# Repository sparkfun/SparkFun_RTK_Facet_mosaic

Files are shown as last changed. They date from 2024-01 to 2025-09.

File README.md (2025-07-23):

SparkPNT RTK Facet mosaic
========================================

SparkPNT RTK Facet mosaic (https://www.sparkfun.com/sparkpnt-rtk-facet-mosaic.html)

[*SparkPNT RTK Facet mosaic (GPS-29688)*](https://www.sparkfun.com/sparkpnt-rtk-facet-mosaic.html)

Designed and manufactured in Boulder, Colorado, USA, and utilizing the multi-band mosaic-X5 from Septentrio, the [SparkPNT RTK Facet mosaic](https://www.sparkfun.com/sparkpnt-rtk-facet-mosaic.html) is *the* top of the line receiver for high precision geolocation and surveying needs. For basic users, it's incredibly easy to get up and running; for advanced users, the RTK Facet mosaic is a flexible and powerful tool. With just the press of a button, the RTK Facet mosaic is the fastest way to take centimeter-grade measurements. With a [subscription to the PointPerfect Flex NTRIP/RTCM service](https://www.sparkfun.com/rtk_facet_mosaic_registration) or any other corrections service, 10mm Real Time Kinematic fixes are less than a minute away. By connecting your phone to the RTK Facet mosaic over Bluetooth®, your phone or tablet can receive the NMEA output and work with most GIS software programs. This is exactly how $10,000 surveying devices have been operating for the past decade - we just made it faster, more precise, and a lot more economical.

The RTK Facet mosaic works with common GIS software for Android and iOS including SW Maps [Android](https://sparkfun.github.io/SparkFun_RTK_Firmware/gis_software/#sw-maps) / [iOS](https://apps.apple.com/us/app/sw-maps/id6444248083), [Field Genius](https://www.microsurvey.com/products/fieldgenius-for-android/), [SurvPC](https://www.carlsonsw.com/product/carlson-survce), [Survey Master](https://docs.sparkfun.com/SparkFun_RTK_Firmware/gis_software/#survey-master), [Vespucci](https://play.google.com/store/apps/details?id=de.blau.android&hl=en_US&gl=US), [QGIS](https://qgis.org/), [QField](https://docs.qfield.org/get-started/), and any GIS software that supports NMEA over Bluetooth.

Under the hood of the SparkPNT RTK Facet mosaic is an ESP32-WROVER-E connected to a mosaic-X5 GNSS multi-band receiver, and a variety of peripheral hardware (LiPo fuel gauge, microSD, etc). Additionally, housed under the dome of the RTK Facet mosaic is a surveyor grade L1/L2/L5 antenna. This antenna is a unique combination of elements designed to receive the GNSS signals (L1/L2/L5). The RTK Facet mosaic is programmed in Arduino and can be tailored by you to fit whatever your needs may be.

This device can be used in five modes:

- GNSS Positioning (~30cm accuracy) - also known as **Rover**
- GNSS Positioning with RTK (1.4cm accuracy) - also known as **Rover with RTK Fix**
- GNSS **Base Station**
- GNSS **Base Station NTRIP Server**

At *Power On* the device will enter **Rover** or **Base** mode; whichever state the device was in at the last power down. When the POWER/SETUP button is pressed momentarily, a menu is presented to change the RTK Facet mosaic from *Rover to Base mode* or vice-versa. The display will indicate the change with a small car *(Rover)* or flag *(Base)* icon.

In **Rover mode** the RTK Facet mosaic will receive `L1`, `L2`, and `L5` GNSS signals from the four constellations (GPS, GLONASS, Galileo, and BeiDou) and calculate the position based on these signals. Similar to a standard grade GPS receiver, the RTK Facet mosaic will output industry standard NMEA sentences at 4Hz and broadcast them over any paired Bluetooth® device. The end user will need to parse the NMEA sentences using commonly available mobile apps, GIS products, or embedded devices (there are many open source libraries). Unlike standard grade GPS receivers that have **2500mm** accuracy, the accuracy in this mode is approximately **300mm** horizontal positional accuracy. When RTCM correction data is sent over Bluetooth® or into the radio port, the device will automatically enter Positioning with RTK mode. In this mode RTK Facet mosaic will receive `L1`/`L2`/`L5` signals from the antenna and correction data from a base station. The receiver will quickly (within a second) obtain an RTK float, then fix. The NMEA sentences will have increased accuracy of 10mm horizontal and 10mm vertical accuracy. The RTCM correction data is most easily obtained over the Internet using a free app on your phone (see our SW Maps *([Android](http://docs.sparkfun.com/SparkFun_RTK_Everywhere_Firmware/gis_software_android/#sw-maps)/[iOS](http://docs.sparkfun.com/SparkFun_RTK_Everywhere_Firmware/gis_software_ios/#sw-maps))* or [Lefebure NTRIP](http://docs.sparkfun.com/SparkFun_RTK_Everywhere_Firmware/gis_software_android/#lefebure) instructions) and sent over Bluetooth® to the RTK Facet mosaic. However, RTCM correction data can also be received over an external cellular or radio link from a 2nd RTK Torch, Postcard, Facet mosaic, Surveyor, Express, etc. that is setup as a base station.

In **Base mode** the device will enter Base Station mode. This is used when the device is mounted to a fixed position (like a tripod or roof). The RTK Facet mosaic will initiate a survey. After 60 to 120 seconds the survey will complete and the RTK Facet mosaic will begin transmitting RTCM correction data out the radio port. A base is often used in conjunction with a second RTK Facet mosaic (or RTK Surveyor, Express, Express Plus, etc) unit set to *Rover* to obtain the 10mm accuracy. Said differently, the Base sits still and sends correction data to the Rover, so that the Rover can output really accurate position data for its location.

In addition to supplying position data, the RTK Facet mosaic is capable of logging NMEA, RAWX, and SFRBX for post processing making it ideal for research and advanced positioning applications.

The RTK Facet mosaic is an open source hardware product meaning you can fully obtain, see, and even modify the electrical and mechanical design files. This allows for easier maintenance and repair over time.

The SparkPNT RTK Facet mosaic kit includes everything you need: the enclosed device, thread adapter, charger, data cables, and carrying case. It does **NOT** include a [surveying pole](https://www.sparkfun.com/telescopic-surveying-pole.html) *(any additional items will need to be purchased separately)*.

> [!IMPORTANT]
> The SparkPNT RTK Facet mosaic is not designed for permanent outdoor mounting. Please use the [RTK mosaic-X5](https://www.sparkfun.com/sparkfun-rtk-mosaic-x5.html) or the [RTK Reference Station](https://www.sparkfun.com/products/22429) that is located inside or protected from the elements. Or, for a DIY solution, the [ESP32](https://www.sparkfun.com/sparkfun-thing-plus-esp32-wroom-micro-b.html) attached to our [ZED-F9P breakout](https://www.sparkfun.com/sparkfun-gps-rtk-sma-breakout-zed-f9p-qwiic.html) is a great way to go. See our [How to Build a DIY GNSS Reference Station](https://learn.sparkfun.com/tutorials/how-to-build-a-diy-gnss-reference-station) tutorial for more information.

> [!NOTE]
> The [RTK Everywhere firmware](https://github.com/sparkfun/SparkFun_RTK_Everywhere_Firmware) is open-source, so users can obtain, check, and even modify the device's functionality. This allows for easier feature expansion, bug maintenance, and longer device longevity.

Documentation
--------------

- **[Hookup Guide (mkdocs)](http://docs.sparkfun.com/SparkFun_RTK_Facet_mosaic/)** - The hookup guide for the SparkPNT RTK Facet mosaic hosted by GitHub pages.<br>
   
- [User Manual - RTK Everywhere Firmware](https://docs.sparkfun.com/SparkFun_RTK_Everywhere_Firmware/) - Documentation for the [RTK Everywhere firmware](https://github.com/sparkfun/SparkFun_RTK_Everywhere_Firmware)

*Need to download or print our hookup guide?*

- [Print *(Print to PDF)* from Single-Page View](http://docs.sparkfun.com/SparkFun_RTK_Facet_mosaic/print_view)

Repository Contents
-------------------

- **[/docs](/docs/)** - Online documentation files
	- [assets](/docs/assets/) - Assets files
		- [3d_model](/docs/assets/3d_model/) - Files for the 3D models
			- [3D CAD Models](/docs/assets/3d_model/step_files.zip) (.step)
		- [board_files](/docs/assets/board_files/) - Files for the product design
			- [KiCad Design Files](/docs/assets/board_files/kicad_files.zip) (.zip)
			- [Schematics](/docs/assets/board_files/schematics.zip) (.pdf)
			<!-- - [Dimensions](/docs/assets/board_files/dimensions.pdf) (.pdf) -->
		- [component_documentation](/docs/assets/component_documentation/) - Datasheets for hardware components
		- [img/hookup_guide/](/docs/assets/img/hookup_guide/) - Images for hookup guide documentation
- **[/Enclosure](/Enclosure/)** - CAD model for an enclosure
- **[/Hardware](/Hardware/)** - Hardware design files (.brd, .sch)
	- **[/Production](/Production/)** - Production files

Product Variants
----------------

- [GPS-24903](https://www.sparkfun.com/sparkpnt-rtk-facet-mosaic-l-band.html) - v1.0, Initial Release
- [GPS-29688](https://www.sparkfun.com/sparkpnt-rtk-facet-mosaic.html) - Rename the product to remove "L-Band" from the name. This is due to u-blox's choice to discontinue the L-Band service to North America starting on December 31st, 2025.

- Facet Product Line
	- [GPS-20000](https://www.sparkfun.com/sparkfun-rtk-facet-l-band.html) - SparkFun RTK Facet L-Band
	- [GPS-19984](https://www.sparkfun.com/sparkfun-rtk-facet.html) - SparkFun RTK Facet
	- [GPS-19029](https://www.sparkfun.com/products/19029) - SparkFun RTK Facet *(Initial Release)*
- mosaic-`XX` GNSS Module
	- [GPS-26289](https://www.sparkfun.com/products/26289) - SparkPNT GNSS Disciplined Oscillator
	- [GPS-23748](https://www.sparkfun.com/sparkfun-rtk-mosaic-x5.html) - SparkFun RTK mosaic-X5
	- [GPS-23088](https://www.sparkfun.com/sparkfun-triband-gnss-rtk-breakout-mosaic-x5.html) - SparkFun Triband GNSS RTK Breakout - mosaic-X5

License Information
-------------------

This product is ***open source***!

Please review the [`LICENSE.md`](./LICENSE.md) file for license information.

If you have any questions or concerns about licensing, please contact technical support on our [SparkFun forums](https://forum.sparkfun.com/viewforum.php?f=152).

Distributed as-is; no warranty is given.

- Your friends at SparkPNT.

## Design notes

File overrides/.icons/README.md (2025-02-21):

.icons directory
====================
This folder should contain branding logos for the product documentation

## General Images
- `sfe.svg` - SparkFun flame logo
- `kicad-primary.svg` - Full KiCad logo

## Directory
- `logo` - Other available logos

## SVG Optimizer
- [Remove meta data from svg](https://jakearchibald.github.io/svgomg/)

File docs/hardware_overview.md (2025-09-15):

---
icon: material/cog
---

The RTK Facet mosaic is a fully enclosed and pre-programmed device. There are very few things to worry about or configure, but we will cover the basics here.

## :material-folder-cog: Design Files
The design of the SparkPNT RTK Facet mosaic is similar to previous generations in our line Facet line of products. However, we have made some modifications to the design to enhance the durability of this product. The PCB design features three separate board components:

- A central board that hosts primary components of the RTK Facet mosaic, such as the ESP32-WROVER-E, mosaic-X5, etc.
- A peripheral board that provides connections to the RTK Facet mosaic
- A display board that is the primary interface for the RTK Facet mosaic

<!-- Import the component -->
<script type="module" src="https://ajax.googleapis.com/ajax/libs/model-viewer/3.5.0/model-viewer.min.js"></script>

<div class="grid cards desc" markdown>

-   Design Files

	---

	- :kicad-primary:{ .enlarge-logo }
		- :material-folder-zip: [Schematics](./assets/board_files/schematics.zip)
			- :fontawesome-solid-file-pdf: [Connector Board](./assets/board_files/schematic-connector_board.pdf)
			- :fontawesome-solid-file-pdf: [Display Board](./assets/board_files/schematic-display_board.pdf)
			- :fontawesome-solid-file-pdf: [Main Board](./assets/board_files/schematic-main_board.pdf)
		- :material-folder-zip: [KiCad Files](./assets/board_files/kicad_files.zip)
			- :material-folder-zip: [Connector Board](./assets/board_files/kicad_files-connector_board.zip)
			- :material-folder-zip: [Display Board](./assets/board_files/kicad_files-display_board.zip)
			- :material-folder-zip: [Main Board](./assets/board_files/kicad_files-main_board.zip)
	- :material-folder-zip: [STEP Files](./assets/3d_model/step_files.zip)
		- :material-cube-outline: [Connector Board](./assets/3d_model/connector_board.step)
		- :material-cube-outline: [Display Board](./assets/3d_model/display_board.step)
		- :material-cube-outline: [Main Board](./assets/3d_model/main_board.step)
	<!-- - :material-rotate-3d: [STEP File](./assets/3d_model/cad_model.zip) -->
	<!-- - :fontawesome-solid-file-pdf: [Board Dimensions](./assets/board_files/dimensions.pdf) -->

-   <!-- Boxes in tabs -->

	=== "Connector Board"
		<article style="margin: auto;" markdown>
		<model-viewer src="../assets/3d_model/connector_board.glb" poster="../assets/3d_model/poster-connector_board.jpeg" camera-controls tone-mapping="neutral" poster="poster.jpeg" shadow-intensity="1.35" exposure="0.6" shadow-softness="0.8" environment-image="legacy" camera-orbit="0.0004711deg 90.01deg 108.5m" field-of-view="25.11deg" style="width: 100%; height: 450px;">
		</model-viewer>
		</article>

	=== "Display Board"
		<article style="margin: auto;" markdown>
		<model-viewer src="../assets/3d_model/display_board.glb" poster="../assets/3d_model/poster-display_board.jpeg" camera-controls tone-mapping="neutral" poster="poster.jpeg" shadow-intensity="1.35" environment-image="legacy" exposure="0.6" shadow-softness="0.8" camera-orbit="-0.0002197deg 89.6deg 101.9m" field-of-view="25.11deg" style="width: 100%; height: 450px;">
		</model-viewer>
		</article>

	=== "Main Board"
		<article style="margin: auto;" markdown>
		<model-viewer src="../assets/3d_model/main_board.glb" poster="../assets/3d_model/poster-main_board.jpeg" camera-controls tone-mapping="neutral" poster="poster.jpeg" camera-controls tone-mapping="neutral" poster="poster.jpeg" shadow-intensity="1.35" camera-orbit="0deg 90deg 110m" field-of-view="25.11deg" environment-image="legacy" exposure="0.6" shadow-softness="0.8" style="width: 100%; height: 450px;">
		</model-viewer>
		</article>

	??? tip "Need Dimensions?"
		For the board dimensions, users can download the [KiCad files](./assets/board_files/kicad_files.zip) for these board. These files can be opened in KiCad and measurements can be made with the measuring tool.

		!!! info ":octicons-download-16:{ .heart } KiCad - Free Download!"
			KiCad is free, open-source [CAD]("computer-aided design") program for electronics. Click on the button below to download their software. *(\*Users can find out more information about KiCad from their [website](https://www.kicad.org/).)*

			<article style="text-align: center;" markdown>
			[Download :kicad-primary:{ .enlarge-logo }](https://www.kicad.org/download/ "Go to downloads page"){ .md-button .md-button--primary width="250px" }
			</article>

		??? info ":straight_ruler: Measuring Tool"
			This video demonstrates how to utilize the dimensions tool in KiCad, to include additional measurements:

			<article class="video-500px" style="text-align: center; margin: auto;" markdown>
			<iframe src="https://www.youtube.com/embed/-eXuD8pkCYw" title="KiCad Dimension Tool" frameborder="0" allow="accelerometer; autoplay; clipboard-write; encrypted-media; gyroscope; picture-in-picture" allowfullscreen></iframe>

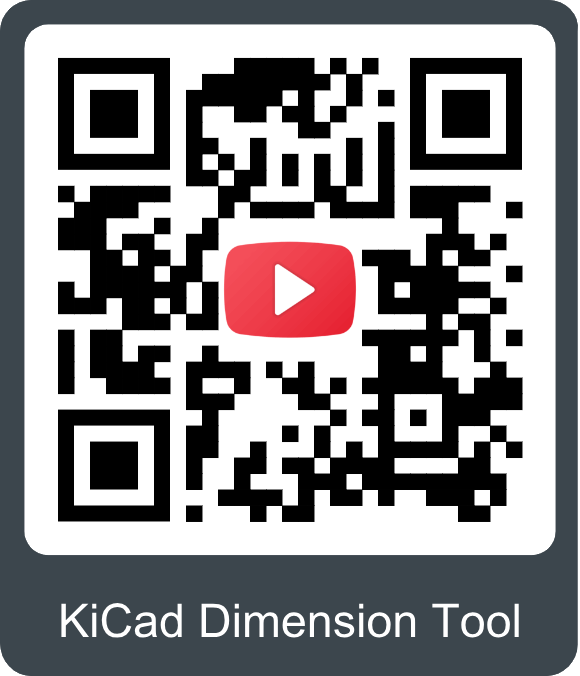
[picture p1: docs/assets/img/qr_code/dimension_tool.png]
QR code to play video
			
			</article>

</div>

## Replacement Parts

??? abstract "Kit Parts"
	<div class="grid cards" markdown>

	-   <a href="https://www.sparkfun.com/sparkpnt-rtk-facet-ruggedized-hardcase.html">
		<figure markdown>
		Product Thumbnail
		</figure>

		---

		**SparkPNT RTK Facet Ruggedized Hardcase**<br>
		PRT-27115</a>

	-   <a href="https://www.sparkfun.com/antenna-thread-adapter-1-4in-to-5-8in.html">
		<figure markdown>
		Product Thumbnail
		</figure>

		---

		**Antenna Thread Adapter - 1/4in. to 5/8in.**<br>
		PRT-17546</a>

	-   <a href="https://www.sparkfun.com/jst-ghr-04v-to-jst-ghr-06v-cable-1-25mm-pitch.html">
		<figure markdown>
		Product Thumbnail
		</figure>

		---

		**JST-GHR-04V to JST-GHR-06V Cable - 1.25mm pitch**<br>
		CAB-17239</a>

	-   <a href="https://www.sparkfun.com/breadboard-to-jst-ghr-04v-cable-4-pin-x-1-25mm-pitch.html">
		<figure markdown>
		Product Thumbnail
		</figure>

		---

		**Breadboard to JST-GHR-04V Cable - 4-Pin x 1.25mm Pitch**<br>
		CAB-17240</a>

	-   <a href="https://www.sparkfun.com/usb-c-to-usb-c-silicone-power-charging-cable-3m.html">
		<figure markdown>
		Product Thumbnail
		</figure>

		---

		**USB-A to USB-C Cable - 3m (Flexible Silicone)**<br>
		CAB-24060</a>

	-   <a href="https://www.sparkfun.com/usb-a-and-c-power-delivery-pd-wall-adapter-65w.html">
		<figure markdown>
		Product Thumbnail
		</figure>

		---

		**USB A and C Power Delivery (PD) Wall Adapter - 65W**<br>
		TOL-24059</a>

	</div>

??? abstract "Internal Components"
	- M2.2-0.98 x 10mm Thread Forming Screws - Phillips Head
	- M3-1.34 x 10mm Thread Forming Screws - Phillips Head

## Power/Setup Button

<figure markdown>
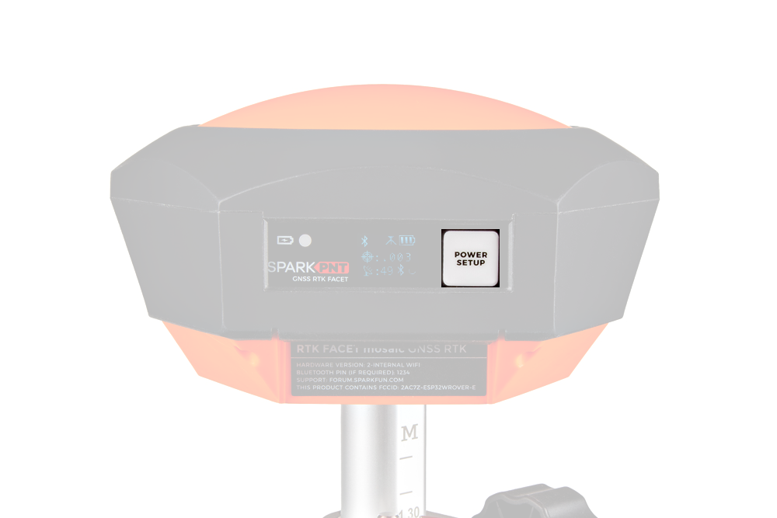
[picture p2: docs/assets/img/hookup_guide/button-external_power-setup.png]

<figcaption markdown>
</figcaption>
The ++"POWER/SETUP"++ button on the front of the RTK Facet mosaic.
</figure>

The RTK Facet mosaic has a ++"POWER/SETUP"++ button to turn the device on/off or for in-field configuration changes.

- Press and hold the button down, to power the RTK Facet mosaic `ON` or `OFF`.
- Short presses of the button will cause the RTK Facet mosaic to change modes. This device can be used in five modes:
	- **Rover**
		- GNSS Positioning (~30cm accuracy) - also known as **Rover**
		- GNSS Positioning with RTK (1.4cm accuracy) - also known as **Rover** *with RTK Fix*
	- **Base**
		- GNSS **Base** Station
		- GNSS **Base** Station *as NTRIP Server*

### Power Switch

<figure markdown>
RTK Facet mosaic startup display with firmware version number (https://cdn.sparkfun.com/assets/learn_tutorials/2/5/8/3/SparkFun_RTK_Facet_L-Band_Boot.jpg)
<figcaption markdown>
The splash screen of RTK Facet mosaic display showing the firmware version number and the device powering off.
</figcaption>
</figure>

The Power button turns the unit on or off:

- Press and hold the power button until the display illuminates.
- Press and hold the power button at any time to turn the unit off.

#### Battery Power

<figure markdown>
RTK Facet mosaic showing the battery level (https://cdn.sparkfun.com/assets/learn_tutorials/1/8/5/7/SparkFun_RTK_Express_-_Display_-_Rover_Fixed.jpg)
<figcaption markdown>
RTK Facet mosaic display, showing the battery level.
</figcaption>
</figure>

The RTK Facet mosaic has a large, built-in 6000mAh lithium polymer battery that will enable over **25 hours** of field use between charging. If more time is needed a common USB power bank can be attached boosting the field time to any amount needed.

!!! info
	For more information, please refer to the [**Internal Batter** section](./hardware_overview.md/#internal-battery)

#### Charge LED

<figure markdown>
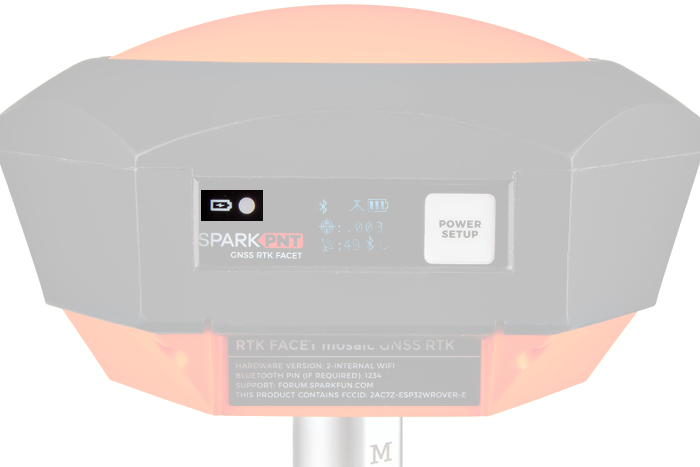
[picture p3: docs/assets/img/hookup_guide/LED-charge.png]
RTK Facet mosaic Charge LED

<figcaption markdown>
Charge LED indicator on the RTK Facet mosaic.
</figcaption>
</figure>

The Charge LED is located on the front face. It will illuminate any time there is an external power source and will turn off when the internal battery is charged. With the unit fully powered down, charging takes approximately **6 hours** from a 1A wall supply or **12 hours** from a standard USB port. The RTK Facet mosaic can run while being charged but it increases the charge time. Using an external USB battery bank to run the device for extended periods or running the device on a permanent wall power source is supported.

### Operation Modes

At *Power On* the device will enter **Rover** or **Base** mode; whichever state the device was in at the last power down. When the ++"POWER/SETUP"++ button is pressed momentarily, a menu is presented to change the RTK Facet mosaic from **Rover** to **Base** mode or vice-versa. The display will indicate the change with a small car :material-van-utility: *(Rover)* or flag :material-flag-checkered: *(Base)* icon.

!!! info "**Rover** Mode"
	In **Rover** mode the RTK Facet mosaic will receive `L1`, `L2`, and `L5` GNSS signals from the four constellations (GPS, GLONASS, Galileo, and BeiDou) and calculate the position based on these signals. Similar to a standard grade GPS receiver, the RTK Facet mosaic will output industry standard NMEA sentences at 4Hz and broadcast them over any paired Bluetooth® device. The end user will need to parse the NMEA sentences using commonly available mobile apps, GIS products, or embedded devices (there are many open source libraries). Unlike standard grade GPS receivers that have **2500mm** accuracy, the accuracy in this mode is approximately **300mm** horizontal positional accuracy.

	- *w/ RTK Fix*

		:	If the device is in **Rover** mode and RTCM correction data is sent over Bluetooth® or into the radio port, the device will automatically enter Positioning with RTK mode. In this mode RTK Facet mosaic will receive `L1`/`L2`/`L5` signals from the antenna; and correction data from a base station. The receiver will quickly (within a second) obtain an RTK float, then fix. The NMEA sentences will have increased accuracy of **10mm** horizontal and **10mm** vertical accuracy.

			1. The RTCM correction data is most easily obtained over the Internet using a free app on your phone (see our SW Maps *([Android](http://docs.sparkfun.com/SparkFun_RTK_Everywhere_Firmware/gis_software_android/#sw-maps)/[iOS](http://docs.sparkfun.com/SparkFun_RTK_Everywhere_Firmware/gis_software_ios/#sw-maps))* or [Lefebure NTRIP](http://docs.sparkfun.com/SparkFun_RTK_Everywhere_Firmware/gis_software_android/#lefebure) instructions) and sent over Bluetooth® to the RTK Facet mosaic.
			2. The RTCM correction data can also be received over an external cellular or radio link from a 2nd RTK Facet, Surveyor, Express, etc. that is setup as a base station.

!!! info "**Base** Mode"
	In **Base** mode the device will enter Base Station mode. This is used when the device is mounted to a fixed position (like a tripod or roof). The RTK Facet mosaic will initiate a survey. After 60 to 120 seconds the survey will complete and the RTK Facet mosaic will begin transmitting RTCM correction data out the radio port. A base is often used in conjunction with a second RTK Facet mosaic (or RTK Surveyor, Express, Express Plus, etc) unit set to *Rover* to obtain the **10mm** accuracy. Said differently, the Base sits still and sends correction data to the Rover; so that the Rover can calculate a really accurate position.

## Connectors

<figure markdown>
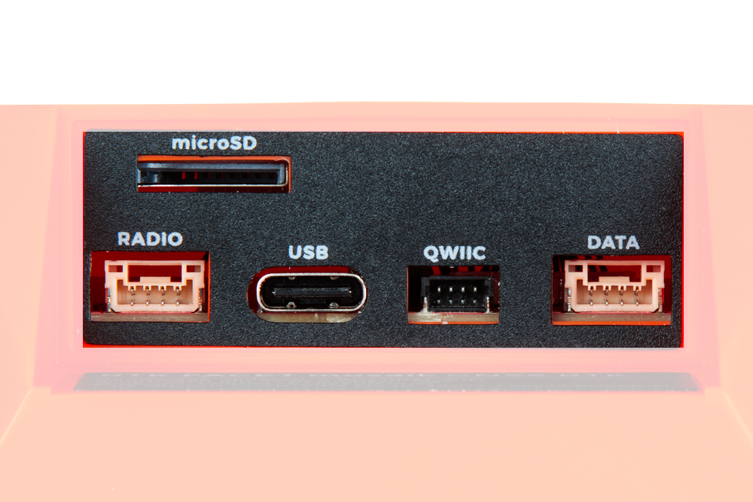
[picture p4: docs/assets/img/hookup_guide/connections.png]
RTK Facet mosaic Connectors

<figcaption markdown>
The SparkFun RTK Facet mosaic connectors shown with the dust cover removed.
</figcaption>
</figure>

There are a variety of connectors protected under a dust flap.

### USB

<figure markdown>
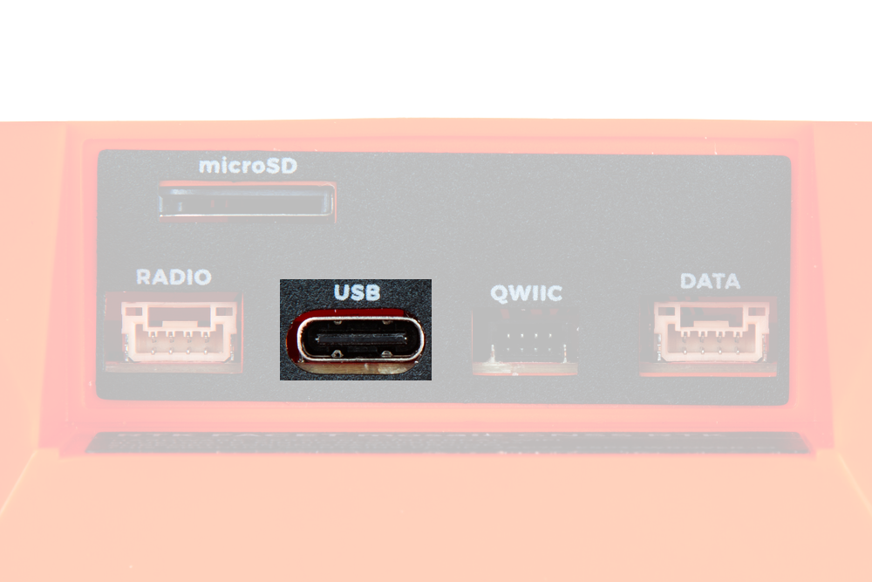
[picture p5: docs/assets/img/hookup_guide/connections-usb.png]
RTK Facet mosaic USB-C Connector

<figcaption markdown>
</figcaption>
</figure>

This USB-C connector is used for four purposes:

* Charging the device
* Configuring the RTK Facet mosaic, and reprogramming the ESP32
* Configuring or updating the firmware of the mosaic-X5 *(as needed)*

There is a USB hub built into the RTK Facet mosaic. When you attach the device to your computer it will enumerate as two COM ports. In the mosaic-X5 firmware, these are named the _USB1_ and _USB2_ COM ports.

<figure markdown>
Two COM ports from one USB device (https://cdn.sparkfun.com/assets/learn_tutorials/2/5/8/3/SparkFun_RTK_Facet_L-Band_Ports.jpg)
<figcaption markdown>
</figcaption>
</figure>

In the image above, the `USB-SERIAL CH340` is the ESP32 and the `USB Serial Device` is the mosaic-X5.

??? tip "Tip - USB Drivers"
	#### CH340 UART Converter
	The CH340 serial-to-USB converter allows users to interface with the ESP32-WROVER-E module through the USB-C connector. To utilize the CH340, users may need to install a USB driver, which can be downloaded from the [manufacturer website](https://www.wch-ic.com/search?q=CH342&t=downloads).

	<div class="grid cards" align="center" markdown>

	-   :material-microsoft-windows: **Windows**

		---

		[:octicons-download-16:{ .heart } Download Page for `CH341SER.EXE`](https://www.wch-ic.com/downloads/CH341SER_EXE.html){ .md-button .md-button--primary target="blank" }

	-   :material-apple: **MacOS**

		---

		[:octicons-download-16:{ .heart } Download Page for `CH34XSER_MAC.ZIP`](https://www.wch-ic.com/downloads/CH34XSER_MAC_ZIP.html){ .md-button .md-button--primary target="blank" }

	</div>

	!!! info ":simple-linux: Linux"
		A USB driver should not be required for most Linux based operating systems; the standard Linux CDC-ACM driver is usually sufficient. However, if necessary, users can try the USB driver below:

		<article style="text-align: center;" markdown>
		[:octicons-download-16:{ .heart } Download Page for `CH341SER_LINUX.ZIP`](https://www.wch-ic.com/downloads/CH341SER_LINUX_ZIP.html){ .md-button .md-button--primary target="blank" }
		</article>

	---

	#### mosaic-X5
	On Windows computers, a USB driver is required to recognize and interact with the mosaic-X5 module through the USB interface.

	<div class="grid cards" markdown>

	-   <article style="text-align: center;" markdown>
		:material-microsoft-windows: **Windows**
		</article>

		---

		The USB driver necessary to recognize and interact with the mosaic-X5 module through the USB interface, can be installed through two methods:

		<article class="annotate" markdown>

		- [RxTools Software Suite](./software_overview.md/#rxtools-software-suite) (1)
		- mosaic-X5 GNSS Receiver Module (2)

		</article>

		1. The driver is installed during the [installation process](./software_overview.md/#rxtools-software-suite).
		2. The installation file for the Windows USB driver will be available from the mass-storage device when the board is initially connected to the computer.

		??? tip "Having Trouble?"
			For users who are having trouble installing the USB driver, we have an archived version *(v3.0.2)* of the installation file. Users can download [**version 3.0.2**](https://docs.sparkfun.com/SparkFun_GNSS_mosaic-X5/assets/component_documentation/driver/USB_driver_3_0_2_Installer.exe) of the driver, by clicking on the button below.

			<article style="text-align: center;" markdown>
			[:octicons-download-16:{ .heart } Download USB Driver *(v3.0.2)*](https://docs.sparkfun.com/SparkFun_GNSS_mosaic-X5/assets/component_documentation/driver/USB_driver_3_0_2_Installer.exe){ .md-button .md-button--primary target="blank" }
			</article>

			!!! note "Latest Driver"
				This driver version was archived at the time that the [mosaic-X5 hookup guide](https://docs.sparkfun.com/SparkFun_GNSS_mosaic-X5/) was written. *Please do not request for the file to be updated.*

				For the latest USB driver from Septentrio, please install their driver through the [RxTools software suite](./software_overview.md/#rxtools-software-suite).

	</div>

	!!! info ":simple-linux: Linux"
		On Linux, the standard Linux CDC-ACM driver is suitable for the mosaic-X5 module.

Configuring the RTK Facet mosaic can be done over the *USB-Serial CH340* COM port via serial text menu. Various debug messages are printed to this port at **115200bps** and a serial menu can be opened to configure advanced settings. The mosaic-X5 can be configured over the *USB Serial Device* port using [web interface](./software_overview.md/#web-interface). It's not necessary in normal operation but is handy for tailoring the receiver to specific applications.

### RADIO

<figure markdown>
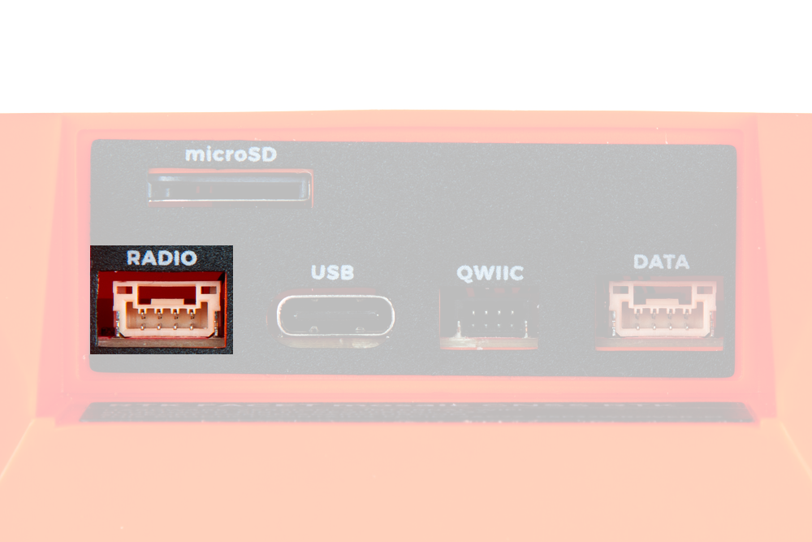
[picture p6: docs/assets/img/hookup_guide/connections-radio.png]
RTK Facet mosaic Radio Connector

<figcaption markdown>
</figcaption>
</figure>

This port is used when an external cellular or radio link is needed. Internally, it is routed to the mosaic-X5 **COM2** UART port. The baud rate is configurable; the default is **57600** baud. This port is *not* used if you transfer RTCM from your phone to the RTK Facet mosaic over Bluetooth.

This 4-pin JST connector can be used to allow RTCM correction data to flow into the device when it is acting as a **Rover** or out of the device when it is acting as a **Base**. The connector is a 4-pin locking 1.25mm JST SMD connector (1). The RTK Facet mosaic comes with a cable to interface to this connector, but [additional cables](https://www.sparkfun.com/products/17239) can be purchased separately.
{ .annotate }

1. 
	- SMD board connector
		- **part#:** SM04B-GHS-TB
	- Mating cable connector
		- **part#:** GHR-04V-S

You will most likely connect one of our [Serial Telemetry Radios](https://www.sparkfun.com/products/19032) to this port, if you don't have access to a correction source on the internet. The pinout is **3.5-5.5V**/`TX`/`RX`/`GND` from left to right as pictured. **3.5V to 5.5V** is provided by this connector to power a radio with a voltage that depends on the power source. If USB is connected to the RTK Facet mosaic then voltage on this port will be **5V** (+/-10%). If running off of the internal battery then voltage on this port will vary with the battery voltage (**3.5V** to **4.2V** depending on the state of charge). This port is capable of sourcing up to **600mA** and is protected by a PTC (resettable fuse). This port should not be connected to a power source.

### DATA

<figure markdown>
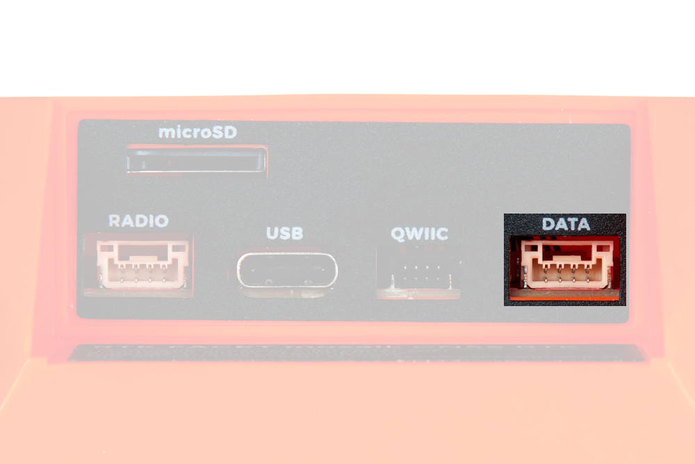
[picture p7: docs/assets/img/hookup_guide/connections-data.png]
RTK Facet mosaic Data Port

<figcaption markdown>
</figcaption>
</figure>

This port is used when an external system is connected such as a rover, car, timing equipment, camera triggers, etc. This port is *not* used if you transfer NMEA positional data to your phone from the RTK Facet mosaic over Bluetooth.

This 4-pin JST connector is used to output and input a variety of data to the RTK Facet mosaic. The connector is a 4-pin locking 1.25mm JST SMD connector (1). The RTK Facet mosaic comes with a cable to interface to this connector, but [additional cables](https://www.sparkfun.com/products/17240) can be purchased separately.
{ .annotate }

1. 
	- SMD board connector
		- **part#:** SM04B-GHS-TB
	- Mating cable connector
		- **part#:** GHR-04V-S

Internally, the Data connector is connected to a digital mux allowing one of four software selectable setups. See the [Ports Menu](https://docs.sparkfun.com/SparkFun_RTK_Firmware/menu_ports/) for a description of each option.:

- **NMEA** - The `TX` pin outputs any enabled messages (NMEA and RTCM) at a default of **230400** baud (configurable 9600 to 921600bps). The `RX` pin can receive RTCM messages for an RTK fix. Internally, `TX` and `RX` are routed to the mosaic-X5 **COM3** UART port.
- **PPS/Trigger** - The `TX` pin outputs the pulse-per-second signal that is accurate to 30ns RMS. The `RX` pin is connected to the `EVENTA` pin on the mosaic-X5, allowing for events to be measured with incredibly accurate nano-second resolution. Useful for things like audio triangulation.
- **I^2^C** - The `TX` pin operates as `SCL`, `RX` pin as `SDA` on the I^2^C bus. This allows additional sensors to be connected to the I2C bus.
- **GPIO** - The `TX` pin operates as a DAC capable `GPIO 21` on the ESP32. The `RX` pin operates as a ADC capable input (`GPIO39`) on the ESP32. This is useful for custom applications.

Most applications do not need to utilize this port and will send the NMEA position data over Bluetooth. This port can be useful for sending position data to an embedded microcontroller or single board computer. The pinout is **3.3V**/`TX`/`RX`/`GND`. **3.3V** from left to right as pictured, which is provided by this connector to power a remote device if needed. While the port is capable of sourcing up to **600mA**, we do not recommend more than **300mA**. This port should not be connected to a power source.

### microSD

<figure markdown>
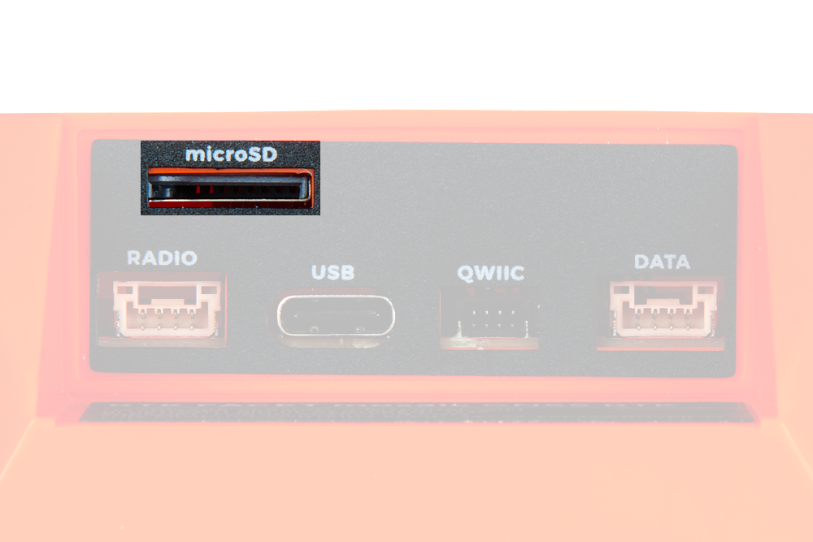
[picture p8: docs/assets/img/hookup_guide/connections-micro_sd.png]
RTK Facet mosaic microSD connector

</figcaption>
</figure>

This slot accepts standard microSD cards up to 32GB formatted for `FAT32`.

The following messages are supported for logging:

<div class="grid" style="grid-template-columns: repeat(auto-fit,minmax(8rem,1fr));" markdown>

<div markdown>
- NMEA-ALM
- NMEA-AVR
- NMEA-DTM
- NMEA-GBS
- NMEA-GFA
- NMEA-GGA
- NMEA-GGK
- NMEA-GGQ
- NMEA-GLL
- NMEA-GMP
- NMEA-GNS
- NMEA-GRS
- NMEA-GSA
- NMEA-GST
- NMEA-GSV
- NMEA-HDT
- NMEA-HRP
- NMEA-LLK
- NMEA-LLQ
- NMEA-RBD
</div>

<div markdown>
- NMEA-RBP
- NMEA-RBV
- NMEA-RMC
- NMEA-ROT
- NMEA-SNC
- NMEA-TFM
- NMEA-THS
- NMEA-TXTbase
- NMEA-VTG
- NMEA-ZDA
- RTCM3-1001
- RTCM3-1002
- RTCM3-1003
- RTCM3-1004
- RTCM3-1005
- RTCM3-1006
- RTCM3-1007
- RTCM3-1108
- RTCM3-1009
- RTCM3-1010
</div>

<div markdown>
- RTCM3-1011
- RTCM3-1012
- RTCM3-1013
- RTCM3-1019
- RTCM3-1020
- RTCM3-1029
- RTCM3-1033
- RTCM3-1042
- RTCM3-1044
- RTCM3-1045
- RTCM3-1046
- MSM1
- MSM2
- MSM3
- MSM4
- MSM5
- MSM6
- MSM7
- RTCM3-1230
</div>

</div>

### Qwiic

<figure markdown>
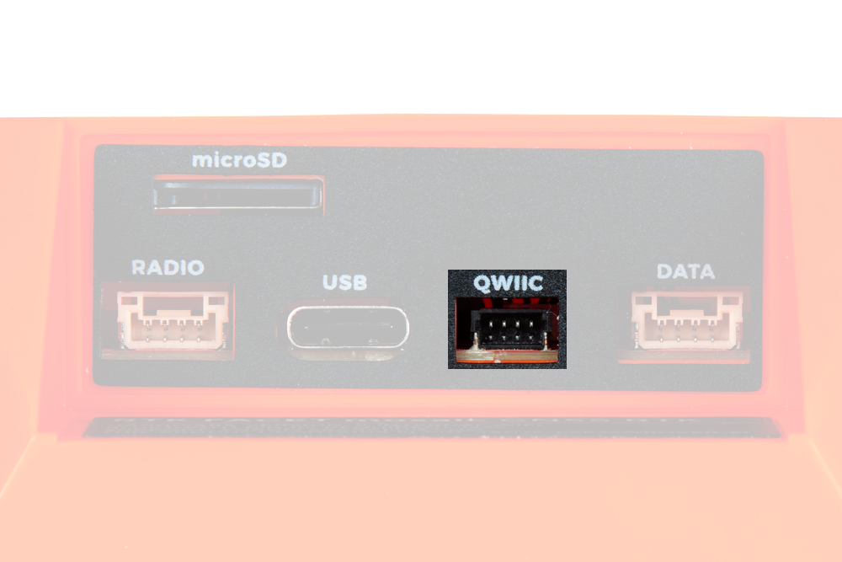
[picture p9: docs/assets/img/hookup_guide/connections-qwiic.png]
RTK Facet mosaic Qwiic connector

<figcaption markdown>
</figcaption>
</figure>

This 4-pin [Qwiic connector](https://www.sparkfun.com/qwiic) exposes the I^2^C bus of the ESP32-WROVER-E module. Currently, there is no firmware support for adding I^2^C devices to the RTK Facet mosaic, but support may be added in the future.

### Antenna

<figure markdown>
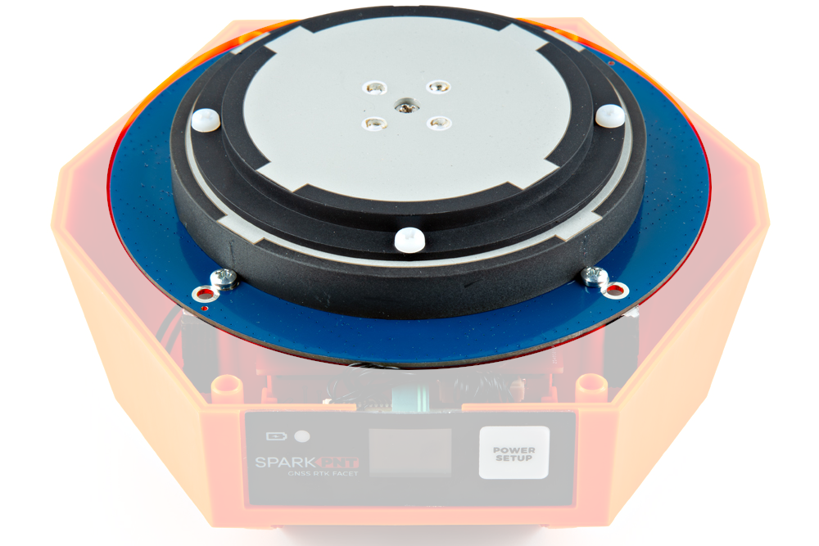
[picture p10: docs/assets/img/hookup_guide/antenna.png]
Internal RTK Facet mosaic Antenna

<figcaption markdown>
</figcaption>
</figure>

It's built in! Housed under the dome of the RTK Facet mosaic is a surveyor grade L1/L2/L5 antenna. This antenna is a unique combination of elements designed to receive the GNSS signals (L1/L2/L5).

<figure markdown>
SparkFun RTK Facet mosaic Antenna Reference Point (https://cdn.sparkfun.com/assets/learn_tutorials/2/5/8/3/SparkFun_RTK_Facet_L-Band_ARP.jpg)
<figcaption markdown>
SparkFun RTK Facet mosaic Antenna Reference Points
</figcaption>
</figure>

The built-in antenna has an antenna phase center (APC) of 69mm from the base of the device to the measuring point of the L1 antenna and an APC of 68mm to the measuring point of the L2 antenna.

## Internal Battery

<figure markdown>
RTK Facet mosaic Display showing three battery bars (https://cdn.sparkfun.com/assets/learn_tutorials/1/8/5/7/SparkFun_RTK_Express_-_Display_-_Rover_RTK_Fixed.jpg)
<figcaption markdown>
RTK Facet mosaic Display showing three battery bars
</figcaption>
</figure>

The RTK Facet mosaic has a built in **6000mAh** battery and consumes approximately **240mA** worst case with Bluetooth connection active and GNSS fully tracking. This will allow for around *25 hours* of use in the field. If more time is needed in the field a standard USB power bank can be attached. If a *10,000mAh* bank is attached one can estimate *56 hours* of run time; assuming, 25% of the capacity is lost to efficiencies of the power bank and charge circuit within RTK Facet mosaic.

The RTK Facet mosaic can be charged from any USB port or adapter. The charge circuit is rated for 1000mA, so USB 2.0 ports will charge at **500mA** and USB 3.0+ ports will charge at **1A**.

To quickly view the state of charge, turn on the unit. The battery icon will indicate the following:

- 3 bars: >75% capacity remain
- 2 bars: >50% capacity remain
- 1 bar: >25% capacity remain
- 0 bars: <25% capacity remain

## Display

<figure markdown>
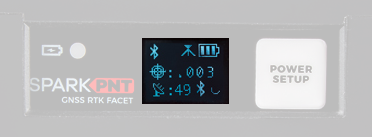
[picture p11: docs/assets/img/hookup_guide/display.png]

<figcaption markdown>
</figcaption>
The display on the front of the RTK Facet mosaic.
</figure>

The RTK Facet mosaic has a 0.96" high-contrast OLED display. While small, it packs various situational data that can be helpful in the field. Please see the [SparkFun RTK Everywhere Firmware Manual](https://sparkfun.github.io/SparkFun_RTK_Firmware/displays/) for a description of the information being displayed.

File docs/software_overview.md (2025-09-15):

---
icon: fontawesome/solid/computer
---

## USB Drivers

### :espressif: ESP32 *(CH340)*
In order to interface with the ESP32 module, the USB driver for the CH340 USB-to-Serial converter must be installed. Users can be download the USB driver from the [manufacturer's website](https://www.wch-ic.com/search?q=CH340&t=downloads):

<div class="grid cards" align="center" markdown>

-   :material-microsoft-windows: **Windows**

	---

	[:octicons-download-16:{ .heart } Download Page for `CH341SER.EXE`](https://www.wch-ic.com/downloads/CH341SER_EXE.html){ .md-button .md-button--primary target="blank" }

-   :material-apple: **MacOS**

	---

	[:octicons-download-16:{ .heart } Download Page for `CH34XSER_MAC.ZIP`](https://www.wch-ic.com/downloads/CH34XSER_MAC_ZIP.html){ .md-button .md-button--primary target="blank" }

</div>

!!! info ":simple-linux: Linux"
	A USB driver should not be required for most Linux based operating systems; the standard Linux CDC-ACM driver is usually sufficient. However, if necessary, users can try the USB driver below:

	<article style="text-align: center;" markdown>
	[:octicons-download-16:{ .heart } Download Page for `CH341SER_LINUX.ZIP`](https://www.wch-ic.com/downloads/CH341SER_LINUX_ZIP.html){ .md-button .md-button--primary target="blank" }
	</article>

### :septentrio: mosaic-X5
In order to interface with the mosaic-X5 on Windows computers, a USB driver must be installed.

<div class="grid cards" markdown>

-   <article style="text-align: center;" markdown>
	:material-microsoft-windows: **Windows**
	</article>

	---

	The USB driver for the mosaic-X5 module can be installed through two methods:

	<article class="annotate" markdown>

	- [RxTools Software Suite](software_overview.md/#rxtools-software-suite) (1)
	- mosaic-X5 GNSS Receiver Module (2)

	</article>

	1. The driver is installed during the [installation process](software_overview.md/#rxtools-software-suite).
	2. The installation file for the Windows USB driver will be available from the mass-storage device when the board is initially connected to the computer.

	??? tip "Having Trouble?"
		For users who are having trouble installing the USB driver, we have an archived version *(v3.0.2)* of the installation file. Users can download [**version 3.0.2**](https://docs.sparkfun.com/SparkFun_GNSS_mosaic-X5/assets/component_documentation/driver/USB_driver_3_0_2_Installer.exe) of the driver, by clicking on the button below.

		<article style="text-align: center;" markdown>
		[:octicons-download-16:{ .heart } Download USB Driver *(v3.0.2)*](https://docs.sparkfun.com/SparkFun_GNSS_mosaic-X5/assets/component_documentation/driver/USB_driver_3_0_2_Installer.exe){ .md-button .md-button--primary target="blank" }
		</article>

		!!! note "Latest Driver"
			This driver version was archived at the time that the [mosaic-X5 hookup guide](https://docs.sparkfun.com/SparkFun_GNSS_mosaic-X5/) was written. *Please do not request for the file to be updated.*

			For the latest USB driver from Septentrio, please install their driver through the [RxTools software suite](software_overview.md/#rxtools-software-suite).

</div>

!!! info ":simple-linux: Linux"
	On Linux, the standard Linux CDC-ACM driver is suitable for the mosaic-X5 module.

## :espressif: ESP32

### Terminal Emulator
In order to configure the WiFi settings on the ESP32, users will need to install a [terminal emulation program](https://learn.sparkfun.com/tutorials/112) on their computer.

=== "Windows"
	For Windows computers, we highly recommend [TeraTerm](https://teratermproject.github.io/index-en.html).

=== "Linux"
	Some Linux operating systems will already have the `screen` terminal emulator preinstalled.

!!! abstract "Need Directions?"
	Check out our hookup guide to install your favorite terminal emulator:

	<div class="grid cards" markdown align="center">

	-   <a href="https://learn.sparkfun.com/tutorials/112">
		<figure markdown>
		Tutorial Thumbnail
		</figure>

		---

		**Serial Terminal Basics**</a>

	</div>

### RTK Everywhere Firmware

#### System Configuration
Out of the box, the SparkFun RTK products are exceptional GNSS receivers out-of-box and can be used with little or no configuration. Additionally, the line of RTK products from SparkFun are immensely configurable. Please see the [SparkFun RTK Everywhere Firmware Manual](http://docs.sparkfun.com/SparkFun_RTK_Everywhere_Firmware) for detailed descriptions of all the available features on the RTK products

#### Firmware Updates and Customization
The RTK Facet mosaic is completely open-source meaning you have total access to the [firmware code](https://github.com/sparkfun/SparkFun_RTK_Everywhere_Firmware) and [hardware designs](https://github.com/sparkfun/SparkFun_RTK_Facet_mosaic).

From time to time SparkFun will release new firmware for the RTK product line to add and improve functionality. We've made updating the firmware as easy as possible. Please see [Updating RTK Firmware](http://docs.sparkfun.com/SparkFun_RTK_Everywhere_Firmware/firmware_update/) for a step by step tutorial.

#### Bluetooth and NTRIP
The RTK Facet mosaic transmits full NMEA sentences over Bluetooth serial port profile (SPP) at 4Hz and 115200bps. This means that nearly any GIS application that can receive NMEA data over serial port (almost all do) can be used with the RTK Facet mosaic. As long as your device can open a serial port over Bluetooth (also known as SPP) your device can retrieve industry standard NMEA positional data.

Please see the [SparkFun RTK Everywhere Firmware Manual](http://docs.sparkfun.com/SparkFun_RTK_Everywhere_Firmware/connecting_bluetooth/) for step by step instructions.

## :septentrio: mosaic-X5

### :fontawesome-solid-computer: RxTools Software Suite
Even if you aren't necessarily interested in it, we highly recommend that users install the [RXTools software suite](https://www.septentrio.com/en/products/gps-gnss-receiver-software/rxtools) before connecting to the mosaic-X5. For Windows PCs, it also includes the USB driver for the module that enables the Ethernet-over-USB support and virtual `COM` ports.

<article style="text-align: center;" markdown>
[:octicons-download-16:{ .heart } Download the RxTools Software from Septentrio](https://www.septentrio.com/en/products/gps-gnss-receiver-software/rxtools){ .md-button .md-button--primary target="blank" }
</article>

??? info "System Requirements[^1]"

	=== "Operating Systems"

		* Windows 7
		* Windows 8
		* Windows 10
		* Fedora 23 *(or later)* using Qt technology.
			* The standalone tools (except `bin2asc`) will run on older distributions.

	=== "Hardware Requirements"
		The minimal hardware requirements *(1Hz update[^2])*:

		* CPU: 1 GHz processor
		* RAM: 1 GB RAM
		* Screen Resolution: 1024×768 or higher resolution

???+ info "Installation Instructions[^1]"

	=== "Windows"
		Users can install RxTools software suite by running the installation executable[^3](1), located in the `RxTools\windows` directory of the downloaded `*.zip` file[^4]. During the installation process, users will be notified if a previous version of RxTools is already installed then the previous version will be uninstalled. Next, users will need to provide an installation directory for the RxTools software suite. Users will then select which of the following applications[^5] are installed:
		{ .annotate }

		1. For RxTools v22.1.0, the installation filename is `RxTools_22_1_0_Installer.exe` for Windows PCs.

		<!-- Create Break from Annotation (list won't render without comment)-->

		<div class="grid" markdown>

		<div markdown>

		* RxControl
		* SBF Converter
		* SBF Analyzer
		* RxLogger

		</div>

		<div markdown>

		* RxUpgrade
		* RxDownload
		* RxPlanner

		</div>

		<div markdown>

		* Data Link
		* RxAssistant
		* RxLauncher

		</div>

		</div>

	=== "Linux[^1]"
		!!! warning
			It is recommended that users **<span style="color:red">NOT</span>** install RxControl as `root`, for security reasons and to avoid installation overwrites of other system settings. To make RxTools available to more than one user, provide a shared installation directory.

		Users can install RxTools software suite by running the installation binary[^3](1), located in the `RxTools/linux-i386/` directory of the downloaded `*.zip` file[^4]. During the installation, users will be prompted for an installation directory. If there are any previous installations of RxControl, please use a different directory to avoid conflicts.
		{ .annotate }

		1. For RxTools v22.1.0, the installation filename is `RxTools_22_1_0_Installer.bin` for Linux.

		??? info "Permission Settings"
			Once installed, users may need to reconfigure their permission settings:

			<div class="annotate" markdown>

			* RxTools will need rights to access the `/dev/ttyS*` serial ports.

				* To access the serial ports, users must be part of the `uucp` and `lock` groups (1). This can be configured by editing the `/etc/group`[^6] file and adding the username to the lines defining the `uucp` group and the `lock` group.

					For example, when adding the user `jsmith` to the `uucp` group, users would modify the `/etc/group` file as shown below:

					```bash
					{--uucp:x:14:uucp--} # (2)!
					{++uucp:x:14:uucp,jsmith++} # (3)!
					```

				* On Linux machine administered centrally on a local network, ask your system administrator to be included in the `uucp` and `lock` groups.
			* RxTools also needs read/write (`rw`) access(4) to the `/dev/ttyS*` serial ports.

				* Users can change the permissions with the `chmod`[^7] command:

					```bash
					chmod 660 /dev/ttyS<add port> # (5)!>
					```

			</div>

			1. On most Linux operating systems, the `/dev/ttyS*` devices are owned by `root` and belong to the `uucp` group with read/write (`rw`) access. Additionally, the devices are normally locked by writing a file in the `/var/lock/` directory, with the same permissions.
			2. Remove
			3. Replace with this line
			4. By default, users will normally have read/write (`rw`) access to the `/dev/ttyS*` serial ports.
			5. where users must specify the port number<br>*e.g. `/dev/ttyS0` might be port `COM1`*

			!!! note
				In order for these changes to take effect, users must update their environment by logging out and back in.

				Be aware that the X-session has to be restarted as well. On most systems, this can be done by pressing the key combination ++ctrl++ + ++alt++ + ++backspace++

		??? info "64-bit OS"
			In order to run the RxTools on a 64-bit Linux operating system, users might have to install the 32-bit version of the `C` standard library.

			* For Fedora installations, this is the `glibc.i686` package.
			* The equivalent for Debian(/Ubuntu) installations is the `ia32-libs` package.

[^1]: The system requirements and installation instructions are from the RxTools *v22.1.0* user manual. This information may change in later iterations of the software suite. Please refer to the user manual *(of the version you are utilizing)* for the most accurate information.
[^2]: Higher data rates will require higher CPU speed and more memory capacity.
[^3]: Users will need administrative privileges to install the RxTools software.
[^4]: Users may need to extract the RxTools installation files from the downloaded, compressed file.
[^5]: Please see the release notes for the issues and limitations of the RxTools applications.
[^6]: Requires `c` privileges.
[^7]: Changing these permissions also requires `root` privileges.

### :material-web: Web Interface
With the USB driver installed, the mosaic-X5 module supports Ethernet-over-USB. The default IP address allocated for the Ethernet-over-USB interface is `192.168.3.1`. This IP can be entered in any browser to open a connection to the receiver's Web Interface as shown below.

<div class="grid" markdown>

<div markdown>

<figure markdown>
navigation tabs in the web interface (https://docs.sparkfun.com/SparkFun_GNSS_mosaic-X5/assets/img/hookup_guide/navigation_tabs.png "Click to enlarge")
<figcaption markdown>All the drop-down navigation tabs in the web interface.</figcaption>
</figure>

</div>

<div markdown>

<article class="video-500px" style="margin: auto;" markdown>
<iframe src="https://www.youtube.com/embed/hrL5J6Q5gX8" title="Septentrio: Getting started with the Septentrio mosaic receiver module" frameborder="0" allow="accelerometer; autoplay; clipboard-write; encrypted-media; gyroscope; picture-in-picture" allowfullscreen></iframe>
</article>

</div>

</div>

!!! info
	The default IP address cannot be changed; this feature is only to be used when a single receiver is connected to your computer.

## :fontawesome-solid-computer: PyGPSClient
As an alternative to GIS apps on mobile devices, for users with computers, we recommend [PyGPSClient](https://github.com/semuconsulting/PyGPSClient) as an option for viewing the data from the NMEA messages and connecting to an NTRIP caster. However, users should be aware that this GUI interface is currently limited to only receiving UART messages and cannot send messages to configure the mosaic-X5 GNSS module.

!!! warning "Software Limitations"
	With this software, users will only be able to view the data from the NMEA messages and connect to an NTRIP caster. Users will not be able to configure the mosaic-X5 GNSS module with the built-in console.

??? info "Resources"
	For additional information, users can refer to the following resources for the PyGPSClient software:

	- :material-github: [GitHub Repository](https://github.com/semuconsulting/PyGPSClient)
	- [Installation Instructions](https://github.com/semuconsulting/PyGPSClient?tab=readme-ov-file#installation)
	- [PyPI Project](https://pypi.org/project/pygpsclient/)

#### Installation
There are a variety of [installation methods](https://github.com/semuconsulting/PyGPSClient?tab=readme-ov-file#installation) detailed in the GitHub repository's `README.md` file. However, we recommend utilizing the `pip` installation method. Depending on how Python is installed on your computer, one of the following commands should allow users to install the software.

!!! terminal "Installation Commands"
	```bash
	python3 -m pip install pygpsclient
	```
	```bash
	pip install pygpsclient
	```

	!!! tip
		This installation method requires an internet connection. Additionally, users will also need administrative privileges *(or root access `sudo`)* for the installation.

#### Connecting to the mosaic-X5
Before users can connect to the SparkPNT RTK Facet mosaic, they will need to specify the settings of the UART port in PyGPSClient. Once configured, users can select the <kbd>:material-usb:</kbd> button and PyGPSClient will automatically attempt to connect to the GNSS module.

- Below, is a list of the default settings for `UART` port of the SparkPNT RTK Facet mosaic. These settings should be selected in the configuration menu.

<div class="grid" markdown>

<div markdown>

<figure markdown>
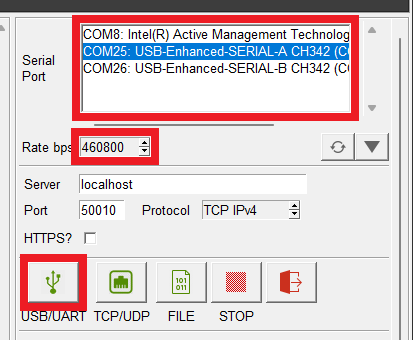
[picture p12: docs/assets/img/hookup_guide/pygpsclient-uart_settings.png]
UART Settings in PyGPSClient

<figcaption markdown>
Specify the settings for the UART port in QGNSS.
</figcaption>
</figure>

</div>

<div markdown>

!!! info "Default Settings"
	The UART port of the RTK Facet mosaic will have the following default configuration:

	- Baudrate: 115200bps
	- Data Bits: 8
	- Parity: No
	- Stop Bits: 1
	- Flow Control: None

</div>

</div>

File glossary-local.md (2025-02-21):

<!-- Local - Specific to ONLY this Documentation -->
<!-- ------------------------------------------- -->

*[BT SPP]: Bluetooth Serial Port Profile
*[EN]: Enable
*[FSP]: Flexible Software Package
*[esri]: Environmental Systems Research Institute, Inc.

<!-- ------------------------------------------- -->
<!-- -------------- End of Local --------------- -->

<!-- ------------ Standard Entries ------------- -->
<!-- ------------------------------------------- -->

*[GEO]: Geostationary Orbit
<!-- *[GEO]: Geosynchronous Equatorial Orbit -->
*[I2C]: Inter-Integrated Circuit
<!-- *[I<sup>2</sup>C]: Inter-Integrated Circuit -->
*[LiPo]: Lithium-Ion Polymer
<!-- *[LiPo]: Lithium-Polymer -->
<!-- *[MPU]: Microprocessing Unit -->
*[MPU]: Memory Protection Unit

<!-- ------------------------------------------- -->
<!-- --------- End of Standard Entries --------- -->

<!-- ------------------ Units ------------------ -->
<!-- ------------------------------------------- -->

<!-- *[Hz]: Hertz -->
<!-- *[MHz]: Megahertz -->
<!-- *[GHz]: Gigahertz -->

<!-- *[mm]: millimeters -->
<!-- *[km]: kilometers -->
<!-- *[in]: inches -->
<!-- *[ft]: feet -->
<!-- *[yrd]: yards -->
<!-- *[mi]: miles -->

<!-- *[Pa]: Pascals -->

<!-- *[°C]: Degrees Celsius -->
<!-- *[°F]: Degrees Fahrenheit -->

<!-- *[pA]: Picoamp -->
<!-- *[nA]: Nanoamp -->
<!-- *[µA]: Microamp -->
<!-- *[mA]: Milliamp -->

<!-- *[µV]: Microvolt -->
<!-- *[mV]: Millivolt -->

<!-- --------------- End of Units -------------- -->
<!-- ------------------------------------------- -->

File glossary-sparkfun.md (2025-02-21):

*[µSD]: micro SD

*[ADC]: Analog-to-Digital Converter
*[ASK]: Amplitude-Shift Keying
*[AREF]: Analog Reference Voltage
*[BDS]: 北斗卫星导航系统 (Chinese - BeiDou Navigation Satellite System)
*[BPSK]: Binary Phase-Shift Keying
*[BSP]: Board Software/Support Package
*[BLE]: Bluetooth Low-Energy
*[CAN]: Controller Area Network
*[CORS]: Continuously Operating Reference Station
*[CPU]: Central Processing Unit
*[CRC]: Cyclic Redundancy Check
*[CS]: Chip Select
*[CTS]: Clear-to-Send
*[DAC]: Digital-to-Analog Converter
*[DFU]: Device Firmware Update
*[DGPS]: Differential Global Positioning System
*[ECC]: Error Correction Code
*[exFAT]: Extensible File Allocation Table
*[FAT]: File Allocation Table
<!-- *[FAT16]: File Allocation Table-16 -->
<!-- *[FAT32]: File Allocation Table-32 -->
*[FSK]: Frequency-Shift Keying
<!-- *[GEO]: Geostationary Orbit or Geosynchronous Equatorial Orbit (see glossary-alt.md) -->
*[GFSK]: Gaussian Frequency Shift Keying
*[GIS]: Geographic Information System
*[GLONASS]: Глобальная Навигационная Спутниковая Система (Russian - Global Navigation Satellite System)
*[GND]: Ground
*[GNSS]: Global Navigation Satellite System
*[GPIO]: General Purpose Input and Output
*[GPS]: Global Positioning System
*[GSO]: Geosynchronous Orbit
*[HAL]: Hardware Abstraction Layer
<!-- *[I2C] or [I<sup>2</sup>C]: Inter-Integrated Circuit (see glossary-alt.md) -->
*[ITM]: Instrumentation Trace Macrocell
*[IoT]: Internet of Things
*[JST]: Japan Solderless Terminal (Manufacturing)
*[JTAG]: Joint Test Action Group
*[LDO]: Low Dropout (Regulator)
*[LED]: Light Emitting Diode
*[LEO]:  Low Earth Orbit
<!-- *[LiPo]: Lithium-Ion Polymer or Lithium-Polymer (see glossary-alt.md) -->
*[LoRa]: Long Range
*[LoRaWAN]: Long Range Wide Area Network
*[MCU]: Microcontroller Unit
*[MEO]:  Medium Earth Orbit
*[MISO]: Master In Slave Out
*[MOSI]: Master Out Slave In
<!-- *[MPU]: Memory Protection Unit or Microprocessing Unit (see glossary-alt.md) -->
*[NavIC]: Navigation with Indian Constellation
*[NMEA]: National Marine Electronics Association
*[NiCd]: Nickel-Cadmium
*[NiMH]: Nickel-Metal Hydride
*[NTFS]: New Technology File System
*[NTRIP]: Networked Transport of RTCM via Internet Protocol
*[PCB]: Printed Circuit Board
*[PICO]: Peripheral In; Ccontroller Out
*[POCI]: Peripheral Out; Controller In
*[PSK]: Phase-Shift Keying
*[PSRAM]: Pseudo-Static RAM 
*[PWM]: Pulse Width Modulation
*[QSPI]: Quad-SPI
*[QPSK]: Quadrature Phase-Shift Keying
*[QZSS]: Quasi-Zenith Satellite System
*[RAM]: Random-Access Memory
*[RGB]: Red, Green, Blue
*[RINEX]: Receiver Independent Exchange (Format)
*[RST]: Reset
*[RTC]: Realtime Clock
*[RTCM]: Radio Technical Commission for Maritime (Services)
*[RTK]: Real-Time Kinematic (Positioning)
*[RTS]: Ready-to-Send
*[RX]: Receive
*[SBAS]: Satellite-Based Augmentation System
*[SCK]: Serial Clock
*[SCL]: Serial Clock
*[SD]: Secure Digital
*[SDA]: Serial Data
*[SDHC]: Secure Digital High Capacity
*[SDI]: Serial Data In
*[SDIO]: Serial Data In/Out
*[SDO]: Serial Data Out
*[SDUC]: Secure Digital Ultra Capacity
*[SDXC]: Secure Digital Extended Capacity
*[SPI]: Serial Peripheral Interface
*[SRAM]: Static Random-Access Memory
*[SS]: Slave Select
*[SWCLK]: Serial Wire Clock
*[SWD]: Serial Wire Debug
*[SWDIO]: Serial Wire Data Input/Output
*[SWO]: Serial Wire Output
*[SWV]: Serial Wire Viewer
*[TCK]: Test Clock
*[TDI]: Test Data In
*[TDO]: Test Data Out
*[TMS]: Test Mode Select
*[TRST]: Test Reset
*[TX]: Transmit
*[UART]: Universal Asynchronous Receiver-Transmitter
*[USB]: Universal Serial Bus
*[WDT]: Watchdog Timer

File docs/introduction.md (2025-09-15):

---
icon: material/book-open-page-variant
---

# Introduction
<div class="grid cards desc" markdown>

-   <a href="https://www.sparkfun.com/sparkpnt-rtk-facet-mosaic.html">
	**SparkPNT RTK Facet mosaic**<br>
	**SKU:** GPS-29688

	---

	<figure markdown>
	
	Product Thumbnail
	</figure></a>

	<article class="video-500px" style="text-align: center; margin: auto;" markdown>
	<iframe src="https://www.youtube.com/embed/e3OKRtJDPgw" title="Product Showcase Video" frameborder="0" allow="accelerometer; autoplay; clipboard-write; encrypted-media; gyroscope; picture-in-picture" allowfullscreen></iframe>
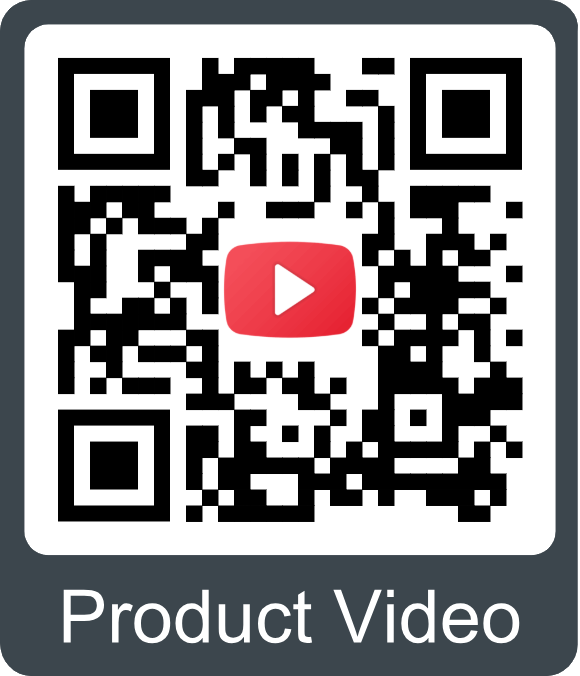
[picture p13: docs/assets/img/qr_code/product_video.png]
QR code to product video
	
	</article>

-	Designed and manufactured in Boulder, Colorado, USA, and utilizing the multi-band mosaic-X5 from Septentrio, the [SparkPNT RTK Facet mosaic](https://www.sparkfun.com/sparkpnt-rtk-facet-mosaic.html) is *the* top of the line receiver for high precision geolocation and surveying needs. For basic users, it's incredibly easy to get up and running; for advanced users, the RTK Facet mosaic is a flexible and powerful tool. With just the press of a button, the RTK Facet mosaic is the fastest way to take centimeter-grade measurements. With a [subscription to the PointPerfect Flex NTRIP/RTCM service](https://www.sparkfun.com/rtk_facet_mosaic_registration) or any other correction service, 10mm Real Time Kinematic fixes are less than a minute away. By connecting your phone to the RTK Facet mosaic over Bluetooth®, your phone or tablet can receive the NMEA output and work with most GIS software programs. This is exactly how $10,000 surveying devices have been operating for the past decade - we just made it faster, more precise, and a lot more economical.

	The RTK Facet mosaic works with common GIS software for Android and iOS including SW Maps [Android](https://sparkfun.github.io/SparkFun_RTK_Firmware/gis_software/#sw-maps) / [iOS](https://apps.apple.com/us/app/sw-maps/id6444248083), [Field Genius](https://www.microsurvey.com/products/fieldgenius-for-android/), [SurvPC](https://www.carlsonsw.com/product/carlson-survce), [Survey Master](https://docs.sparkfun.com/SparkFun_RTK_Firmware/gis_software/#survey-master), [Vespucci](https://play.google.com/store/apps/details?id=de.blau.android&hl=en_US&gl=US), [QGIS](https://qgis.org/), [QField](https://docs.qfield.org/get-started/), and any GIS software that supports NMEA over Bluetooth.

	Under the hood of the SparkPNT RTK Facet mosaic is an ESP32-WROVER-E connected to a mosaic-X5 GNSS multi-band receiver, and a variety of peripheral hardware (LiPo fuel gauge, microSD, etc). Additionally, housed under the dome of the RTK Facet mosaicis a surveyor grade L1/L2/L5 antenna. This antenna is a unique combination of elements designed to receive the GNSS signals (L1/L2/L5). The RTK Facet mosaic is programmed in Arduino and can be tailored by you to fit whatever your needs may be.

	This device can be used in five modes:

	- GNSS Positioning (~30cm accuracy) - also known as **Rover**
	- GNSS Positioning with RTK (1.4cm accuracy) - also known as **Rover with RTK Fix**
	- GNSS **Base Station**
	- GNSS **Base Station NTRIP Server**

	At *Power On* the device will enter **Rover** or **Base** mode; whichever state the device was in at the last power down. When the POWER/SETUP button is pressed momentarily, a menu is presented to change the RTK Facet mosaic from *Rover to Base mode* or vice-versa. The display will indicate the change with a small car *(Rover)* or flag *(Base)* icon.

	In **Rover mode** the RTK Facet mosaic will receive `L1`, `L2`, and `L5` GNSS signals from the four constellations (GPS, GLONASS, Galileo, and BeiDou). The device will calculate the position based on the combination of GNSS. If the device has been registered with PointPerfect or any other correction service, the receiver will quickly (within 60 seconds) obtain an RTK float, then fix. Similar to a standard grade GPS receiver, the RTK Facet mosaic will output industry standard NMEA sentences at 4Hz and broadcast them to any paired Bluetooth® device. The end user will need to parse the NMEA sentences using commonly available mobile apps, GIS products, or embedded devices (there are many open source libraries). Unlike standard grade GPS receivers that have 2500mm accuracy, the accuracy in this mode is approximately 10 to 60mm horizontal positional accuracy.

	In **Base mode** the device will enter Base Station mode. This is used when the device is mounted to a fixed position (like a tripod or roof). The RTK Facet mosaic will initiate a survey. After 60 to 120 seconds the survey will complete and the RTK Facet mosaic will begin transmitting RTCM correction data out the radio port. A base is often used in conjunction with a second RTK Facet mosaic (or RTK Torch, Facet, Surveyor, Express, Express Plus, etc) unit set to *Rover* to obtain the 10mm accuracy. Said differently, the Base sits still and sends correction data to the Rover, so that the Rover can output really accurate position data for its location.

	In addition to supplying position data, the RTK Facet mosaic is capable of logging NMEA and raw GNSS satellite data for post processing making it ideal for research and advanced positioning applications.

	The RTK Facet mosaic is an open-source hardware product meaning you can fully obtain, see, and even modify the electrical and mechanical design files. This allows for easier maintenance and repair over time.

	The SparkPNT RTK Facet mosaic kit includes everything you need: the enclosed device, thread adapter, charger, data cables, and carrying case. It does **NOT** include a [surveying pole](https://www.sparkfun.com/telescopic-surveying-pole.html) *(any additional items will need to be purchased separately)*.

	<article style="text-align: center;" markdown>
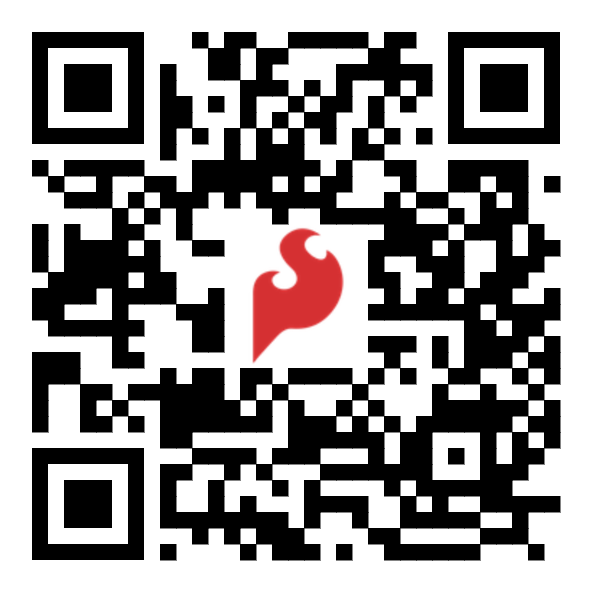
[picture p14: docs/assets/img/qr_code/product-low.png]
QR code to product page
	
	[Purchase from SparkFun :fontawesome-solid-cart-plus:{ .heart }](https://www.sparkfun.com/sparkpnt-rtk-facet-mosaic.html){ .md-button .md-button--primary }
	</article>

</div>

!!! failure "Permanent Installation"
	
	The SparkPNT RTK Facet mosaic is not designed for permanent outdoor mounting. Please use the [RTK mosaic-X5](https://www.sparkfun.com/sparkfun-rtk-mosaic-x5.html) or the [RTK Reference Station](https://www.sparkfun.com/products/22429) that is located inside or protected from the elements. Or, for a DIY solution, the [ESP32](https://www.sparkfun.com/sparkfun-thing-plus-esp32-wroom-micro-b.html) attached to our [ZED-F9P breakout](https://www.sparkfun.com/sparkfun-gps-rtk-sma-breakout-zed-f9p-qwiic.html) is a great way to go. See our [How to Build a DIY GNSS Reference Station](https://learn.sparkfun.com/tutorials/how-to-build-a-diy-gnss-reference-station) tutorial for more information.

!!! note "Completely Open-Source"
	- The [RTK Everywhere firmware](https://github.com/sparkfun/SparkFun_RTK_Everywhere_Firmware) is open-source, so users can obtain, check, and even modify the device's functionality. This allows for easier feature expansion, bug maintenance, and longer device longevity.
	- Additionally, the hardware is also open-source, so users can obtain, check, and even modify the device's design.

## :fontawesome-solid-list-check: Required Materials
To get started, users will need a few items. Some users may already have a few of these items, feel free to adjust accordingly.

<div class="annotate" markdown>

- Computer or mobile device with Bluetooth® and WiFi capabilities
- [SparkPNT RTK Facet mosaic](https://www.sparkfun.com/sparkpnt-rtk-facet-mosaic.html)
- [Telescopic Surveying Pole](https://www.sparkfun.com/telescopic-surveying-pole.html)
- [PointPerfect Registration](https://www.sparkfun.com/rtk_facet_mosaic_registration)

</div>

<div class="grid cards products" markdown>

-   <a href="https://www.sparkfun.com/sparkpnt-rtk-facet-mosaic.html">
	<figure markdown>
	Product Thumbnail
	</figure>

	---

	**SparkPNT RTK Facet mosaic**<br>
	GPS-29688</a>

-   <a href="https://www.sparkfun.com/telescopic-surveying-pole.html">
	<figure markdown>
	Product Thumbnail
	</figure>

	---

	**Telescopic Surveying Pole**<br>
	GPS-25795</a>

</div>

???+ note "Serial Transceivers, UART Adapters, and USB Cables"
	To configure the UART ports that are broken out on the board, users will need a [UART adapter](https://www.sparkfun.com/categories/349). Once configured, the UART ports can utilize one of our RF transceivers to send/receive RTCM messages.

	=== "Transceivers"

		<div class="grid cards" markdown>

		-   <a href="https://www.sparkfun.com/products/19032">
			<figure markdown>
			Product Thumbnail
			</figure>

			---

			**SiK Telemetry Radio V3 - 915MHz, 100mW**<br>
			WRL-19032</a>

		-   <a href="https://www.sparkfun.com/products/20029">
			<figure markdown>
			Product Thumbnail
			</figure>

			---

			**SparkFun LoRaSerial Kit - 915MHz (Enclosed)**<br>
			WRL-20029</a>

		-   <a href="https://www.sparkfun.com/products/17854">
			<figure markdown>
			Product Thumbnail
			</figure>

			---

			**GHR-04V-S to GHR-06V-S Cable - 100mm**<br>
			CAB-17854</a>

		</div>

	=== "USB Cables"

		<div class="grid cards" markdown>

		-   <a href="https://www.sparkfun.com/products/14743">
			<figure markdown>
			Product Thumbnail
			</figure>

			---

			**USB 3.1 Cable A to C - 3 Foot**<br>
			CAB-14743</a>

		-   <a href="https://www.sparkfun.com/products/21271">
			<figure markdown>
			Product Thumbnail
			</figure>

			---

			**SparkFun 4-in-1 Multi-USB Cable - USB-C Host**<br>
			CAB-21271</a>

		-   <a href="https://www.sparkfun.com/products/21272">
			<figure markdown>
			Product Thumbnail
			</figure>

			---

			**SparkFun 4-in-1 Multi-USB Cable - USB-A Host**<br>
			CAB-21272</a>

		</div>

??? note "Jumper Modification"
	To modify the [jumpers](./hardware_overview.md/#jumpers), users will need [soldering equipment](https://www.sparkfun.com/categories/49) and/or a [hobby knife](https://www.sparkfun.com/categories/379).

	!!! tip "New to jumper pads?"
		Check out our [Jumper Pads and PCB Traces Tutorial](https://learn.sparkfun.com/tutorials/664) for a quick introduction!

		<div class="grid cards" markdown align="center">

		-   <a href="https://learn.sparkfun.com/tutorials/664">
			<figure markdown>
			Tutorial thumbnail
			</figure>

			---

			**How to Work with Jumper Pads and PCB Traces**</a>

		</div>

	<div class="grid cards" markdown>

	-   <a href="https://www.sparkfun.com/products/24063">
		<figure markdown>
		Product Thumbnail
		</figure>

		---

		**PINECIL Soldering Iron Kit**<br>
		KIT-24063</a>

	-   <a href="https://www.sparkfun.com/products/9200">
		<figure markdown>
		Product Thumbnail
		</figure>

		---

		**Hobby Knife**<br>
		TOL-09200</a>

	-   <a href="https://www.sparkfun.com/products/14579">
		<figure markdown>
		Product Thumbnail
		</figure>

		---

		**Chip Quik No-Clean Flux Pen - 10mL**<br>
		TOL-14579</a>

	-   <a href="https://www.sparkfun.com/products/9327">
		<figure markdown>
		Product Thumbnail
		</figure>

		---

		**Solder Wick #2 5ft. - Generic**<br>
		TOL-09327</a>

	</div>

## :material-bookshelf: Suggested Reading

As a more sophisticated product, we will skip over the more fundamental tutorials (i.e. [**Ohm's Law**](https://learn.sparkfun.com/tutorials/voltage-current-resistance-and-ohms-law) and [**What is Electricity?**](https://learn.sparkfun.com/tutorials/what-is-electricity)). However, below are a few tutorials that may help users familiarize themselves with various aspects of the board.

!!! tip
	Check out the [www.gps.gov](https://www.gps.gov/) website to learn more about the U.S.-owned [Global Positioning System (GPS)](https://www.gps.gov/systems/gps/) and the [Global Navigation Satellite Systems (GNSS) of other countries](https://www.gps.gov/systems/gnss/).

<div class="grid cards" markdown align="center">

-   <a href="https://learn.sparkfun.com/tutorials/9">
	<figure markdown>
	Tutorial Thumbnail
	</figure>

	---

	**GPS Basics**</a>

-   <a href="https://learn.sparkfun.com/tutorials/813">
	<figure markdown>
	Tutorial Thumbnail
	</figure>

	---

	**What is GPS RTK?**</a>

-   <a href="https://docs.sparkfun.com/SparkFun_RTK_Everywhere_Firmware">
	<figure markdown>
	Tutorial Thumbnail
	</figure>

	---

	**SparkFun RTK Everywhere Product Manual**</a>

-   <a href="https://learn.sparkfun.com/tutorials/1362">
	<figure markdown>
	Tutorial Thumbnail
	</figure>

	---

	**Setting up a Rover Base RTK System**</a>

-   <a href="https://learn.sparkfun.com/tutorials/1363">
	<figure markdown>
	Tutorial Thumbnail
	</figure>

	---

	**How to Build a DIY GNSS Reference Station**</a>

-   <a href="https://learn.sparkfun.com/tutorials/2583">
	<figure markdown>
	Tutorial Thumbnail
	</figure>

	---

	**SparkFun RTK Facet L-Band Hookup Guide**</a>

-   <a href="https://learn.sparkfun.com/tutorials/8">
	<figure markdown>
	Tutorial Thumbnail
	</figure>

	---

	**Serial Communication**</a>

-   <a href="https://learn.sparkfun.com/tutorials/112">
	<figure markdown>
	Tutorial Thumbnail
	</figure>

	---

	**Serial Terminal Basics**</a>

-   <a href="https://learn.sparkfun.com/tutorials/82">
	<figure markdown>
	Tutorial Thumbnail
	</figure>

	---

	**I2C**</a>

</div>

??? info "Related Blog Posts"
	Additionally, users may be interested in these blog post articles on GNSS technologies:

	<div class="grid cards" markdown align="center">

	-   <a href="https://www.sparkfun.com/news/4276">
		<figure markdown>
		Tutorial Thumbnail
		</figure>

		---

		**GPS vs GNSS**</a>

	-   <a href="https://www.sparkfun.com/news/7138">
		<figure markdown>
		Tutorial Thumbnail
		</figure>

		---

		**What is Correction Data?**</a>

	-   <a href="https://www.sparkfun.com/news/7533">
		<figure markdown>
		Tutorial Thumbnail
		</figure>

		---

		**Real-Time Kinematics Explained**</a>

	-   <a href="https://www.sparkfun.com/news/7401">
		<figure markdown>
		Tutorial Thumbnail
		</figure>

		---

		**New Video: Unlocking High-Precision RTK Positioning**</a>

	-   <a href="https://www.sparkfun.com/news/9514">
		<figure markdown>
		Tutorial Thumbnail
		</figure>

		---

		**DIY RTK Surveying**</a>

	</div>

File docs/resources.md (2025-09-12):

---
icon: material/book-open-page-variant
---

## Product Resources

- :sfe: [Product Page](https://www.sparkfun.com/sparkpnt-rtk-facet-mosaic-l-band.html)
- :material-folder-cog: Design Files:
	<!-- - :fontawesome-solid-file-pdf: [Board Dimensions](./assets/board_files/dimensions.pdf) -->

	<div class="grid cards" style="grid-template-columns: repeat(auto-fit,minmax(8rem,1fr));" markdown>

	- All Files

		---

		- :material-folder-zip: [Schematics](./assets/board_files/schematics.zip)
		- :material-folder-zip: [KiCad Files](./assets/board_files/kicad_files.zip)
		- :material-folder-zip: [STEP Files](./assets/3d_model/step_files.zip)

	- Connector Board

		---

		- :fontawesome-solid-file-pdf: [Schematic](./assets/board_files/schematic-connector_board.pdf)
		- :material-folder-zip: [KiCad Files](./assets/board_files/kicad_files-connector_board.zip)
		- :material-cube-outline: [STEP File](./assets/3d_model/connector_board.step)

	- Display Board

		---

		- :fontawesome-solid-file-pdf: [Schematic](./assets/board_files/schematic-display_board.pdf)
		- :material-folder-zip: [KiCad Files](./assets/board_files/kicad_files-display_board.zip)
		- :material-cube-outline: [STEP File](./assets/3d_model/display_board.step)

	- Main Board

		---

		- :fontawesome-solid-file-pdf: [Schematic](./assets/board_files/schematic-main_board.pdf)
		- :material-folder-zip: [KiCad Files](./assets/board_files/kicad_files-main_board.zip)
		- :material-cube-outline: [STEP File](./assets/3d_model/main_board.step)

	</div>

- Component Documentation

	<div class="grid cards" style="grid-template-columns: repeat(auto-fit,minmax(8rem,1fr));" markdown>

	- :septentrio: mosaic-X5

		---

		- :fontawesome-solid-file-pdf: [Hardware Manual](./assets/component_documentation/mosaic_hardware_manual_v1.11.0.pdf)
		- :fontawesome-solid-file-pdf: [Firmware Reference Guide](./assets/component_documentation/mosaic-X5_Firmware_v4.15.0_Reference_Guide.pdf)
		- :fontawesome-solid-file-pdf: [Brochure](./assets/component_documentation/Septentrio_mosaic-X5_LR.pdf)

	- :espressif: ESP32-WROVER-E

		---

		- :fontawesome-solid-file-pdf: [Module Datasheet](./assets/component_documentation/esp32-wrover-e_datasheet_en.pdf)
		- :fontawesome-solid-file-pdf: [SoC Datasheet](./assets/component_documentation/esp32_datasheet_en.pdf)
		- :fontawesome-solid-file-pdf: [SoC Technical Reference Manual](./assets/component_documentation/esp32_technical_reference_manual_en.pdf)

	- Miscellaneous

		---

		- :fontawesome-solid-file-pdf: [74HC4052 Datasheet](./assets/component_documentation/74HC4052.pdf)
		- :fontawesome-solid-file-pdf: [AP2112 Datasheet](./assets/component_documentation/AP2112.pdf)
		- :fontawesome-solid-file-pdf: [AP7361C Datasheet](./assets/component_documentation/AP7361C.pdf)
		- :fontawesome-solid-file-pdf: [CH340 Datasheet](./assets/component_documentation/CH340DS1.PDF)
		- :fontawesome-solid-file-pdf: [MAX17048 Datasheet](./assets/component_documentation/MAX17048.pdf)
		- :fontawesome-solid-file-pdf: [MCP73833 Datasheet](./assets/component_documentation/MCP73833.pdf)
		- :fontawesome-solid-file-pdf: [SN74LVC1G175 Datasheet](./assets/component_documentation/SN74LVC1G175.pdf)
		- :fontawesome-solid-file-pdf: [STLQ015 Datasheet](./assets/component_documentation/STLQ015.pdf)
		- :fontawesome-solid-file-pdf: [USB251xB Datasheet](./assets/component_documentation/USB251xB.pdf)

	</div>

- :material-github: [Hardware Repository](https://github.com/sparkfun/SparkFun_RTK_Facet_mosaic)
- :material-github: [Firmware Repository](https://github.com/sparkfun/SparkFun_RTK_Everywhere_Firmware)
	- [User Manual](http://docs.sparkfun.com/SparkFun_RTK_Everywhere_Firmware)
	- [Pre-Compiled Biniaries](https://github.com/sparkfun/SparkFun_RTK_Everywhere_Firmware_Binaries)
	- [SparkFun RTK Firmware Uploader Tool](https://github.com/sparkfun/SparkFun_RTK_Firmware_Uploader)
- :material-youtube: [SFE Product Showcase](https://www.youtube.com/watch?v=e3OKRtJDPgw)

### :sfe: Additional Resources

- [Qwiic Information Page](https://www.sparkfun.com/qwiic)
- :material-account-supervisor: [SparkFun Technical Assistance](https://www.sparkfun.com/technical_assistance)

### 🏭 Manufacturer's Resources

<div class="grid cards" markdown>

-   :septentrio-primary:{ .enlarge-logo }

	---

	Septentrio also provides great resources for the mosaic-X5:

	<article class="annotate" markdown>

	- [mosaic-X5 Product Page](https://www.septentrio.com/en/products/gps/gnss-receiver-modules/mosaic-x5)
		- :material-file-document-multiple: [Resources: Datasheet, firmware, manual, software tools, USB driver, etc.](https://www.septentrio.com/en/products/gps/gnss-receiver-modules/mosaic-x5#resources)
	- :material-help-box: [Support Portal](https://customersupport.septentrio.com/s/):
		- :material-file-document-multiple: [Septentrio Knowledge Base](https://customersupport.septentrio.com/s/topiccatalog) (1)
		- [Learn More](https://www.septentrio.com/en/learn-more)
			- [Webinars](https://www.septentrio.com/en/learn-more/webinars)
			- [Technical Papers](https://www.septentrio.com/en/learn-more/technical-papers)
			- [Insights](https://www.septentrio.com/en/learn-more/insights) *(Case Studies and Technical Articles)*
			- [Community](https://www.septentrio.com/en/learn-more/community)
			- [Agnostic Corrections Program](https://www.septentrio.com/en/products/correction-services/precise-point-positioning-services-land/agnostic-corrections-program-gnss-correction-services)
	- :material-github: [GitHub](https://github.com/septentrio-gnss):
		- [Set Up Guide to use Third Party OSR and SSR correction services](https://github.com/septentrio-gnss/Septentrio_AgnosticCorrectionsProgram)
			- [Using Septentrio's Receiver and uBlox's Pointperfect correction services for precise positioning](https://github.com/septentrio-gnss/uBloxCorrectionsWithSeptentrio)
			- [Using Septentrio's Receiver and Swift Navigation's Skylark correction services for precise positioning](https://github.com/septentrio-gnss/SwiftCorrectionsWithSeptentrio)
	- :material-youtube: [YouTube Channel](https://www.youtube.com/@SeptentrioGNSS) (2)
	- [JammerTest 2023 - Anti-Jamming and Anti-Spoofing Performance](https://www.septentrio.com/en/learn-more/insights/most-resilient-gnss-receiver-results-jammertest-norway)

	</article>

	1. !!! info "Recommended Articles"

			**General Knowledge**

			:material-file-document:[mosaic - Getting started](https://customersupport.septentrio.com/s/article/mosaic-Getting-started)<br>
			:material-file-document:[Resetting a receiver](https://customersupport.septentrio.com/s/article/Resetting-a-receiver)<br>
			:material-file-document:[Resetting and clearing the non-volatile memory](https://customersupport.septentrio.com/s/article/Resetting-receiver)<br>
			:material-file-document:[Generating a diagnostic report of a Septentrio receiver](https://customersupport.septentrio.com/s/article/Generating-saving-a-diagnostic-report-of-a-Septentrio-receiver)<br>
			:material-file-document:[RTCMv3 messages supported by the Septentrio receivers](https://customersupport.septentrio.com/s/article/RTCMv3-messages)<br>
			:material-file-document:[Interference Detection, Mitigation, and Flagging](https://customersupport.septentrio.com/s/article/Spoofing-and-Interference-Flagging)

			**Providing Corrections**

			:material-file-document:[How to set up a base station](https://customersupport.septentrio.com/s/article/How-to-set-up-a-base-station-Chapter-1-Introduction-and-terminology)<br>
			:material-file-document:[RTK positioning with a moving baseline](https://customersupport.septentrio.com/s/article/How-to-get-RTK-positioning-with-a-moving-baseline)<br>
			:material-file-document:[Set up an (internal) NTRIP caster on a Septentrio receiver](https://customersupport.septentrio.com/s/article/How-to-set-up-an-internal-NTRIP-caster-on-a-Septentrio-receiver)

			**Applying Corrections**

			:material-file-document:[Receive corrections over IP](https://customersupport.septentrio.com/s/article/How-to-receive-corrections-over-IP)<br>
				:material-file-document:[Receive corrections via NTRIP](https://customersupport.septentrio.com/s/article/How-to-receive-corrections-via-NTRIP)<br>
			:material-file-document:[Using uBlox's correction services for precise positioning](https://customersupport.septentrio.com/s/article/Using-Septentrio-s-Receiver-and-uBlox-s-correction-services-for-precise-positioning)

			**Antenna Corrections**

			:material-file-document:[Antenna calibration](https://customersupport.septentrio.com/s/article/Antenna-calibration)<br>
			:material-file-document:[Applying ARP/APC offsets](https://customersupport.septentrio.com/s/article/ARP-APC-offsets)

	2. 	!!! info "Recommended Videos"

			:material-youtube: [Getting started with the mosaic receiver module](https://youtu.be/hrL5J6Q5gX8)<br>
			:material-youtube: [Output NMEA data on the mosaic receiver module](https://youtu.be/ArtePkC58-o)<br>
			:material-youtube: [Receiving NTRIP corrections on the mosaic module](https://youtu.be/aAPoRpSR0tY)<br>
			:material-youtube: [Logging data to the Septentrio mosaic receiver module](https://youtu.be/Y9tvOebnoxk)<br>
			:material-youtube: [Receiving corrections over an IP connection](https://youtu.be/UVUVXpA8rB4)<br>
			:material-youtube: [Share the USB internet connection on your receiver](https://youtu.be/bUt8cL9Ue1Y)<br>
			:material-youtube: [Septentrio's Agnostic GNSS Corrections program](https://youtu.be/UxNtmEwABL4)<br>
			:material-youtube: [Test-run for Septentrio's anti-jamming feature](https://youtu.be/SzI0skGHKEw)<br>
			:material-youtube: [mosaic - GNSS module receiver range from Septentrio](https://youtu.be/Co8hrVeklAA)

-   :espressif-primary:{ .enlarge-logo }

	---

	Espressif also provides great resources for their ESP32 module:

	- [ESP32 Product Resource Page](http://espressif.com/en/products/hardware/esp32/resources)
	- [Espressif's Forum for the ESP32](http://esp32.com/)
	- [Espressif GitHub Repositories](https://github.com/espressif)
		- [ESP32 Arduino Core](https://github.com/espressif/arduino-esp32)
			 - `.json` file needed for Epressif's ESP32 Arduino Core:<br>
			[`https://raw.githubusercontent.com/espressif/arduino-esp32/gh-pages/package_esp32_index.json`](https://raw.githubusercontent.com/espressif/arduino-esp32/gh-pages/package_esp32_index.json)
		- [ESP-IDF -- IoT Development Framework](https://github.com/espressif/esp-idf)
			- [Programming Guide](http://esp-idf.readthedocs.io/en/latest/)

</div>

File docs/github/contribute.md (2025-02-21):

# Contribute: Make an Augmentation!
Spot an improvement opportunity? Feel free to contribute to our open-source design and documentation. 

## :material-file-document-multiple: Improve our Documentation
All of this documentation can be modified by you! Please help us make it better.

- These pages are contained in the [`docs` folder](https://github.com/sparkfun/SparkFun_RTK_Facet_mosaic/tree/main/docs) of the [SparkFun RTK Facet mosaic L-Band repository](https://github.com/sparkfun/SparkFun_RTK_Facet_mosaic).

<!-- ### :material-source-pull: Submit a Correction -->
### Submit a Correction

1. With a GitHub account, [fork this repository](https://github.com/sparkfun/SparkFun_RTK_Facet_mosaic/fork).
2. Add your corrections or improvements to the markdown file.
3. File a pull request with your changes, and enjoy making the ~~words~~ ~~worlds~~ world a better place.
	- Once received, the documentation specialist will automatically be notified.
	- We will review your suggested improvements to make sure they are correct and fit within our documentation standards.

## :material-cog: Improve our Hardware Design
All of our designs are open-source! Please help us make it better.

- Our board design files are contained in the [`Hardware` folder](https://github.com/sparkfun/SparkFun_RTK_Facet_mosaic/tree/main/Hardware) of the [SparkFun RTK Facet mosaic L-Band repository](https://github.com/sparkfun/SparkFun_RTK_Facet_mosaic).

<!-- ### :material-source-pull: Submit a Design Enhancement -->
### Submit a Design Enhancement

1. With a GitHub account, [fork this repository](https://github.com/sparkfun/SparkFun_RTK_Facet_mosaic/fork).
2. Add your design augmentation(s)
3. File a pull request with your changes, and enjoy making the ~~words~~ ~~worlds~~ world a better place.
	1. Once received, the engineer in charge of the original design will automatically be notified.
	2. We will review your suggested improvement(s) to verify that they are within our board design standards and meet our product design requirements.
	3. If approved, we will flag these changes for our next board revision. Congrats! 🍻

		!!! info
			Even if your suggestion is accepted, these changes may not be immediately available for purchase. We may have to cycle through our current product inventory first.

## Contributors :clap:
Let's provide some recognition to the contributors for this project!

GitHub Contributors Image
<br>


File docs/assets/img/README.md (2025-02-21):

img directory
====================
This folder should contain the images for the product documentation

## General Images
- `sfe-logo.png` - SparkFun flame logo (favicon)

## Directory
- `graphical_datasheet` - Files for graphical datasheet
- `hookup_guide` - Images for the hookup guide pages
- `qr_code` - QR code images
- `qwiic` - Images for Qwiic Banner

## QR Codes
- [QR code generator](https://qrgenerator.org/)
	- Flame Color: #E0311D
	- Frame Color: #3C464D
- [Remove meta data from svg](https://jakearchibald.github.io/svgomg/)

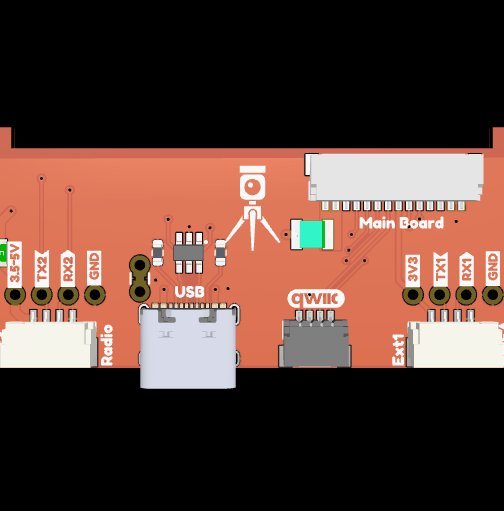
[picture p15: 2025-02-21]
docs/assets/3d_model/poster-connector_board.jpeg

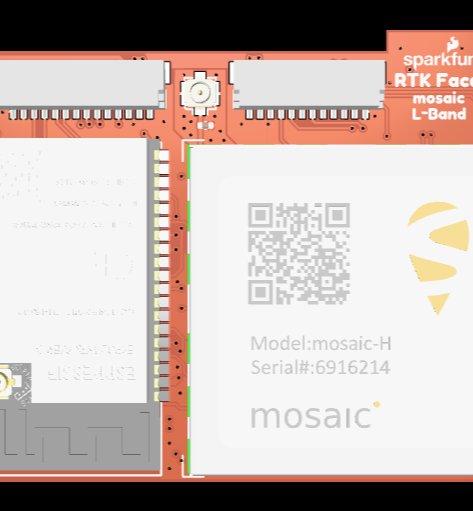
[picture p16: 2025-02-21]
docs/assets/3d_model/poster-main_board.jpeg

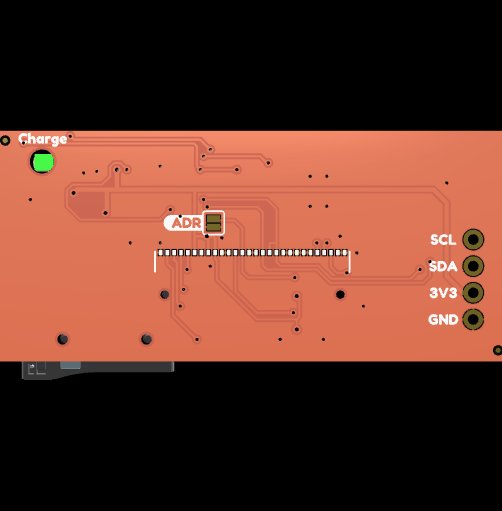
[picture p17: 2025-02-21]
docs/assets/3d_model/poster-display_board.jpeg

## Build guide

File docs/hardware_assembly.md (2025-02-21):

---
icon: material/tools
---

The RTK Facet mosaic was designed to work with low-cost, off the shelf equipment. The RTK Facet mosaic is designed to use corrections provided via u-blox's PointPerfect system, therefore, a Base/Rover setup is not needed. However, if the service is not available the RTK Facet mosaic can still be used in a traditional Base/Rover setup. Here we'll describe how to assemble a Rover and Base.

## Surveying (Rover Mode)

<figure markdown>
Basic RTK Facet mosaic setup (https://cdn.sparkfun.com/assets/learn_tutorials/2/1/8/8/SparkFun_RTK_Facet_-_On_Monopod.jpg)
<figcaption markdown>
Basic RTK Facet mosaic Rover setup with RTCM over Bluetooth
</figcaption>
</figure>

Shown above is the most common RTK Rover setup. A monopole designed for cameras is used. The ¼” camera thread of the monopole is [adapted to ⅝” 11-TPI](https://www.sparkfun.com/products/17546) and the RTK Facet mosaic is mounted on top. No radio is needed because RTCM correction data is provided by a phone over Bluetooth.

!!! tip
	If you're shopping for a monopole (aka monopod), get one that is 65” in length or greater to ensure that the antenna will be above your head. We've had good luck with the [Amazon Basics](https://www.amazon.com/AmazonBasics-WT1003-67-Inch-Monopod/dp/B00FAYL1YU) brand.

	If you prefer to mount your tablet or cell phone to the monopole be sure to get a clamp that is compatible with the diameter of your monopole and has a knob to increase clamp pressure. Our monopole is 27mm in diameter so a device clamp would need to be able to handle that diameter.

## Radio Link

<figure markdown>
RTK Facet mosaic setup with radio (https://cdn.sparkfun.com/assets/learn_tutorials/2/1/8/8/SparkFun_RTK_Facet_-_External_Radio.jpg)
<figcaption markdown>
2nd most common setup with a 915MHz Radio providing RTCM
</figcaption>
</figure>

If you are receiving RTCM correction data over a radio link it's recommended that you attach a radio to the bottom of the RTK Facet mosaic.

<figure markdown>
Serial Telemetry Radio mounted to the back of RTK Facet mosaic (https://cdn.sparkfun.com/assets/learn_tutorials/2/1/8/8/SparkFun_RTK_Facet_-_External_Radio_Positioning.jpg)
<figcaption markdown>
</figcaption>
</figure>

[Picture hanging strips](https://www.amazon.com/gp/product/B073XS3CHW) from 3M make a nice semi-permanent mount. Plug the 4-pin to 6-pin JST cable included with the RTK Facet mosaic from the **Radio** port to either of the [Serial Telemetry Radios](https://www.sparkfun.com/products/19032) (shipped in pairs). We really love these radios because they are paired out of the box, either can send or receive (so it doesn't matter which radio is attached to base or rover) and they have remarkable range. We achieved over a mile range (nearly 1.5 miles or 2.4km) with the 100mW radios and a [big 915MHz antenna](https://www.sparkfun.com/products/retired/14868) on the base (see [this tutorial](https://learn.sparkfun.com/tutorials/how-to-build-a-diy-gnss-reference-station#mini-computer-setup) for more info).

## Temporary Base

A temporary or mobile base setup is needed when you are in the field too far away from a correction source and/or cellular reception. A 2nd RTK Facet mosaic is mounted to a tripod and it is configured to complete a survey-in (aka, locate itself), then begin broadcasting RTCM correction data. This data (~1000 bytes a second) is sent to the user's connected radio of choice. For our purposes, the 915MHz 100mW telemetry radios are used because they provide what is basically a serial cable between our base and rover.

<figure markdown>
Temporary RTK Facet mosaic Base setup (https://cdn.sparkfun.com/assets/learn_tutorials/2/1/8/8/SparkFun_RTK_Facet_-_Base_Tripod.jpg)
<figcaption markdown>
Temporary RTK Facet mosaic Base setup
</figcaption>
</figure>

Any tripod with a ¼” camera thread will work. The [Amazon Basics tripod](https://www.amazon.com/AmazonBasics-Lightweight-Camera-Mount-Tripod/dp/B00XI87KV8) works well enough but is a bit light weight and rickety. The ¼” camera thread is [adapted to ⅝” 11-TPI](https://www.sparkfun.com/products/17546) and the RTK Facet mosaic is attached on top.

Once the base has been setup with a clear view of the sky, turn on the RTK Facet mosaic. Once on, press the *Setup* button to put the device in Base mode. The display will show the Survey-In screen for 60-120 seconds. Once the survey is complete the display will show the 'Xmitting' display and begin producing RTCM correction data. You can verify this by viewing the LEDs on the telemetry radio (a small red LED will blink when serial data is received from the RTK Facet mosaic). The RTK Facet mosaic is designed to follow the u-blox recommended survey-in of 60s and a mean 3D standard deviation of 5m of all fixes. If a survey fails to achieve these requirements it will auto-restart after 10 minutes.

!!! tip
	A mobile base station works well for quick trips to the field. However, the survey-in method is not recommended for the highest accuracy measurements because the positional accuracy of the base will directly translate to the accuracy of the rover. Said differently, if your base's calculated position is off by 100cm, so will every reading your rover makes. If you're looking for maximum accuracy consider installing a [static base with fixed antenna](https://learn.sparkfun.com/tutorials/how-to-build-a-diy-gnss-reference-station#static-base-setup--lasers). We were able to pinpoint the antenna on the top of SparkFun with an incredible accuracy [+/-2mm of accuracy](https://cdn.sparkfun.com/assets/learn_tutorials/1/4/6/3/SparkFun_PPP_Results.png) using PPP!

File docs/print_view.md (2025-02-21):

---
hide:
  - navigation
  - toc
icon: material/printer
---

--8<-- "./introduction.md:5"

# Hardware Overview
--8<-- "./hardware_overview.md:5"

# Hardware Assembly
--8<-- "./hardware_assembly.md:5"

# Software Overview
--8<-- "./software_overview.md:5"

# Resources
--8<-- "./resources.md:5"

# Troubleshooting Tips
--8<-- "./troubleshooting_tips.md:5"

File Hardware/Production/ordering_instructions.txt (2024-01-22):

Ordering Instructions:
Panel dimensions: 133.20 x 187.20 mm.
Controlled Impedance: JLC7628
Material: TG155
Solder Mask: Red
Silkscreen: White
Layers: 4
Finish: ENIG
Thickness: 1.6mm
Copper Weight: 1oz
Minimum track width: 0.18mm (7.00mil)
Minimum via drill: 0.30mm (11.81mil)
No Clean Process

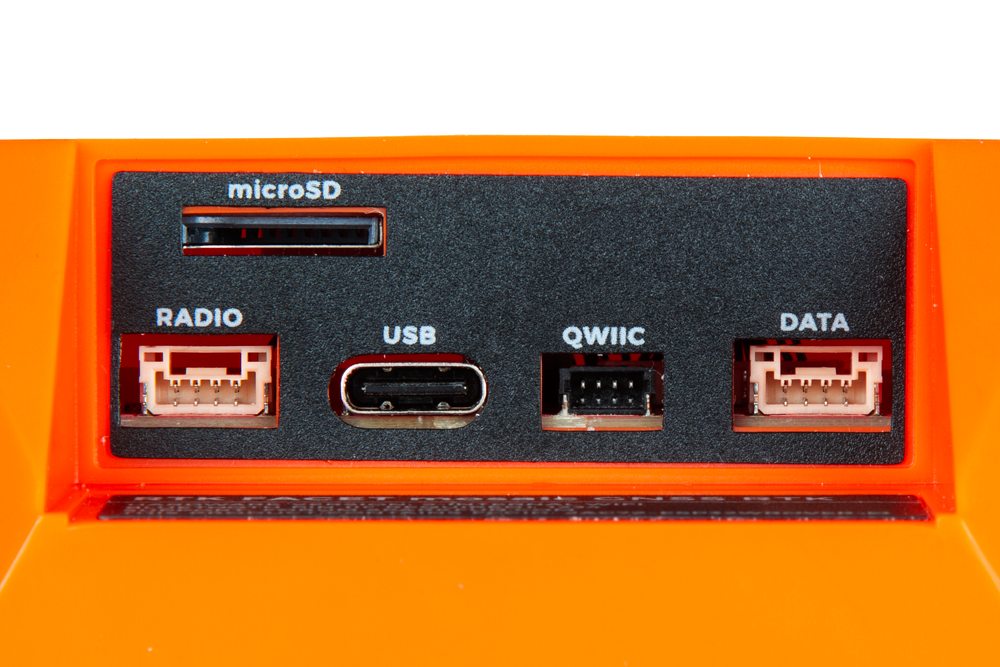
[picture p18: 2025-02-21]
docs/assets/img/hookup_guide/connections2.png

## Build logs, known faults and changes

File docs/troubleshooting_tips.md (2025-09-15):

---
icon: sfe
---

!!! warning "Need Help?"
	If you need technical assistance or more information on a product that is not working as you expected, we recommend heading over to the [SparkFun Technical Assistance](https://www.sparkfun.com/technical_assistance) page for some initial troubleshooting.

	<article style="text-align: center;" markdown>
	[SparkFun Technical Assistance Page](https://www.sparkfun.com/technical_assistance){ .md-button .md-button--primary }
	</article>

	If you can't find what you need there, the [SparkFun GNSS Forum](https://forum.sparkfun.com/viewforum.php?f=116) is a great place to ask questions.

	!!! info "Account Registration Required"
		If this is your first visit to our forum, you'll need to create a [Forum Account](https://forum.sparkfun.com/ucp.php?mode=register) to post questions.

## Replacement Parts
If you loose and/or damage any part of the RTK Facet mosaic kit, all of our available replacement parts for the kit and hardware component can be found here:

??? abstract "Kit Parts"
	<div class="grid cards" markdown>

	-   <a href="https://www.sparkfun.com/sparkpnt-rtk-facet-ruggedized-hardcase.html">
		<figure markdown>
		Product Thumbnail
		</figure>

		---

		**SparkPNT RTK Facet Ruggedized Hardcase**<br>
		PRT-27115</a>

	-   <a href="https://www.sparkfun.com/antenna-thread-adapter-1-4in-to-5-8in.html">
		<figure markdown>
		Product Thumbnail
		</figure>

		---

		**Antenna Thread Adapter - 1/4in. to 5/8in.**<br>
		PRT-17546</a>

	-   <a href="https://www.sparkfun.com/jst-ghr-04v-to-jst-ghr-06v-cable-1-25mm-pitch.html">
		<figure markdown>
		Product Thumbnail
		</figure>

		---

		**JST-GHR-04V to JST-GHR-06V Cable - 1.25mm pitch**<br>
		CAB-17239</a>

	-   <a href="https://www.sparkfun.com/breadboard-to-jst-ghr-04v-cable-4-pin-x-1-25mm-pitch.html">
		<figure markdown>
		Product Thumbnail
		</figure>

		---

		**Breadboard to JST-GHR-04V Cable - 4-Pin x 1.25mm Pitch**<br>
		CAB-17240</a>

	-   <a href="https://www.sparkfun.com/usb-c-to-usb-c-silicone-power-charging-cable-3m.html">
		<figure markdown>
		Product Thumbnail
		</figure>

		---

		**USB-A to USB-C Cable - 3m (Flexible Silicone)**<br>
		CAB-24060</a>

	-   <a href="https://www.sparkfun.com/usb-a-and-c-power-delivery-pd-wall-adapter-65w.html">
		<figure markdown>
		Product Thumbnail
		</figure>

		---

		**USB A and C Power Delivery (PD) Wall Adapter - 65W**<br>
		TOL-24059</a>

	</div>

??? abstract "Components - RTK Facte mosaic"
	- M2.2-0.98 x 10mm Thread Forming Screws - Phillips Head
	- M3-1.34 x 10mm Thread Forming Screws - Phillips Head

<!-- QR Code for Hookup Guide (Displayed when printed) -->
<article style="text-align: center;" markdown>
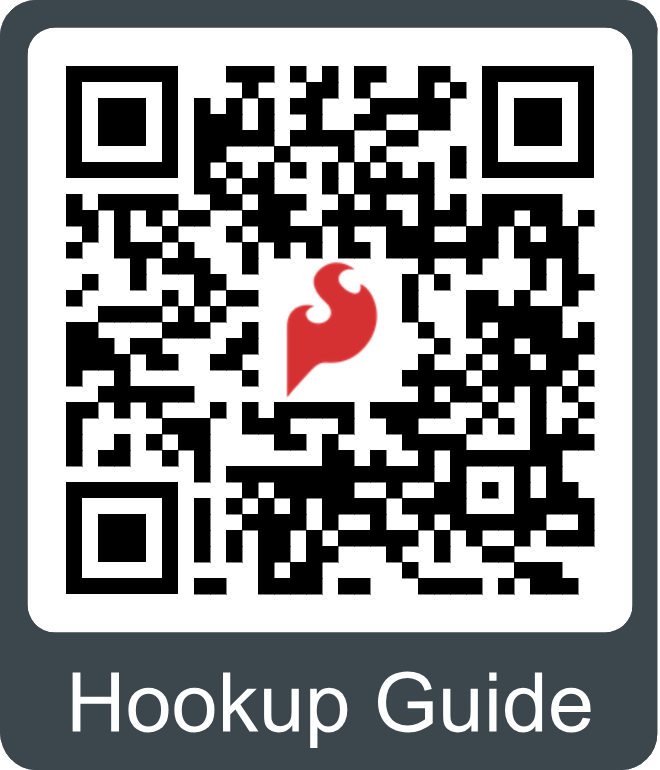
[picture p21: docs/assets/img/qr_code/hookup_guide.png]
QR code to the hookup guide

</article>

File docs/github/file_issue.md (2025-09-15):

# Did we make a mistake?

Spot something wrong? Please let us know. 

<!-- Technical Assistance Box -->
!!! warning "Need Help?"
	If you need technical assistance or more information on a product that is not working as you expected, we recommend heading on over to the [SparkFun Technical Assistance](https://www.sparkfun.com/technical_assistance) page for some initial troubleshooting. This **Submit Issues** page is not where users should seek assistance.

	<article style="text-align: center;" markdown>
	[SparkFun Technical Assistance Page](https://www.sparkfun.com/technical_assistance){ .md-button .md-button--primary }
	</article>

	If you can't find what you need there, the [SparkFun Forums](https://forum.sparkfun.com) is a great place to search the product forums and ask questions.

	!!! info "Account Registration Required"
		For your first visit to our forum, you'll need to create a [Forum Account](https://forum.sparkfun.com/ucp.php?mode=register) to post questions.

## Discrepancies in the Documentation

All of our documentation can be modified by you! Please help us make it better.

- The documentation files for these pages are contained in the [`docs` folder](https://github.com/sparkfun/SparkFun_RTK_Facet_mosaic/tree/main/docs) of the [SparkFun RTK Facet mosaic L-Band repository](https://github.com/sparkfun/SparkFun_RTK_Facet_mosaic).

### 🔍 Spot something wrong?

If a section of the documentation is incorrect, please [open an issue](https://github.com/sparkfun/SparkFun_RTK_Facet_mosaic/issues) and let us know.

### Do you have a suggested correction?

1. With a GitHub account, [fork this repository](https://github.com/sparkfun/SparkFun_RTK_Facet_mosaic/fork).
2. Add your correction(s) or improvement(s) to the markdown file(s)
3. File a pull request with your changes, and enjoy making the ~~words~~ ~~worlds~~ world a better place.
	- Once received, the documentation specialist will automatically be notified.
	- We will review your suggested improvement(s) to make sure they are correct and fit within our documentation standards.

## Problems in the Hardware Design

All of our designs are open-source! Please help us make it better.

- Our board design files are contained in the [`Hardware` folder](https://github.com/sparkfun/SparkFun_RTK_Facet_mosaic/tree/main/Hardware) of the [SparkFun RTK Facet mosaic L-Band repository](https://github.com/sparkfun/SparkFun_RTK_Facet_mosaic).

### Does something not make sense? 🤔

If part of the design is confusing, please [open an issue](https://github.com/sparkfun/SparkFun_RTK_Facet_mosaic/issues) and let us know.

### Did we forget to include an important function of the board? 🤦

If part of the board's functionality is missing, please [open an issue](https://github.com/sparkfun/SparkFun_RTK_Facet_mosaic/issues) and file a feature request.

!!! tip "Design Considerations"
	Please keep in mind that we may intentionally exclude certain functions of the board to meet our product design requirements.

	- *For example, our Qwiic Micro boards are intended to fit on a small board layout and only use I^2^C communication; therefore, we may not have the SPI and interrupt pins available for users.*

### Do you wish to contribute directly to improving the board design?

1. With a GitHub account, [fork this repository](https://github.com/sparkfun/SparkFun_RTK_Facet_mosaic/fork).
2. Add your design augmentation(s)
3. File a pull request with your changes, and enjoy making the ~~words~~ ~~worlds~~ world a better place.
	1. Once received, the engineer in charge of the original design will automatically be notified.
	2. We will review your suggested improvement(s) to verify that they are within our board design standards and meet our product design requirements.
	3. If approved, we will flag these changes for our next board revision. Congrats! 🍻

		!!! info
			Even if your suggestion is accepted, these changes may not be immediately available for purchase. We may have to cycle through our current product inventory first.

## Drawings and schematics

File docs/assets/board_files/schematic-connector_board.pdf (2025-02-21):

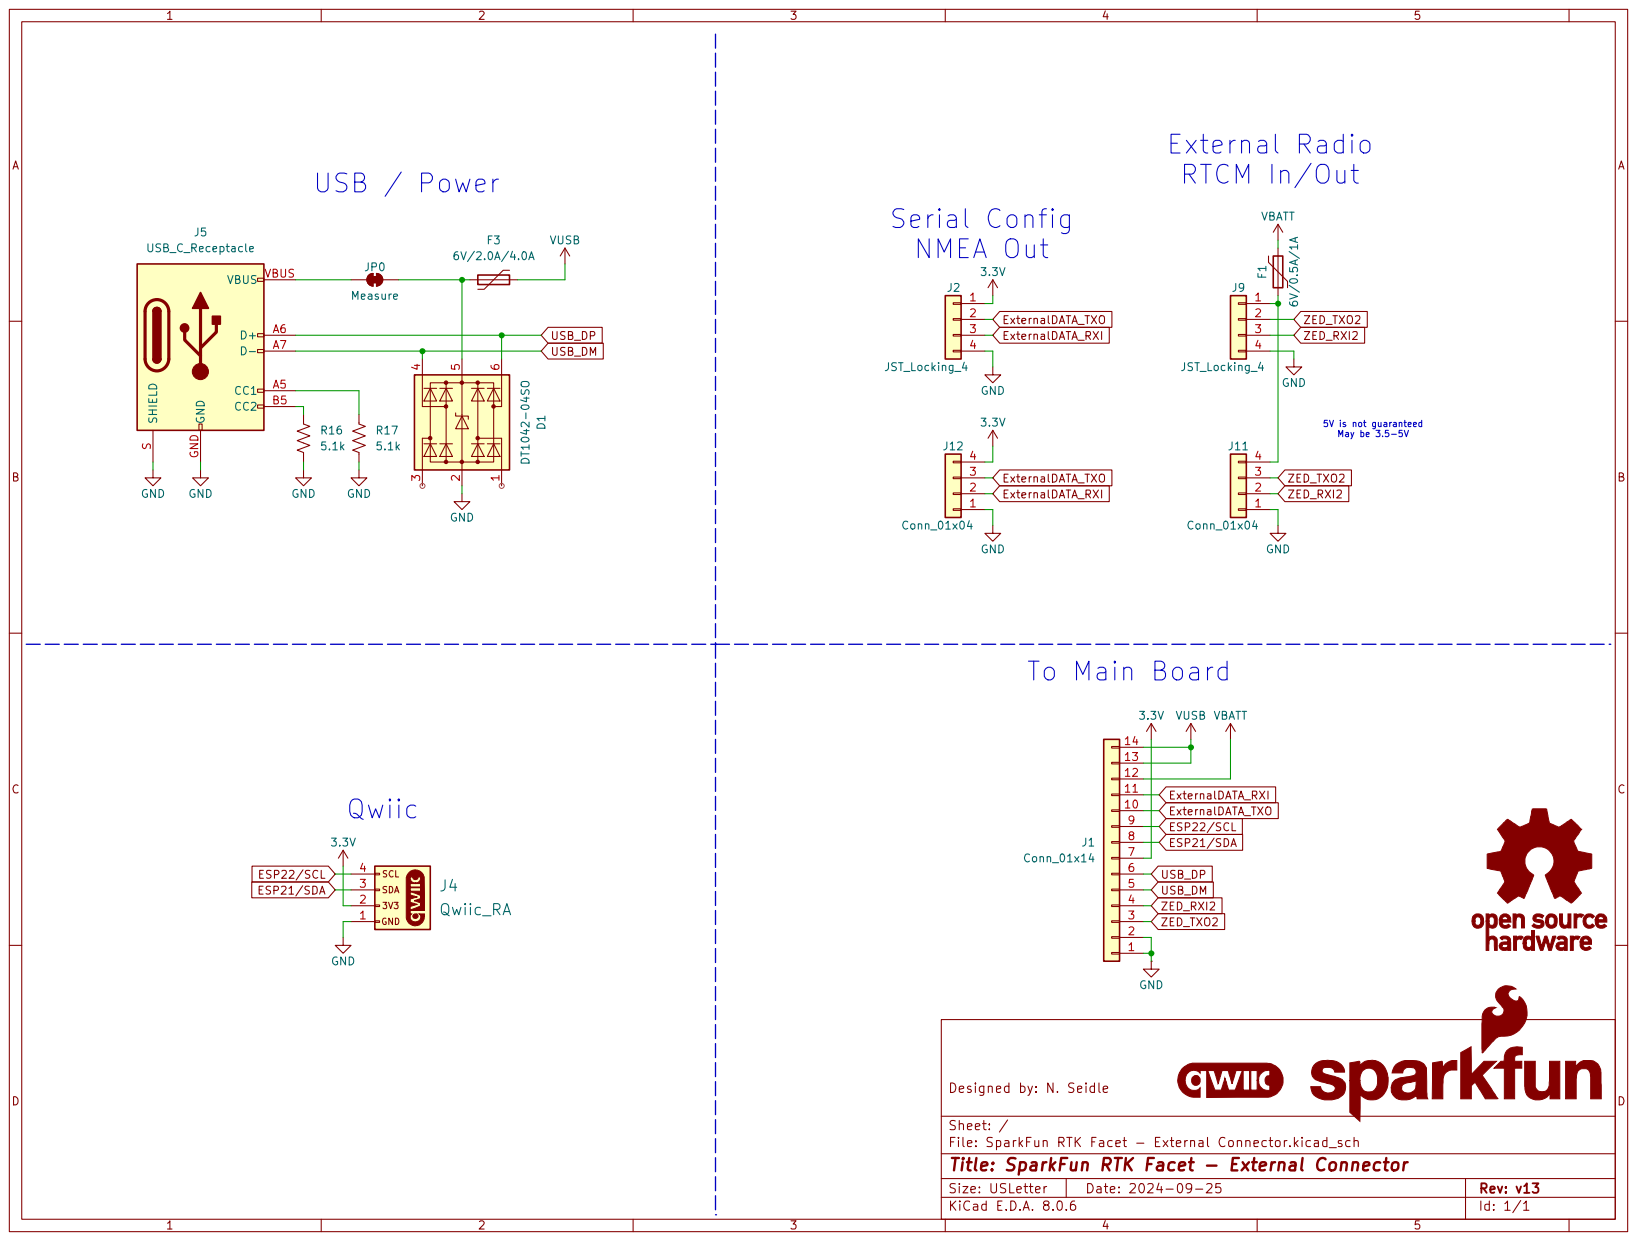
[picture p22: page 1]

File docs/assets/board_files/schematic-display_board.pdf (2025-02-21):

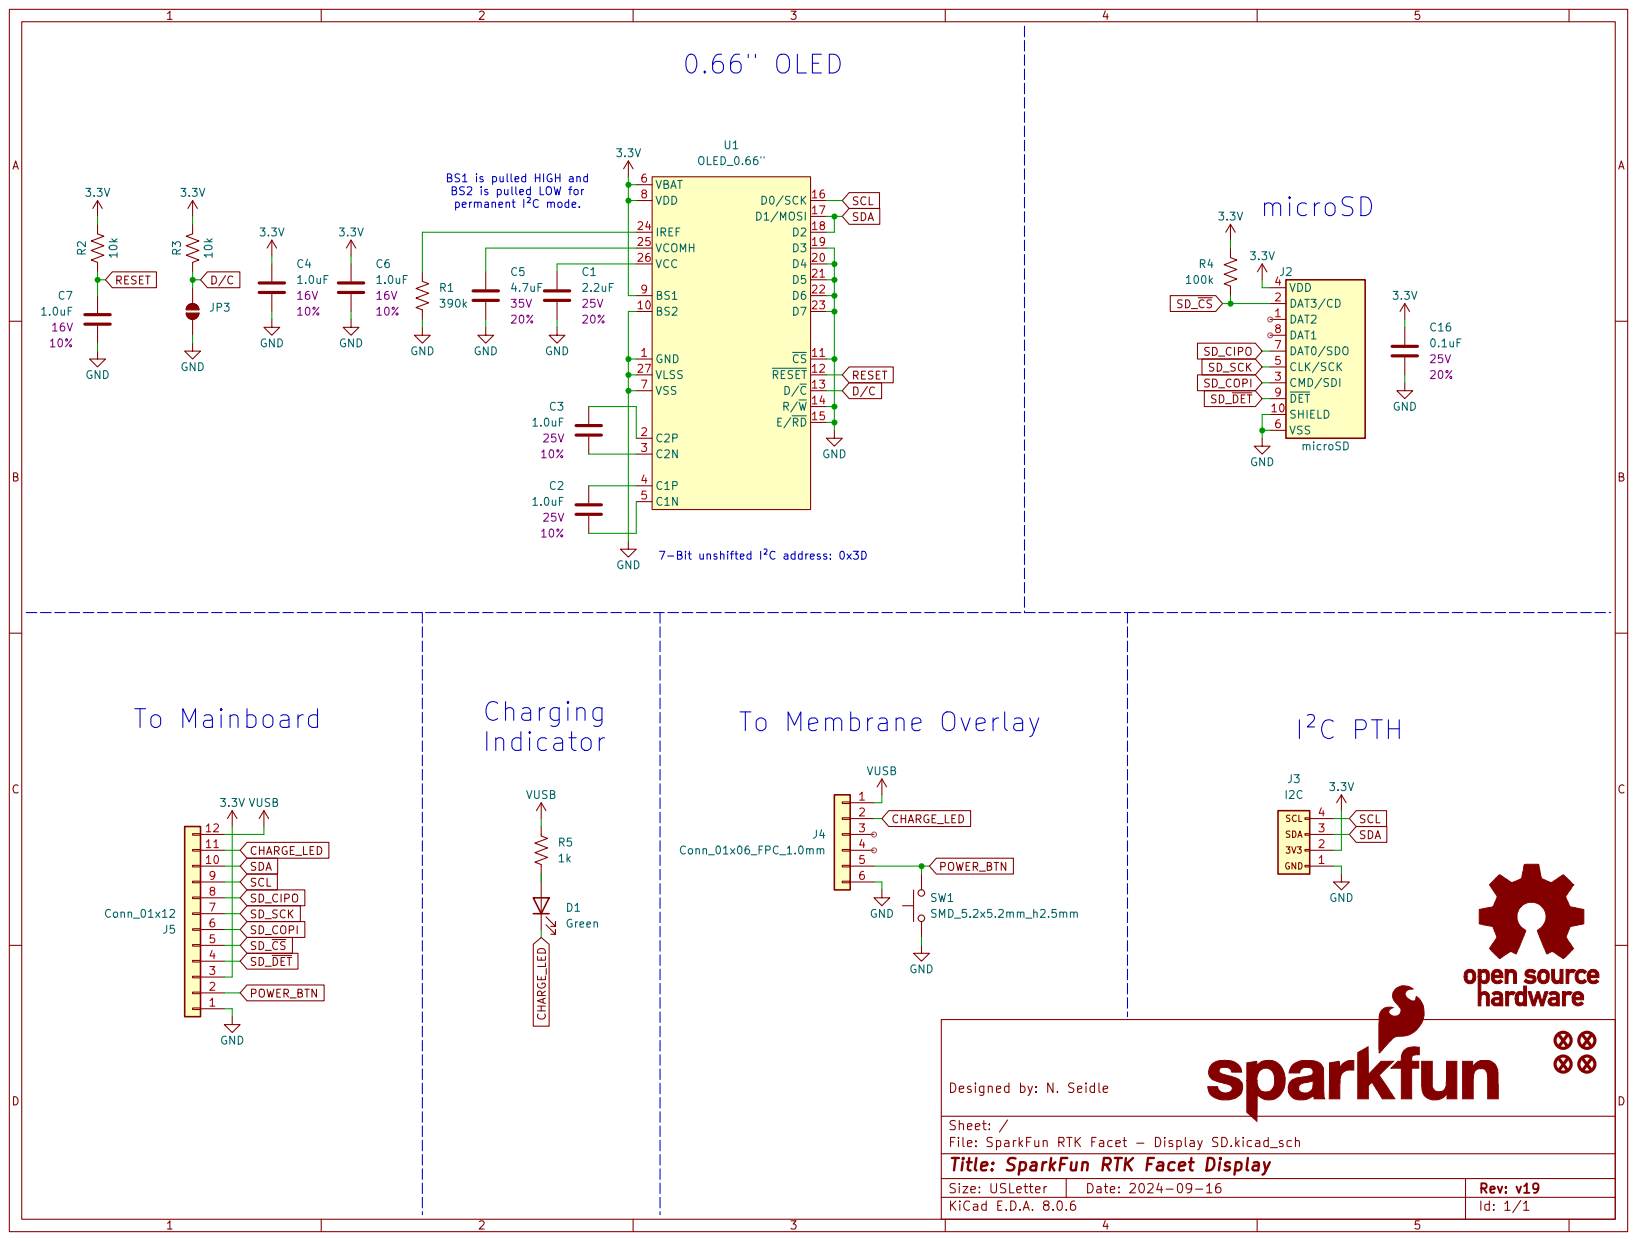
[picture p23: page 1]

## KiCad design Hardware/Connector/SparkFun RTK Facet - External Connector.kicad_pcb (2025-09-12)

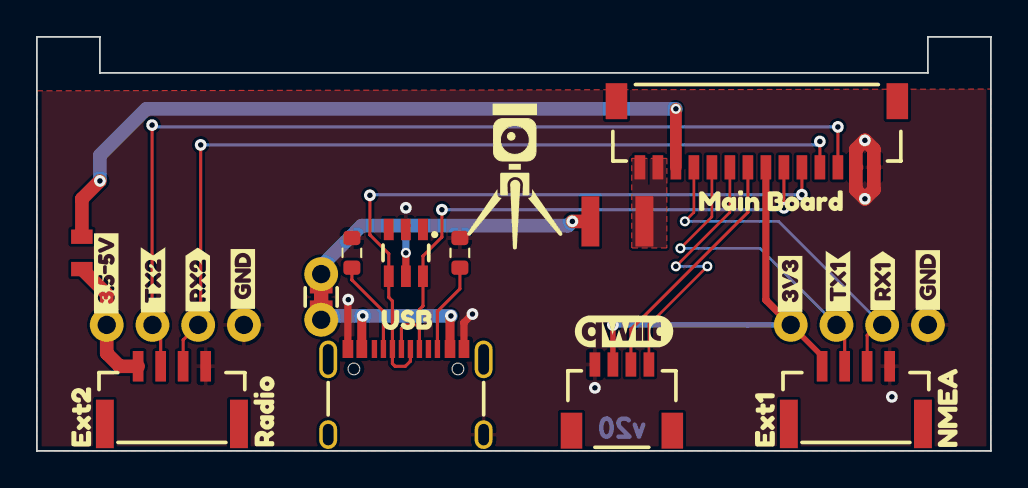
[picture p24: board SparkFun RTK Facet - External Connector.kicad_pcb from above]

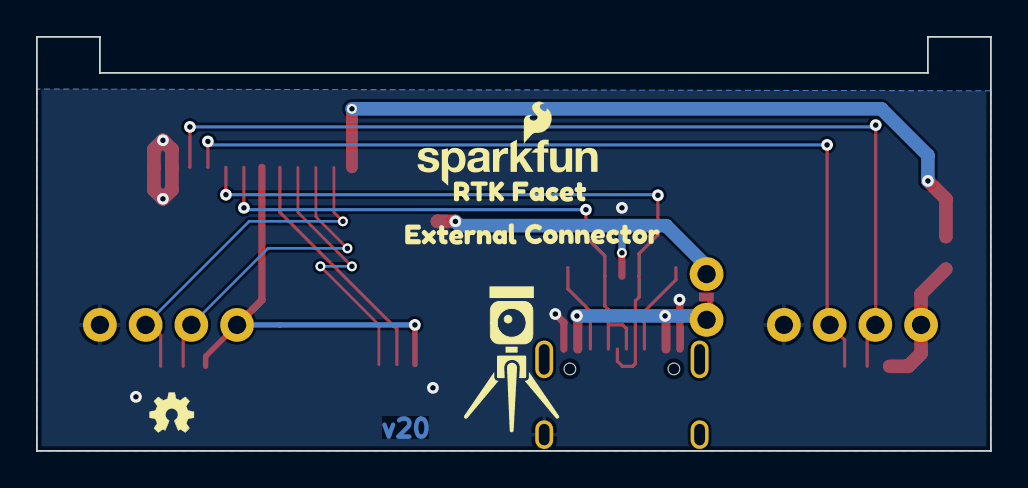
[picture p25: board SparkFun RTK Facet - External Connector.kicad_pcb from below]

Board: 2 copper layers, 53.0 x 23.0 mm, 35 parts (6 on the bottom side), 17 nets.

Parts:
D1: DT1042-04SO; SOT23-6
F1: 6V/0.5A/1A; 0805
F3: 6V/2.0A/4.0A; 1210
G3: OSHW_Logo; Creative_Commons_License
J1: Conn_01x14; JST_SMD_1.0mm-14_RA
J2, J9: JST_Locking_4; JST_SMD_1.25mm-4_Locking
J4: Qwiic_RA; JST_SMD_1.0mm-4_RA
J5: USB_C_Receptacle; USB-C_16
J11, J12: Conn_01x04; 1x04
JP0: Measure; Jumper_2_PTH_SMD_Combo-NC
LOGO1: OSHW-LOGOMINI; OSHW_Logo_2.5mm
LOGO2: SFE_LOGO_NAME_FLAME.1_INCH; SparkFun_Logo_10mm
R16, R17: 5.1k; R_0603_1608Metric
Ref**: Val**; SparkFun_RTK_20mm
Ref**#2: Val**; SparkFun_RTK_20mm
kibuzzard-66F4BFD6: G***; kibuzzard-66F4BFD6
kibuzzard-66F4BFE6: G***; kibuzzard-66F4BFE6
kibuzzard-66F4BFEC: G***; kibuzzard-66F4BFEC
kibuzzard-66F4C0A3: G***; kibuzzard-66F4C0A3
kibuzzard-66F4C0CF: G***; kibuzzard-66F4C0CF
kibuzzard-66F4C0D4: G***; kibuzzard-66F4C0D4
kibuzzard-66F4C0DF: G***; kibuzzard-66F4C0DF
kibuzzard-66F4C0F8: G***; kibuzzard-66F4C0F8
kibuzzard-66F4C0FC: G***; kibuzzard-66F4C0FC
kibuzzard-66F4C1AD: G***; kibuzzard-66F4C1AD
kibuzzard-66F4C03C, kibuzzard-66F4C03C#2: G***; kibuzzard-66F4C03C
kibuzzard-66F4C09A: G***; kibuzzard-66F4C09A
kibuzzard-66F4C18F: G***; kibuzzard-66F4C18F
kibuzzard-66F4C088: G***; kibuzzard-66F4C088
kibuzzard-66F4C199: G***; kibuzzard-66F4C199
kibuzzard-66FF0C1C: G***; kibuzzard-66FF0C1C

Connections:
3.3V: J1.7, J2.1, J4.2, J12.4
ESP21/SDA: J1.8, J4.3
ESP22/SCL: J1.9, J4.4
ExternalDATA_RXI: J1.11, J2.3, J12.2
ExternalDATA_TXO: J1.10, J2.2, J12.3
GND: D1.2 (GND), J1.1, J1.2, J2.4, J4.1, J5.GND, J5.S (SHIELD), J9.4, J11.1, J12.1, R16.2, R17.2
unnamed: D1.5 (VCC), F3.2, JP0.2 (B)
unnamed: J5.A5 (CC1), R17.1
unnamed: J5.B5 (CC2), R16.1
unnamed: F1.2, J9.1, J11.4
unnamed: J5.VBUS, JP0.1 (A)
USB_DM: D1.4 (I/O3), J1.5, J5.A7 (D-), J5.B7 (D-)
USB_DP: D1.6 (I/O4), J1.6, J5.A6 (D+), J5.B6 (D+)
VBATT: F1.1, J1.12
VUSB: F3.1, J1.13, J1.14
ZED_RXI2: J1.4, J9.3, J11.2
ZED_TXO2: J1.3, J9.2, J11.3

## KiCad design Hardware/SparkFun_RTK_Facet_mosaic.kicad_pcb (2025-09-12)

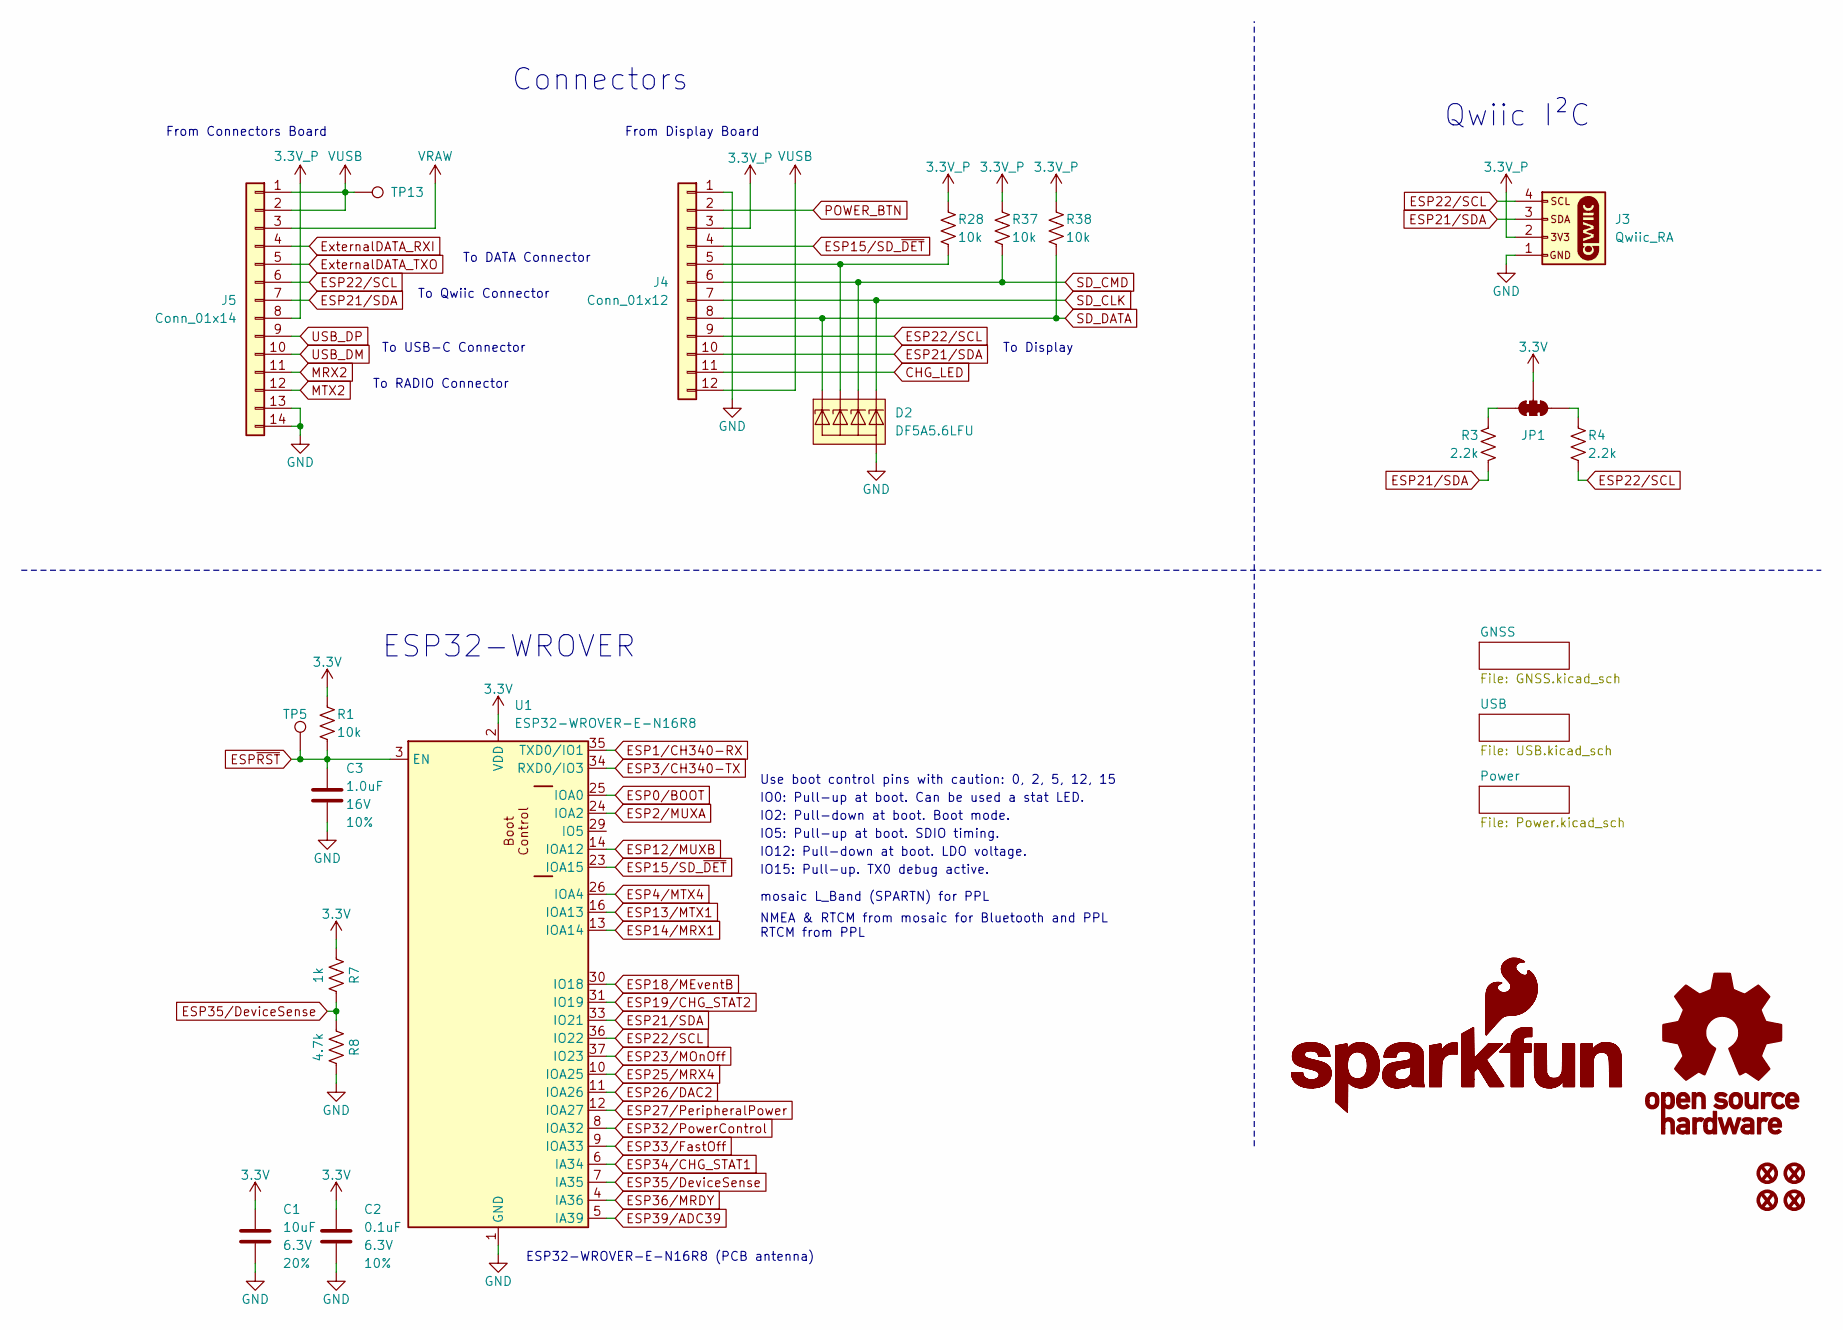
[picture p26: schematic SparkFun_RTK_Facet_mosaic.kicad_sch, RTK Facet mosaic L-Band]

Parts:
C1: 10uF; C_0402_1005Metric; Voltage 6.3V; Tolerance 20%
C2: 0.1uF; C_0402_1005Metric; Voltage 6.3V; Tolerance 10%
C3: 1.0uF; C_0402_1005Metric; Voltage 16V; Tolerance 10%
D2: DF5A5.6LFU; SOT-353
FID1, FID2, FID3, FID4: Fiducial_0.5mm; Fiducial_0.5mm_Mask1mm
G1: OSHW_Logo; Creative_Commons_License
G3: SparkFun_Logo
G5: SparkFun_Logo; SparkFun_Logo_8mm
J3: Qwiic_RA; JST_SMD_1.0mm-4_RA
J4: Conn_01x12; JST_SMD_1.0mm-12_RA
J5: Conn_01x14; JST_SMD_1.0mm-14_RA
JP1: Jumper_3_NC-2_Trace
R1, R28, R37, R38: 10k; R_0402_1005Metric
R3, R4: 2.2k; R_0402_1005Metric
R7: 1k; R_0402_1005Metric
R8: 4.7k; R_0402_1005Metric
TP5, TP13: PTH; 1x01
U1: ESP32-WROVER-E-N16R8; ESP32-WROVER-E-IE

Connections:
3.3V: C1.1, C2.1, JP1.2 (C), R1.1, R7.1, U1.2 (VDD); also elsewhere on the board
3.3V_P: J3.2, J4.3, J5.8, R28.1, R37.1, R38.1; also elsewhere on the board
CHG_LED: J4.11; also elsewhere on the board
ESP0/BOOT: U1.25 (IOA0); also elsewhere on the board
ESP1/CH340-RX: U1.35 (TXD0/IO1); also elsewhere on the board
ESP2/MUXA: U1.24 (IOA2); also elsewhere on the board
ESP3/CH340-TX: U1.34 (RXD0/IO3); also elsewhere on the board
ESP4/MTX4: U1.26 (IOA4); also elsewhere on the board
ESP12/MUXB: U1.14 (IOA12); also elsewhere on the board
ESP13/MTX1: U1.16 (IOA13); also elsewhere on the board
ESP14/MRX1: U1.13 (IOA14); also elsewhere on the board
ESP15/SD_~DET: J4.4, U1.23 (IOA15)
ESP18/MEventB: U1.30 (IO18); also elsewhere on the board
ESP19/CHG_STAT2: U1.31 (IO19); also elsewhere on the board
ESP23/MOnOff: U1.37 (IO23); also elsewhere on the board
ESP25/MRX4: U1.10 (IOA25); also elsewhere on the board
ESP26/DAC2: U1.11 (IOA26); also elsewhere on the board
ESP27/PeripheralPower: U1.12 (IOA27); also elsewhere on the board
ESP32/PowerControl: U1.8 (IOA32); also elsewhere on the board
ESP33/FastOff: U1.9 (IOA33); also elsewhere on the board
ESP34/CHG_STAT1: U1.6 (IA34); also elsewhere on the board
ESP35/DeviceSense: R7.2, R8.1, U1.7 (IA35)
ESP36/MRDY: U1.4 (IA36); also elsewhere on the board
ESP39/ADC39: U1.5 (IA39); also elsewhere on the board
ExternalDATA_RXI: J5.4; also elsewhere on the board
ExternalDATA_TXO: J5.5; also elsewhere on the board
GND: C1.2, C2.2, C3.2, D2.2 (A), J3.1, J4.1, J5.13, J5.14, R8.2, U1.1 (GND), U1.15 (GND), U1.38 (GND), U1.39.1 (GND), U1.39.2 (GND), U1.39.3 (GND), U1.39.4 (GND), U1.39.5 (GND), U1.39.6 (GND), U1.39.7 (GND), U1.39.8 (GND), U1.39.9 (GND); also elsewhere on the board
MRX2: J5.11; also elsewhere on the board
MTX2: J5.12; also elsewhere on the board
unnamed: D2.3 (K2), J4.5, R28.2
POWER_BTN: J4.2; also elsewhere on the board
SD_CLK: D2.5 (K4), J4.7; also elsewhere on the board
SD_CMD: D2.4 (K3), J4.6, R37.2; also elsewhere on the board
SD_DATA: D2.1 (K1), J4.8, R38.2; also elsewhere on the board
USB_DM: J5.10; also elsewhere on the board
USB_DP: J5.9; also elsewhere on the board
VRAW: J5.3; also elsewhere on the board
VUSB: J4.12, J5.1, J5.2, TP13.1; also elsewhere on the board

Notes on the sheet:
IO15: Pull-up. TX0 debug active.
IO2: Pull-down at boot. Boot mode.
To Display
To DATA Connector
To Qwiic Connector
ESP32-WROVER
IO0: Pull-up at boot. Can be used a stat LED.
mosaic L_Band (SPARTN) for PPL
Qwiic I²C
To RADIO Connector
From Connectors Board
IO5: Pull-up at boot. SDIO timing.
To USB-C Connector
From Display Board
Connectors
Use boot control pins with caution: 0, 2, 5, 12, 15
ESP32-WROVER-E-N16R8 (PCB antenna)
NMEA & RTCM from mosaic for Bluetooth and PPL RTCM from PPL
IO12: Pull-down at boot. LDO voltage.

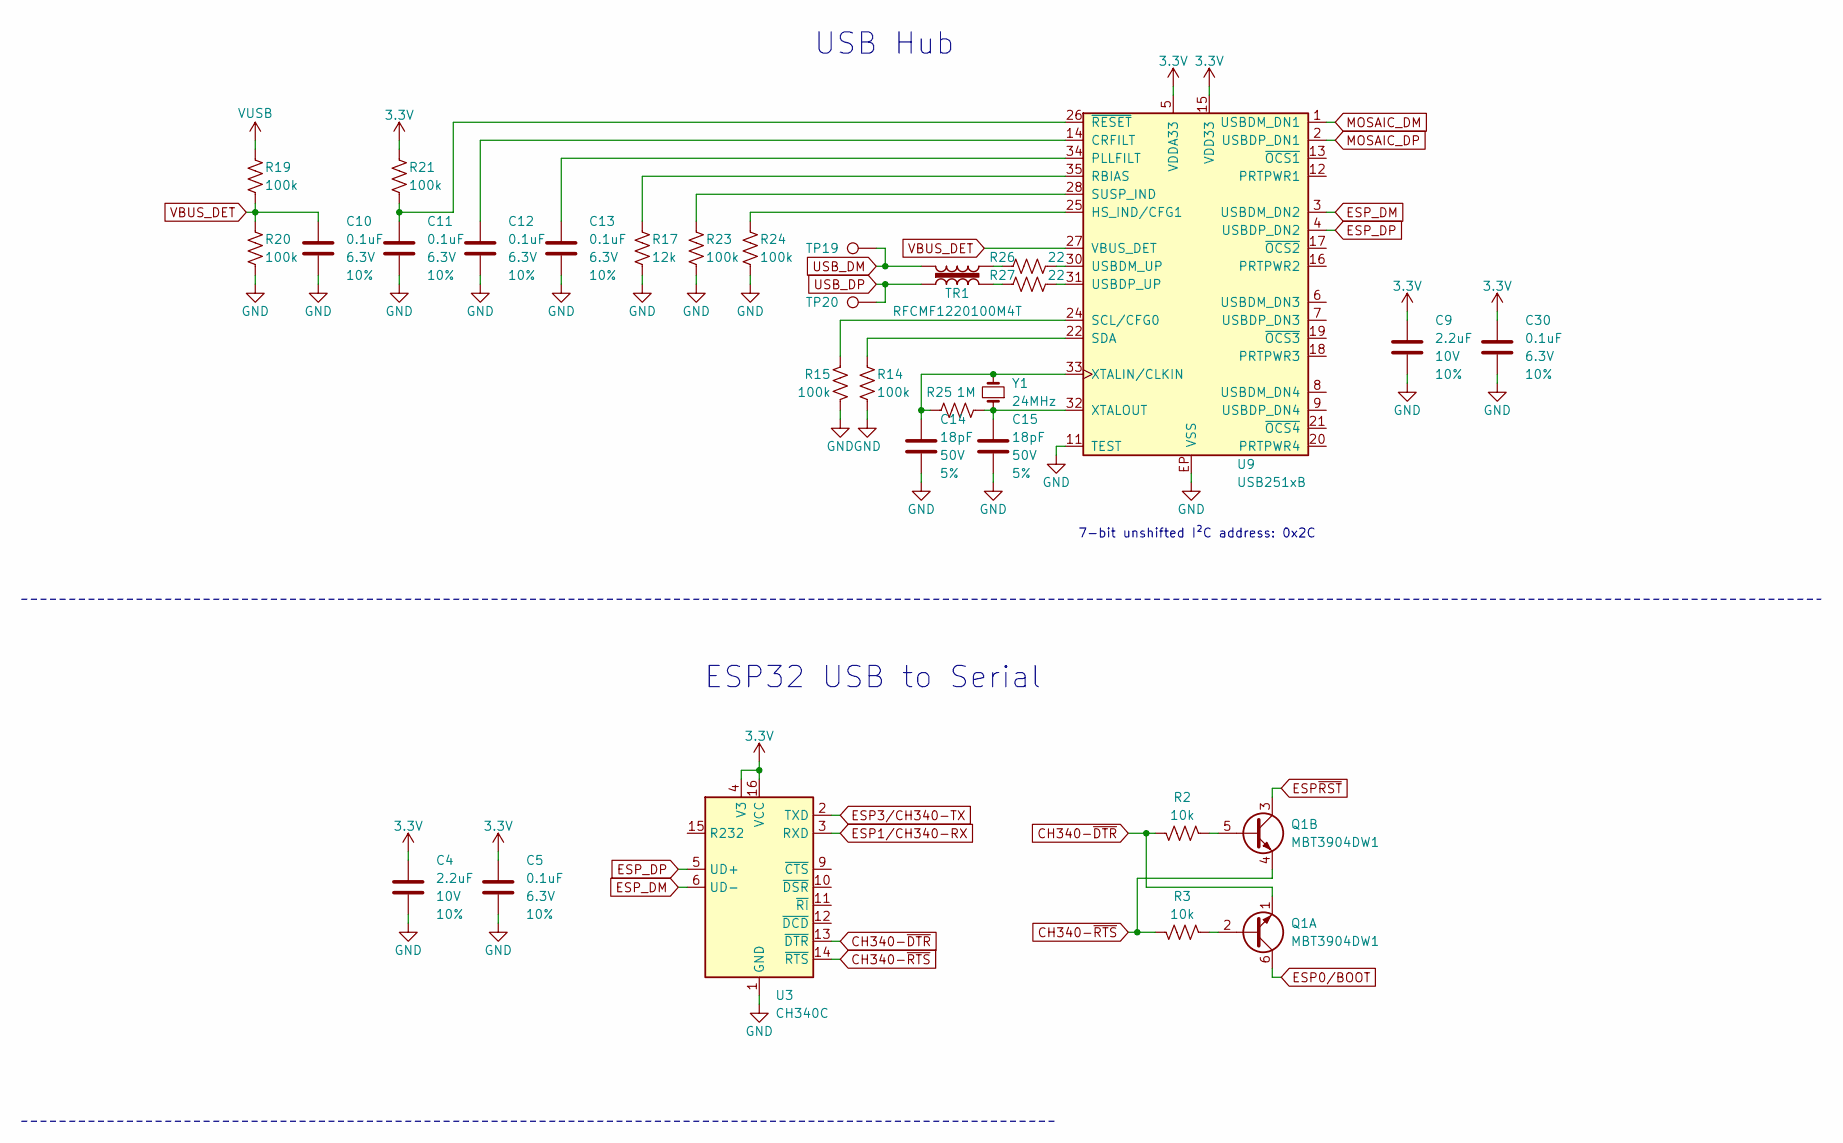
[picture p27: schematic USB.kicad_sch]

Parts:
C4, C9: 2.2uF; C_0402_1005Metric; Voltage 10V; Tolerance 10%
C5, C10, C11, C12, C13, C30: 0.1uF; C_0402_1005Metric; Voltage 6.3V; Tolerance 10%
C14, C15: 18pF; C_0603_1608Metric; Voltage 50V; Tolerance 5%
Q1: MBT3904DW1; SOT-323
R2, R3: 10k; R_0402_1005Metric
R14, R15, R19, R20, R21, R23, R24: 100k; R_0402_1005Metric
R17: 12k; R_0402_1005Metric
R25: 1M; R_0402_1005Metric
R26, R27: 22; R_0402_1005Metric
TP19, TP20: 1.0mm; TestPoint-1.0mm
TR1: RFCMF1220100M4T
U3: CH340C; SO-16
U9: USB251xB; QFN-36
Y1: 24MHz; Crystal_SMD_2.0x1.6mm

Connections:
3.3V: C4.1, C5.1, C9.1, C30.1, R21.1, U3.4 (V3), U3.16 (VCC), U9.5 (VDDA33), U9.10 (VDDA33), U9.15 (VDD33), U9.23 (VDD33), U9.29 (VDDA33), U9.36 (VDDA33); also elsewhere on the board
CH340-~DTR: Q1.1 (E1), R2.2, U3.13 (~DTR)
ESP0/BOOT: Q1.6 (C1); also elsewhere on the board
ESP1/CH340-RX: U3.3 (RXD); also elsewhere on the board
ESP3/CH340-TX: U3.2 (TXD); also elsewhere on the board
ESP_DM: U3.6 (UD-), U9.3 (USBDM_DN2)
ESP_DP: U3.5 (UD+), U9.4 (USBDP_DN2)
GND: C4.2, C5.2, C9.2, C10.2, C11.2, C12.2, C13.2, C14.2, C15.2, C30.2, R14.2, R15.2, R17.1, R20.2, R23.2, R24.2, U3.1 (GND), U9.11 (TEST), U9.EP (VSS); also elsewhere on the board
MOSAIC_DM: U9.1 (USBDM_DN1); also elsewhere on the board
MOSAIC_DP: U9.2 (USBDP_DN1); also elsewhere on the board
unnamed: Q1.5 (B2), R2.1
unnamed: R26.2, TR1.2
unnamed: R27.2, TR1.4
unnamed: C12.1, U9.14 (CRFILT)
unnamed: R24.1, U9.25 (HS_IND/CFG1)
unnamed: C13.1, U9.34 (PLLFILT)
unnamed: R17.2, U9.35 (RBIAS)
unnamed: R15.1, U9.24 (SCL/CFG0)
unnamed: R14.1, U9.22 (SDA)
unnamed: R23.1, U9.28 (SUSP_IND)
unnamed: R26.1, U9.30 (USBDM_UP)
unnamed: R27.1, U9.31 (USBDP_UP)
unnamed: C14.1, R25.2, U9.33 (XTALIN/CLKIN), Y1.2
unnamed: C15.1, R25.1, U9.32 (XTALOUT), Y1.1
unnamed: C11.1, R21.2, U9.26 (~RESET)
USB_DM: TP19.1, TR1.1; also elsewhere on the board
USB_DP: TP20.1, TR1.3; also elsewhere on the board
VBUS_DET: C10.1, R19.2, R20.1, U9.27 (VBUS_DET)
VUSB: R19.1; also elsewhere on the board

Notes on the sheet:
ESP32 USB to Serial
7-bit unshifted I²C address: 0x2C
USB Hub

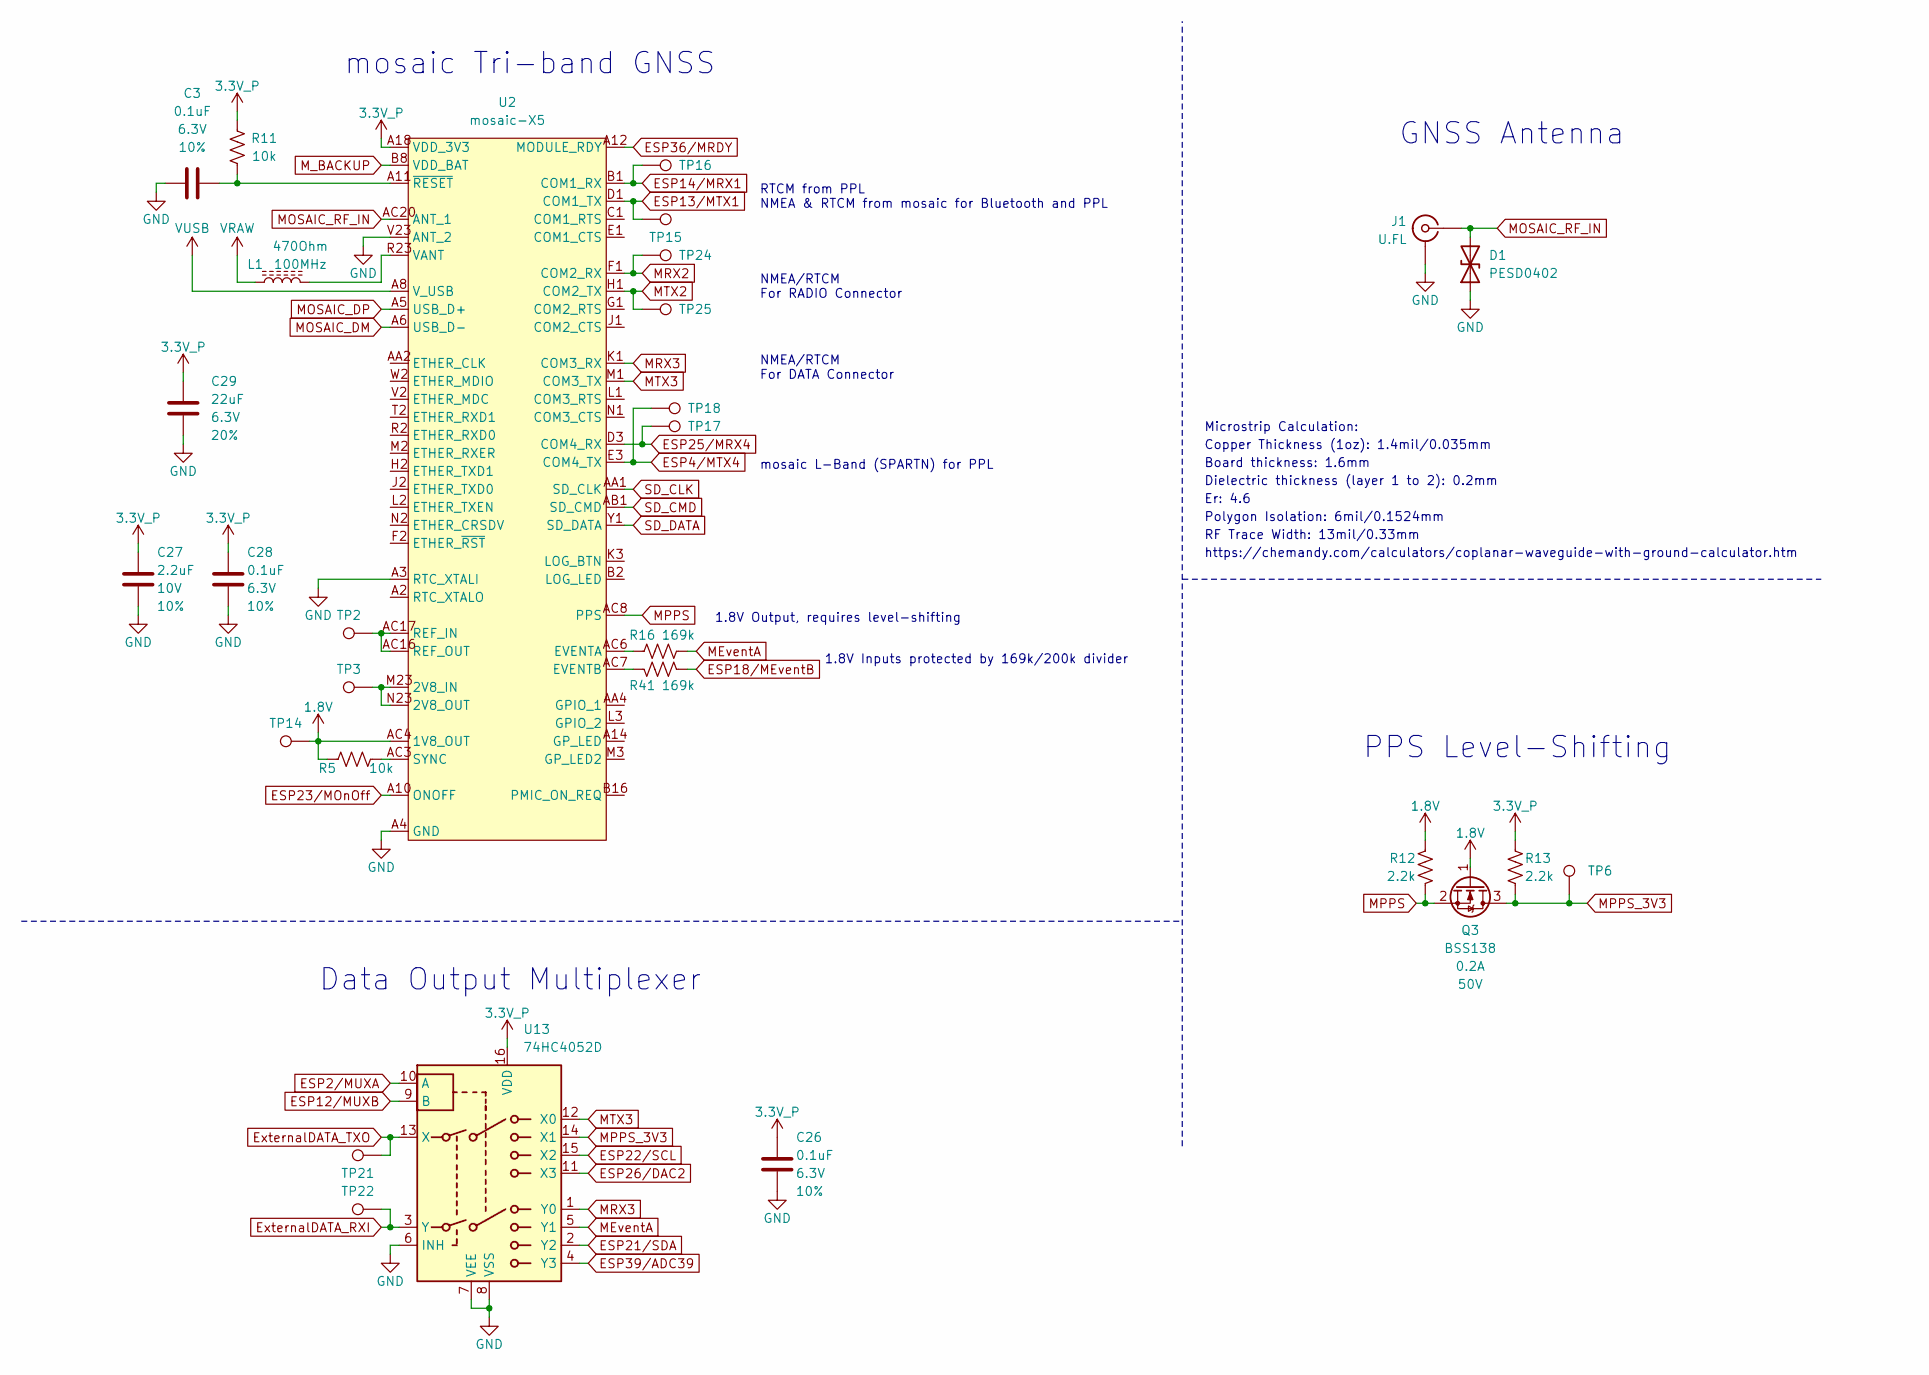
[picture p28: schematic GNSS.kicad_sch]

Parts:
C3, C26, C28: 0.1uF; C_0402_1005Metric; Voltage 6.3V; Tolerance 10%
C27: 2.2uF; C_0402_1005Metric; Voltage 10V; Tolerance 10%
C29: 22uF; C_0603_1608Metric; Voltage 6.3V; Tolerance 20%
D1: PESD0402; C_0402_1005Metric
J1: U.FL
L1: 470Ohm; C_0603_1608Metric
Q3: BSS138; SOT23-3
R5, R11: 10k; R_0402_1005Metric
R12, R13: 2.2k; R_0402_1005Metric
R16, R41: 169k; R_0603_1608Metric
TP2, TP3, TP14, TP15, TP16, TP17, TP18, TP24, TP25: 1.0mm; TestPoint-1.0mm
TP6, TP21, TP22: PTH; 1x01
U2: mosaic-X5; MOSAIC_LGA
U13: 74HC4052D; SO-16

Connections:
1.8V: Q3.1 (G), R5.2, R12.1, TP14.1, U2.AC4 (1V8_OUT)
3.3V_P: C26.1, C27.1, C28.1, C29.1, R11.1, R13.1, U2.A18 (VDD_3V3), U2.A19 (VDD_3V3), U2.A20 (VDD_3V3), U2.B18 (VDD_3V3), U2.B19 (VDD_3V3), U2.B20 (VDD_3V3), U2.C18 (VDD_3V3), U2.C19 (VDD_3V3), U2.C20 (VDD_3V3), U13.16 (VDD); also elsewhere on the board
ESP2/MUXA: U13.10 (A); also elsewhere on the board
ESP4/MTX4: TP18.1, U2.E3 (COM4_TX); also elsewhere on the board
ESP12/MUXB: U13.9 (B); also elsewhere on the board
ESP13/MTX1: TP15.1, U2.D1 (COM1_TX); also elsewhere on the board
ESP14/MRX1: TP16.1, U2.B1 (COM1_RX); also elsewhere on the board
ESP18/MEventB: R41.1; also elsewhere on the board
ESP23/MOnOff: U2.A10 (ONOFF); also elsewhere on the board
ESP25/MRX4: TP17.1, U2.D3 (COM4_RX); also elsewhere on the board
ESP26/DAC2: U13.11 (X3); also elsewhere on the board
ESP36/MRDY: U2.A12 (MODULE_RDY); also elsewhere on the board
ESP39/ADC39: U13.4 (Y3); also elsewhere on the board
ExternalDATA_RXI: TP22.1, U13.3 (Y); also elsewhere on the board
ExternalDATA_TXO: TP21.1, U13.13 (X); also elsewhere on the board
GND: C3.2, C26.2, C27.2, C28.2, C29.2, D1.1 (A1), J1.2 (Ext), U2.A3 (RTC_XTALI), U2.A4 (GND), U2.A7 (GND), U2.A15 (GND), U2.A16 (GND), U2.A17 (GND), U2.A21 (GND), U2.A22 (GND), U2.A23 (GND), U2.AA13 (GND), U2.AA14 (GND), U2.AA15 (GND), U2.AA16 (GND), U2.AA17 (GND), U2.AA18 (GND), U2.AA19 (GND), U2.AA20 (GND), U2.AA21 (GND), U2.AA22 (GND), U2.AA23 (GND), U2.AB2 (GND), U2.AB3 (GND), U2.AB4 (GND), U2.AB5 (GND), U2.AB6 (GND), U2.AB7 (GND), U2.AB8 (GND), U2.AB13 (GND), U2.AB14 (GND), U2.AB15 (GND), U2.AB16 (GND), U2.AB17 (GND), U2.AB18 (GND), U2.AB19 (GND), U2.AB20 (GND), U2.AB21 (GND), U2.AB22 (GND), U2.AB23 (GND), U2.AC13 (GND), U2.AC15 (GND), U2.AC18 (GND), U2.AC19 (GND), U2.AC21 (GND), U2.AC22 (GND), U2.AC23 (GND), U2.B4 (GND), U2.B5 (GND), U2.B6 (GND), U2.B7 (GND), U2.B13 (GND), U2.B17 (GND), U2.B21 (GND), U2.C4 (GND), U2.C7 (GND), U2.C15 (GND), U2.C16 (GND), U2.C17 (GND), U2.C23 (GND), U2.D2 (GND), U2.D21 (GND), U2.D22 (GND), U2.D23 (GND), U2.E2 (GND), U2.E21 (GND), U2.E22 (GND), U2.E23 (GND), U2.F21 (GND), U2.F22 (GND), U2.F23 (GND), U2.G2 (GND), U2.G21 (GND), U2.G23 (GND), U2.H21 (GND), U2.H22 (GND), U2.H23 (GND), U2.J21 (GND), U2.J22 (GND), U2.J23 (GND), U2.K2 (GND), U2.K21 (GND), U2.K22 (GND), U2.K23 (GND), U2.L21 (GND), U2.L22 (GND), U2.L23 (GND), U2.M21 (GND), U2.M22 (GND), U2.N21 (GND), U2.N22 (GND), U2.P1 (GND), U2.P2 (GND), U2.P3 (GND), U2.P21 (GND), U2.P22 (GND), U2.R3 (GND), U2.R21 (GND), U2.R22 (GND), U2.T21 (GND), U2.T22 (GND), U2.T23 (GND), U2.U2 (GND), U2.U21 (GND), U2.U22 (GND), U2.U23 (GND), U2.V21 (GND), U2.V22 (GND), U2.V23 (ANT_2), U2.W21 (GND), U2.W22 (GND), U2.W23 (GND), U2.Y2 (GND), U2.Y21 (GND), U2.Y22 (GND), U2.Y23 (GND), U13.6 (INH), U13.7 (VEE), U13.8 (VSS); also elsewhere on the board
MEventA: R16.1, U13.5 (Y1)
MOSAIC_DM: U2.A6 (USB_D-); also elsewhere on the board
MOSAIC_DP: U2.A5 (USB_D+); also elsewhere on the board
MOSAIC_RF_IN: D1.2 (A2), J1.1 (In), U2.AC20 (ANT_1)
MPPS: Q3.2 (S), R12.2, U2.AC8 (PPS)
MPPS_3V3: Q3.3 (D), R13.2, TP6.1, U13.14 (X1)
MRX2: TP24.1, U2.F1 (COM2_RX); also elsewhere on the board
MRX3: U2.K1 (COM3_RX), U13.1 (Y0)
MTX2: TP25.1, U2.H1 (COM2_TX); also elsewhere on the board
MTX3: U2.M1 (COM3_TX), U13.12 (X0)
M_BACKUP: U2.B8 (VDD_BAT); also elsewhere on the board
unnamed: TP3.1, U2.M23 (2V8_IN), U2.N23 (2V8_OUT)
unnamed: R16.2, U2.AC6 (EVENTA)
unnamed: R41.2, U2.AC7 (EVENTB)
unnamed: TP2.1, U2.AC16 (REF_OUT), U2.AC17 (REF_IN)
unnamed: R5.1, U2.AC3 (SYNC)
SD_CLK: U2.AA1 (SD_CLK); also elsewhere on the board
SD_CMD: U2.AB1 (SD_CMD); also elsewhere on the board
SD_DATA: U2.Y1 (SD_DATA); also elsewhere on the board
VANT: L1.2, U2.P23 (VANT), U2.R23 (VANT)
VRAW: L1.1; also elsewhere on the board
VUSB: U2.A8 (V_USB); also elsewhere on the board

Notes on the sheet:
Er: 4.6
mosaic L-Band (SPARTN) for PPL
Polygon Isolation: 6mil/0.1524mm
Dielectric thickness (layer 1 to 2): 0.2mm
RTCM from PPL NMEA & RTCM from mosaic for Bluetooth and PPL
Board thickness: 1.6mm
mosaic Tri-band GNSS
Microstrip Calculation:
NMEA/RTCM For RADIO Connector
Data Output Multiplexer
NMEA/RTCM For DATA Connector
https://chemandy.com/calculators/coplanar-waveguide-with-ground-calculator.htm
Copper Thickness (1oz): 1.4mil/0.035mm
PPS Level-Shifting
1.8V Output, requires level-shifting
1.8V Inputs protected by 169k/200k divider
GNSS Antenna
RF Trace Width: 13mil/0.33mm

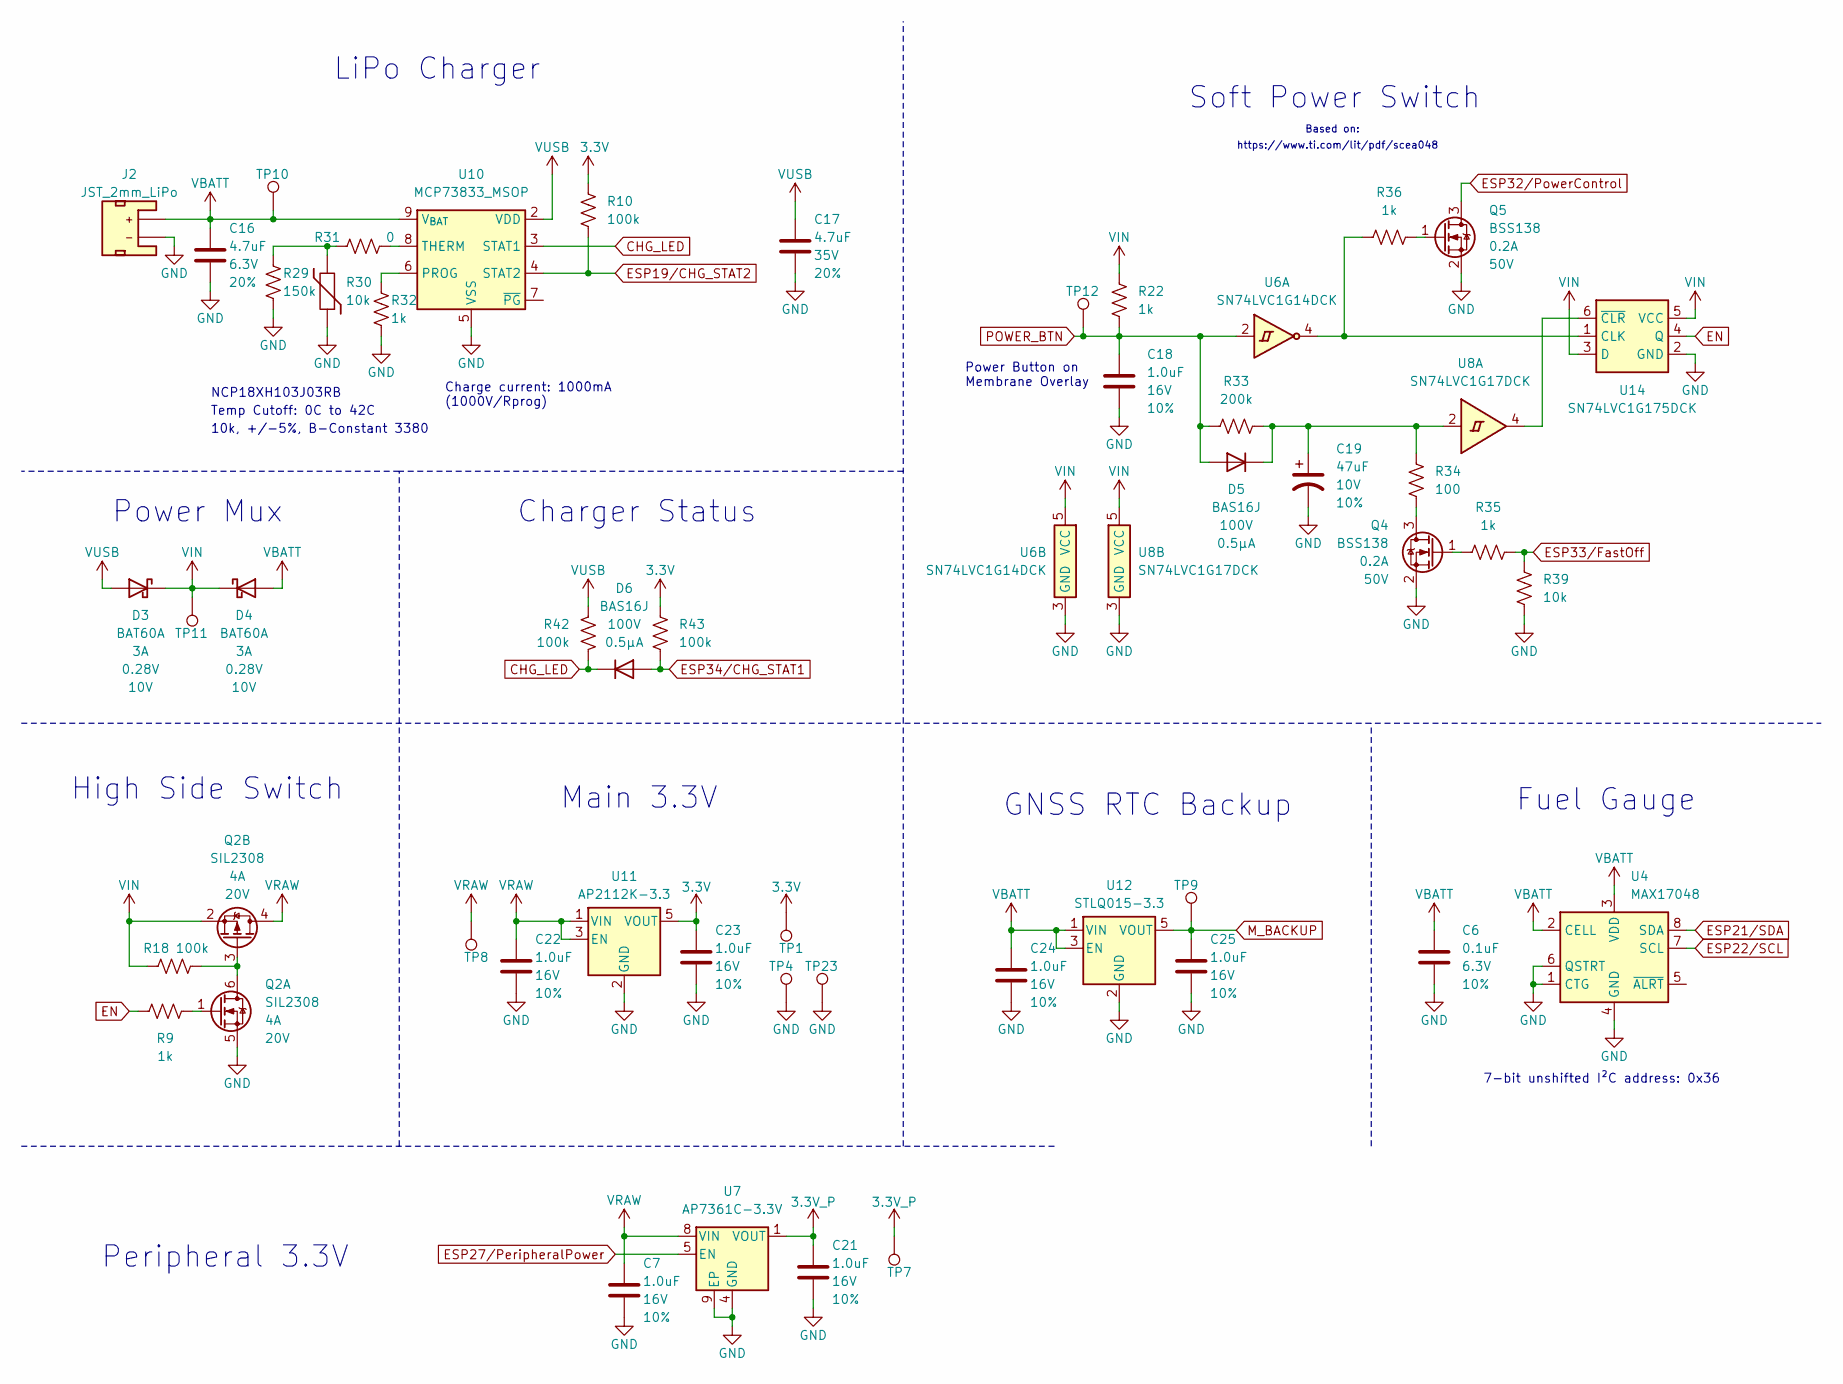
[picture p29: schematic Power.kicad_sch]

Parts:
C6: 0.1uF; C_0402_1005Metric; Voltage 6.3V; Tolerance 10%
C7, C18, C21, C22, C23, C24, C25: 1.0uF; C_0402_1005Metric; Voltage 16V; Tolerance 10%
C16: 4.7uF; C_0402_1005Metric; Voltage 6.3V; Tolerance 20%
C17: 4.7uF; C_0603_1608Metric; Voltage 35V; Tolerance 20%
C19: 47uF; EIA-3528; Voltage 10V; Tolerance 10%
D3, D4: BAT60A; SOD-323
D5, D6: BAS16J; SOD-323
J2: JST_2mm_LiPo; JST_SMD_2.0mm-2
Q2: SIL2308; SOT23-6-Tight
Q4, Q5: BSS138; SOT23-3
R9, R22, R32, R35, R36: 1k; R_0402_1005Metric
R10, R18, R42, R43: 100k; R_0402_1005Metric
R29: 150k; R_0402_1005Metric
R30: 10k; R_0603_1608Metric
R31: 0; R_0402_1005Metric
R33: 200k; R_0402_1005Metric
R34: 100; R_0603_1608Metric
R39: 10k; R_0402_1005Metric
TP1, TP4, TP7, TP8, TP9, TP10, TP11, TP12, TP23: PTH; 1x01
U4: MAX17048; DFN-8
U6: SN74LVC1G14DCK; SOT-353
U7: AP7361C-3.3V; UDFN-8
U8: SN74LVC1G17DCK; SOT-353
U10: MCP73833_MSOP; MSOP-10_3x3mm_P0.5mm
U11: AP2112K-3.3; SOT23-5
U12: STLQ015-3.3; SOT23-5
U14: SN74LVC1G175DCK; SOT-323

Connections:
3.3V: C23.1, R10.1, R43.1, TP1.1, U11.5 (VOUT); also elsewhere on the board
3.3V_P: C21.1, TP7.1, U7.1 (VOUT); also elsewhere on the board
CHG_LED: D6.C, R42.2, U10.3 (STAT1); also elsewhere on the board
EN: R9.2, U14.4 (Q)
ESP19/CHG_STAT2: R10.2, U10.4 (STAT2); also elsewhere on the board
ESP27/PeripheralPower: U7.5 (EN); also elsewhere on the board
ESP32/PowerControl: Q5.3 (D); also elsewhere on the board
ESP33/FastOff: R35.2, R39.1; also elsewhere on the board
ESP34/CHG_STAT1: D6.A, R43.2; also elsewhere on the board
GND: C6.2, C7.2, C16.2, C17.2, C18.2, C19.2, C21.2, C22.2, C23.2, C24.2, C25.2, J2.1 (-), Q2.5 (S), Q4.2 (S), Q5.2 (S), R29.2, R30.1, R32.2, R39.2, TP4.1, TP23.1, U4.1 (CTG), U4.4 (GND), U4.6 (QSTRT), U4.9 (GND), U6.3 (GND), U7.4 (GND), U7.9 (EP), U8.3 (GND), U10.5 (VSS), U11.2 (GND), U12.2 (GND), U14.2 (GND); also elsewhere on the board
M_BACKUP: C25.1, TP9.1, U12.5 (VOUT); also elsewhere on the board
unnamed: C19.1, D5.C, R33.1, R34.1, U8.2
unnamed: Q2.3 (G), Q2.6 (D), R18.1
unnamed: Q2.1 (G), R9.1
unnamed: Q4.3 (D), R34.2
unnamed: Q4.1 (G), R35.1
unnamed: Q5.1 (G), R36.2
unnamed: R29.1, R30.2, R31.2
unnamed: R32.1, U10.6 (PROG)
unnamed: R31.1, U10.8 (THERM)
unnamed: R36.1, U6.4, U14.1 (CLK)
unnamed: U8.4, U14.6 (~CLR)
POWER_BTN: C18.1, D5.A, R22.2, R33.2, TP12.1, U6.2; also elsewhere on the board
VBATT: C6.1, C16.1, C24.1, D4.A, J2.2 (+), TP10.1, U4.2 (CELL), U4.3 (VDD), U10.9 (V_{BAT}), U10.10 (V_{BAT}), U12.1 (VIN), U12.3 (EN)
VIN: D3.C, D4.C, Q2.2 (1), R18.2, R22.1, TP11.1, U6.5 (VCC), U8.5 (VCC), U14.3 (D), U14.5 (VCC)
VRAW: C7.1, C22.1, Q2.4 (D), TP8.1, U7.8 (VIN), U11.1 (VIN), U11.3 (EN); also elsewhere on the board
VUSB: C17.1, D3.A, R42.1, U10.1 (VDD), U10.2 (VDD); also elsewhere on the board

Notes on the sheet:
High Side Switch
Charge current: 1000mA (1000V/Rprog)
Power Button on Membrane Overlay
Based on:
GNSS RTC Backup
Temp Cutoff: 0C to 42C
10k, +/-5%, B-Constant 3380
NCP18XH103J03RB
Soft Power Switch
LiPo Charger
Charger Status
Power Mux
Fuel Gauge
https://www.ti.com/lit/pdf/scea048
Peripheral 3.3V
Main 3.3V
7-bit unshifted I²C address: 0x36

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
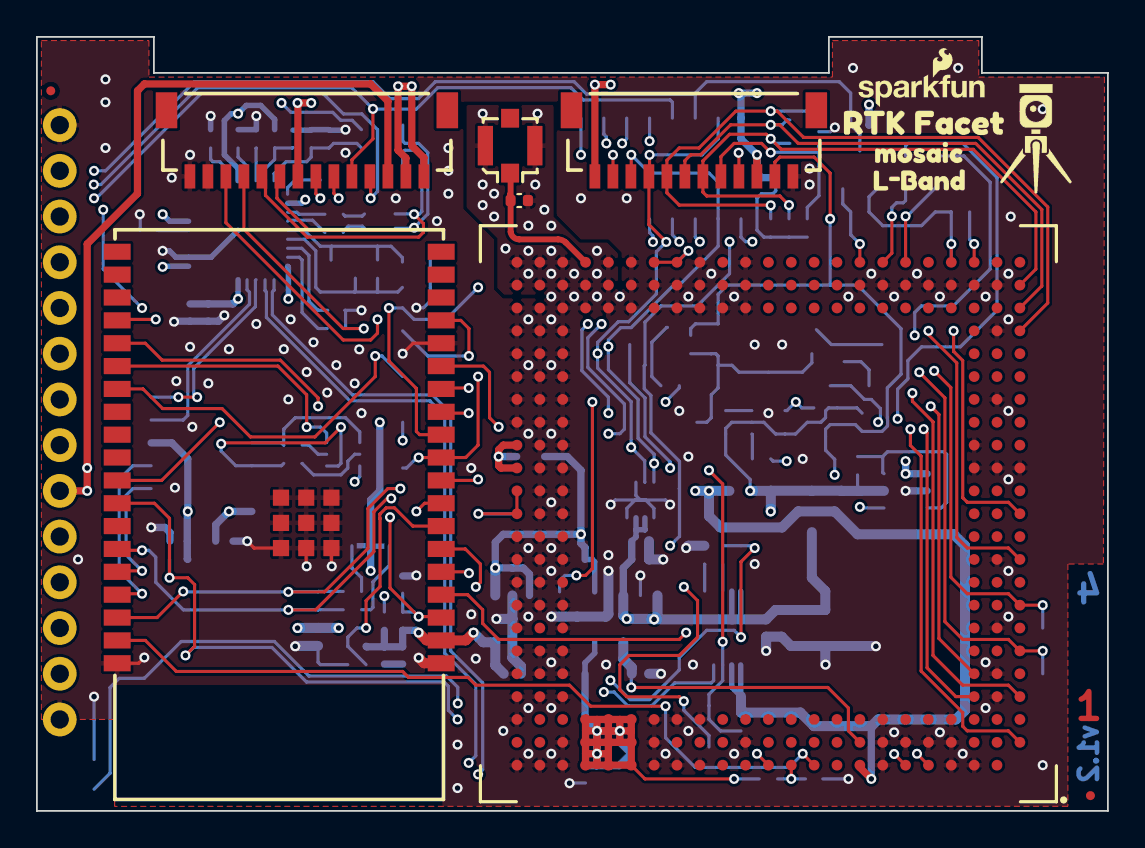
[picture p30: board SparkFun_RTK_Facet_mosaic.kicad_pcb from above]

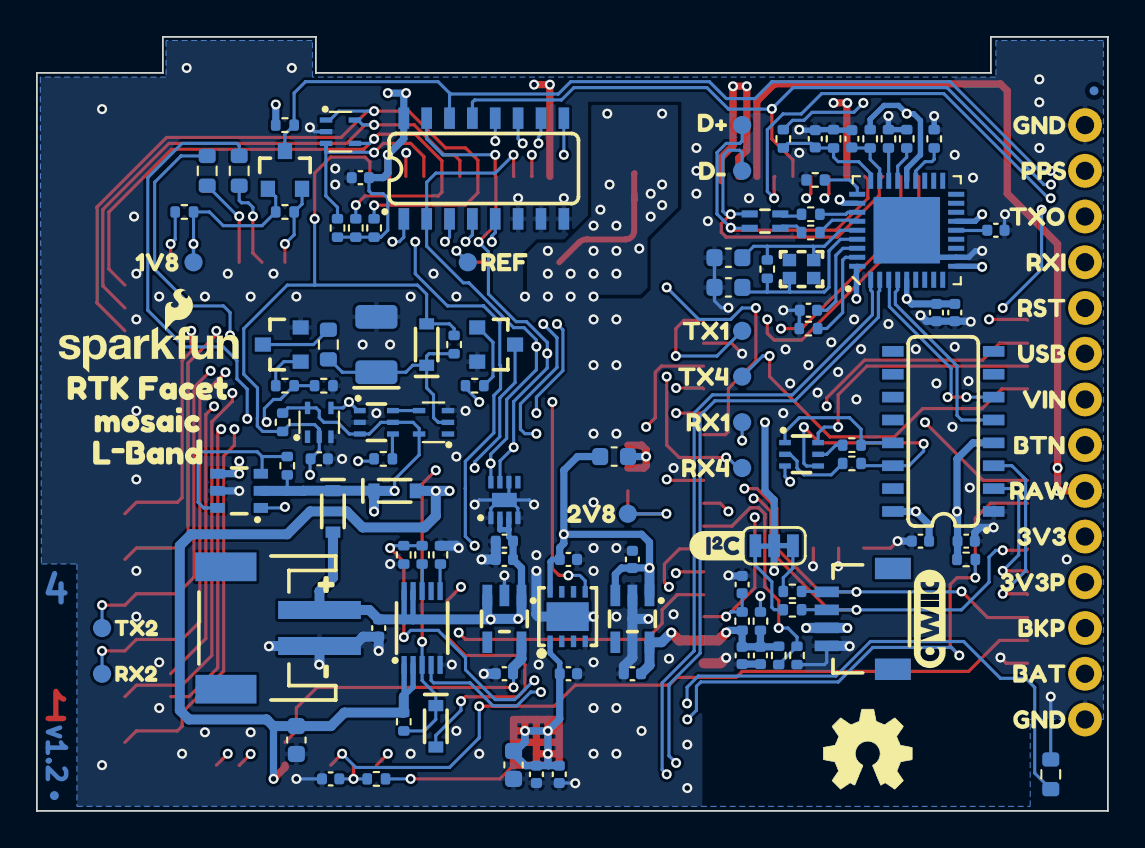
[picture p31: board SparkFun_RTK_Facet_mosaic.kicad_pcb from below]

Board: 4 copper layers, 59.5 x 43.0 mm, 170 parts (143 on the bottom side), 95 nets.

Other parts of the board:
C8: 1.0uF; C_0402_1005Metric
R6: 2.2k; R_0402_1005Metric
Ref**: Val**; SparkFun_RTK_15mm
Ref**#2: Val**; OSHW_Logo_5mm
kibuzzard-65A7F4BF: G***; kibuzzard-65A7F4BF
kibuzzard-65A7F4D6: G***; kibuzzard-65A7F4D6
kibuzzard-65A7F4E8: G***; kibuzzard-65A7F4E8
kibuzzard-65A7F5A7: G***; kibuzzard-65A7F5A7
kibuzzard-65A7F5BC: G***; kibuzzard-65A7F5BC
kibuzzard-65A7F5CF: G***; kibuzzard-65A7F5CF
kibuzzard-65A7F5E3: G***; kibuzzard-65A7F5E3
kibuzzard-65A7F7BA: G***; kibuzzard-65A7F7BA
kibuzzard-65A7F7EA: G***; kibuzzard-65A7F7EA
kibuzzard-65A7F47C: G***; kibuzzard-65A7F47C
kibuzzard-65A7F60E: G***; kibuzzard-65A7F60E
kibuzzard-65A7F63F: G***; kibuzzard-65A7F63F
kibuzzard-65A7F440, kibuzzard-65A7F440#2: G***; kibuzzard-65A7F440
kibuzzard-65A7F499: G***; kibuzzard-65A7F499
kibuzzard-65A7F511: G***; kibuzzard-65A7F511
kibuzzard-65A7F548: G***; kibuzzard-65A7F548
kibuzzard-65A7F565: G***; kibuzzard-65A7F565
kibuzzard-65A7F574: G***; kibuzzard-65A7F574
kibuzzard-65A7F686: G***; kibuzzard-65A7F686
kibuzzard-65A7F697: G***; kibuzzard-65A7F697
kibuzzard-65A7F771: G***; kibuzzard-65A7F771
kibuzzard-65A7F891: G***; kibuzzard-65A7F891
kibuzzard-65AEA1E6: G***; kibuzzard-65AEA1E6
kibuzzard-65AEA201: G***; kibuzzard-65AEA201
kibuzzard-65AEA759: G***; kibuzzard-65AEA759
kibuzzard-670CFFCD: G***; kibuzzard-670CFFCD
kibuzzard-670CFFE9: G***; kibuzzard-670CFFE9
kibuzzard-65776CFF, kibuzzard-65776CFF#2: G***; kibuzzard-65776CFF
kibuzzard-65776D0F: G***; kibuzzard-65776D0F
kibuzzard-65776D09: G***; kibuzzard-65776D09
kibuzzard-65777033: G***; kibuzzard-65777033
kibuzzard-65777037: G***; kibuzzard-65777037

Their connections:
GND: C8.2; also elsewhere on the board

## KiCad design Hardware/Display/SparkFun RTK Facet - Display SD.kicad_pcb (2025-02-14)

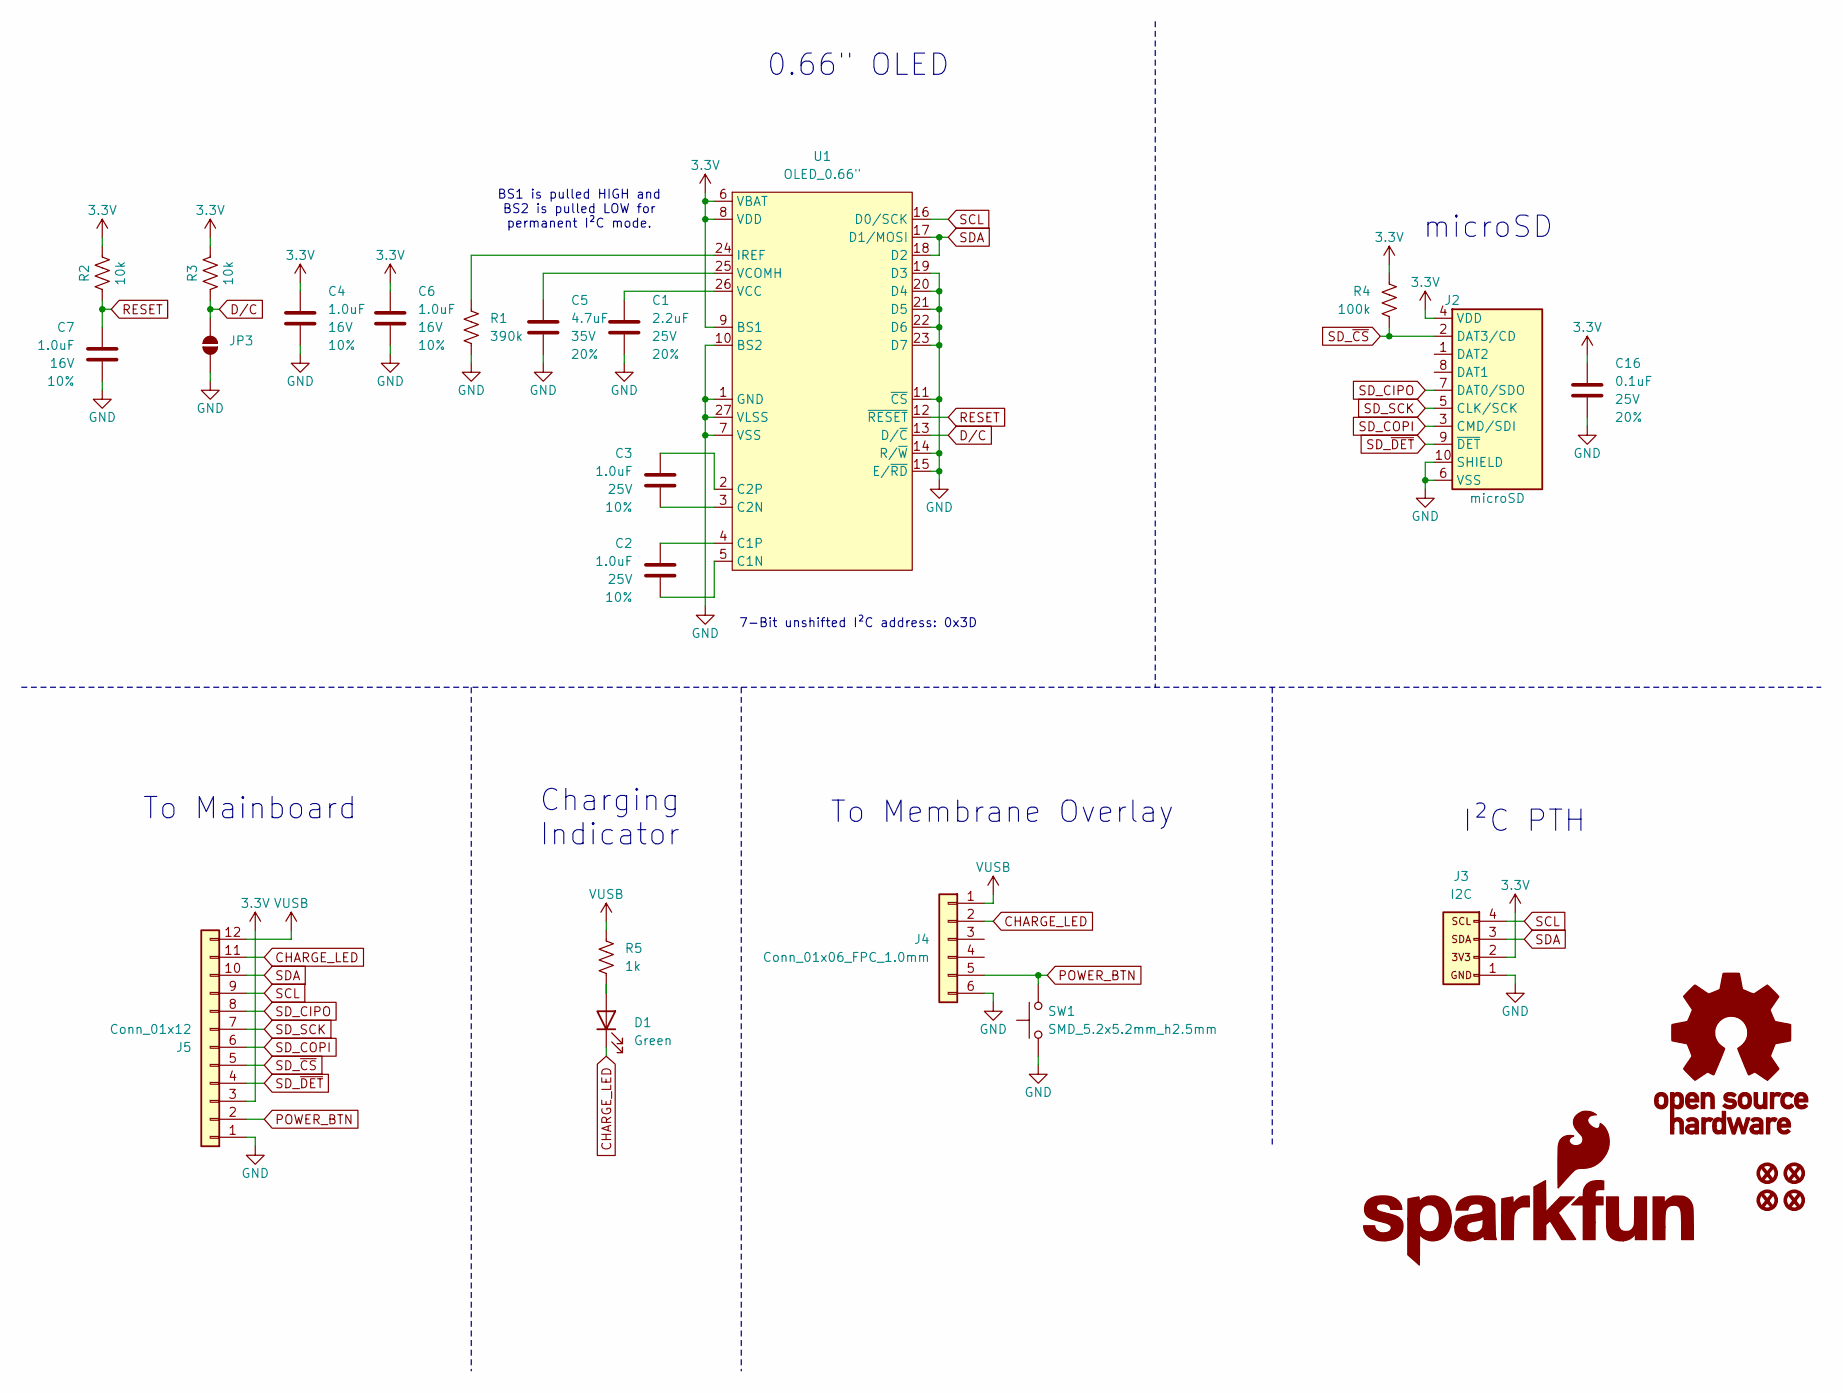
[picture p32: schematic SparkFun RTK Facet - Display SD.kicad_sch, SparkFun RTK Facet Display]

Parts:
C1: 2.2uF; C_0805_2012Metric; Voltage 25V; Tolerance 20%
C2, C3: 1.0uF; C_0805_2012Metric; Voltage 25V; Tolerance 10%
C4, C6, C7: 1.0uF; C_0603_1608Metric; Voltage 16V; Tolerance 10%
C5: 4.7uF; C_0603_1608Metric; Voltage 35V; Tolerance 20%
C16: 0.1uF; C_0603_1608Metric; Voltage 25V; Tolerance 20%
D1: Green; LED_1206_Bottom_Green
FID1, FID2, FID3, FID4: Fiducial_0.5mm; Fiducial_0.5mm_Mask1mm
G1: SparkFun_Logo
G2: OSHW_Logo; Creative_Commons_License
J2: microSD; microSD_External_Pin
J3: I2C; 1x04
J4: Conn_01x06_FPC_1.0mm; FPC_1.0mm-6_LIF
J5: Conn_01x12; JST_SMD_1.0mm-12_RA
JP3: Jumper_2_NO
R1: 390k; R_0603_1608Metric
R2, R3: 10k; R_0603_1608Metric
R4: 100k; R_0603_1608Metric
R5: 1k; R_0402_1005Metric
SW1: SMD_5.2x5.2mm_h2.5mm; Push_SMD_5.2x5.2mm_h2.5mm
U1: OLED_0.66"; OLED_0.66-SMD

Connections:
3.3V: C4.1, C6.1, C16.1, J2.4 (VDD), J3.2, J5.3, R2.2, R3.1, R4.1, U1.6 (VBAT), U1.8 (VDD), U1.9 (BS1)
CHARGE_LED: D1.1 (K), J4.2, J5.11
D/C: JP3.2 (B), R3.2, U1.13 (D/~C)
GND: C1.2, C4.2, C5.2, C6.2, C7.2, C16.2, J2.6 (VSS), J2.10 (SHIELD), J3.1, J4.6, J5.1, JP3.1 (A), R1.2, SW1.1, U1.1 (GND), U1.7 (VSS), U1.10 (BS2), U1.11 (~CS), U1.14 (R/~W), U1.15 (E/~RD), U1.19 (D3), U1.20 (D4), U1.21 (D5), U1.22 (D6), U1.23 (D7), U1.27 (VLSS), U1.28 (GND)
unnamed: D1.2 (A), R5.2
unnamed: C2.2, U1.5 (C1N)
unnamed: C2.1, U1.4 (C1P)
unnamed: C3.2, U1.3 (C2N)
unnamed: C3.1, U1.2 (C2P)
unnamed: R1.1, U1.24 (IREF)
unnamed: C1.1, U1.26 (VCC)
unnamed: C5.1, U1.25 (VCOMH)
POWER_BTN: J4.5, J5.2, SW1.2
RESET: C7.1, R2.1, U1.12 (~RESET)
SCL: J3.4, J5.9, U1.16 (D0/SCK)
SDA: J3.3, J5.10, U1.17 (D1/MOSI), U1.18 (D2)
SD_CIPO: J2.7 (DAT0/SDO), J5.8
SD_COPI: J2.3 (CMD/SDI), J5.6
SD_SCK: J2.5 (CLK/SCK), J5.7
SD_~CS: J2.2 (DAT3/CD), J5.5, R4.2
SD_~DET: J2.9 (~DET), J5.4
VUSB: J4.1, J5.12, R5.1

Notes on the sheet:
7-Bit unshifted I²C address: 0x3D
BS1 is pulled HIGH and BS2 is pulled LOW for permanent I²C mode.
0.66" OLED
To Membrane Overlay
I²C PTH
To Mainboard
Charging Indicator
microSD

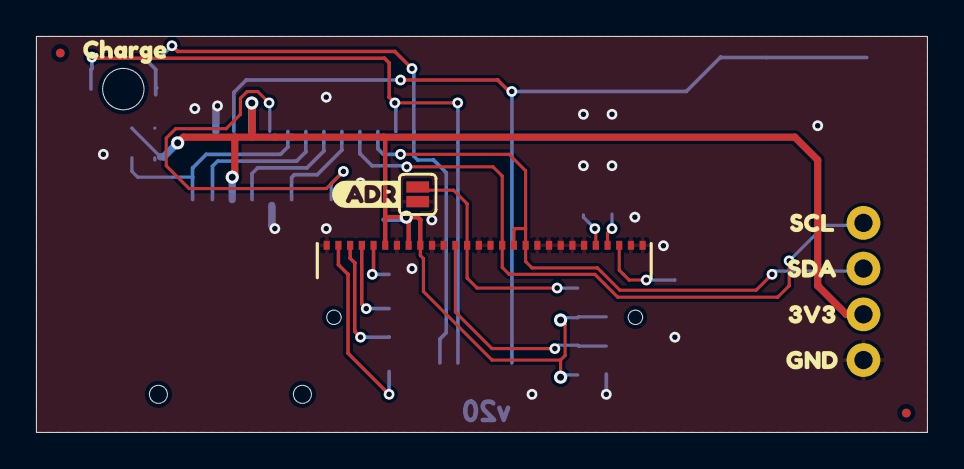
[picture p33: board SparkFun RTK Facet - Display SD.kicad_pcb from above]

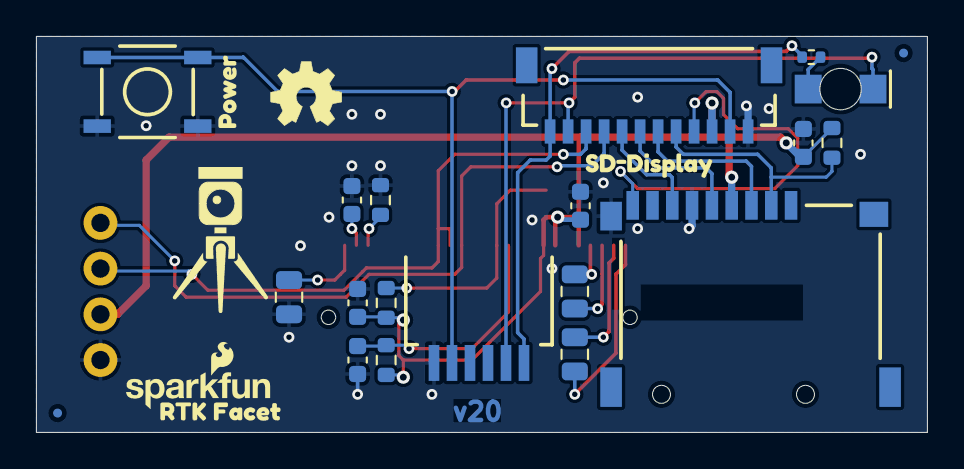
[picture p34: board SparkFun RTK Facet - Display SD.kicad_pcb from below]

Board: 2 copper layers, 49.5 x 22.0 mm, 37 parts (26 on the bottom side), 22 nets.

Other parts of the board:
Ref**: Val**; SparkFun_RTK_20mm
Ref**#2: Val**; OSHW_Logo_4mm
kibuzzard-66E8FA3C: G***; kibuzzard-66E8FA3C
kibuzzard-66E8FA6A: G***; kibuzzard-66E8FA6A
kibuzzard-66E8FA6F: G***; kibuzzard-66E8FA6F
kibuzzard-66E8FA7A: G***; kibuzzard-66E8FA7A
kibuzzard-66E8FA21: G***; kibuzzard-66E8FA21
kibuzzard-66E8FA52: G***; kibuzzard-66E8FA52
kibuzzard-66E8FA75: G***; kibuzzard-66E8FA75
kibuzzard-66E8FB1B: G***; kibuzzard-66E8FB1B
kibuzzard-66E8FB47: G***; kibuzzard-66E8FB47

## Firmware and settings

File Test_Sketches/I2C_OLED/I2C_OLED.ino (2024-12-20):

/*
  SparkFun RTK Facet mosaic Test Sketch

  This sketch can be used to test I2C / OLED connectivity:
  * The micro OLED on the Display Board
  * A micro OLED connected to the Connector Board Data connector (TX = SCL, RX = SDA)
  * A micro OLED connected to the Connector Board Qwiic connector
  * A micro OLED connected to the Main Board Qwiic connector

  Select ESP32 Wrover Module as the board

  License: MIT. Please see LICENSE.md for more details

  ESP32-WROVER-E Pin Allocations:
  D0  : Boot
  D1  : Serial TX (CH340 RX)
  D2  : Mux A
  D3  : Serial RX (CH340 TX)
  D4  : Serial1 RX - Connected to mosaic-X5 COM4 TX
  D5  : N/C
  D12 : Mux B
  D13 : Serial2 RX - Connected to mosaic-X5 COM1 TX
  D14 : Serial2 TX - Connected to mosaic-X5 COM1 RX
  D15 : SD Card detect. Low indicates card is present. Also disables debug during boot
  D16 : N/A
  D17 : N/A
  D18 : GNSS Event - Connected to mosaic-X5 EventB
  D19 : Charger STAT2
  D21 : I2C SDA
  D22 : I2C SCL
  D23 : mosaic On Off
  D25 : Serial1 TX - Connected to mosaic-X5 COM4 RX
  D26 : DAC (via Mux)
  D27 : Peripheral Power Control
  D32 : Power Sense & Control
  D33 : Fast Off
  A34 : Charger STAT1 - Charge LED
  A35 : Board Detect (2.72V)
  A36 : mosaic Ready
  A39 : ADC (via Mux)

  NMEA / Data Multiplexer:
  B A : Mode
  0 0 : mosaic-X5 COM3 TX & RX
  0 1 : PPS & EventA
  1 0 : SCL & SDA
  1 1 : DAC (26) & ADC (39)

*/

//=-=-=-=-=-=-=-=-=-=-=-=-=-=-=-=-=-=-=-=-=-=-=-=-=-=-=-=-=-=-=-=-=-=-=-=-=-=-=-=-=-=-=-=-=
// Hardware specifics for the SparkFun RTK mosaic

#include <driver/uart.h>      //Required for uart_set_rx_full_threshold() on cores <v2.0.5
const int serialTxPin = 14;
const int serialRxPin = 13;
HardwareSerial serialGNSS(2); // UART2: TX on 14, RX on 13. Connected to mosaic-X5 COM1
const int lbandRxPin = 4;
const int lbandTxPin = 25;
HardwareSerial lbandSerial(1);  // UART1: TX on 25, RX on 4. Connected to mosaic-X5 COM4

const int muxA = 2; // 74HC4052 Multiplexer
const int muxB = 12; // 74HC4052 Multiplexer
const int sdDetect = 15; // microSD card detect. Low = card present
const int chargeSTAT2 = 19; // Connected to charger STAT2
const int SDA_1 = 21;
const int SCL_1 = 22;
const int mosaicOnOff = 23; // Drive low for >= 50ms to toggle from on to off and vice versa
const int muxDAC = 26; // Analog out - via multiplexer
const int peripheralPower = 27; // Pull high to enable power for the mosaic-X5, microSD, multiplexer and main board Qwiic connector
const int powerControl = 32; // Default to input pull-up. Low indicates power button is being held
const int fastOff = 33; // Default to input. Change to output and drive high for fast power off
const int chargeSTAT1 = 34; // Connected to charger STAT1
const int boardDetect = 35; // Board detect / ID voltage
const int mosaicReady = 36; // High when module is ready
const int muxADC = 39; // Analog in - via multiplexer

//=-=-=-=-=-=-=-=-=-=-=-=-=-=-=-=-=-=-=-=-=-=-=-=-=-=-=-=-=-=-=-=-=-=-=-=-=-=-=-=-=-=-=-=-=

#include <SparkFun_Qwiic_OLED.h> //http://librarymanager/All#SparkFun_Qwiic_OLED
QwiicMicroOLED myOLED; // 64x48

TwoWire I2C_1 = TwoWire(1);

int width;
int height;

void setup()
{
  // Init pins
  pinMode(muxA, OUTPUT); // Set Mux to I2C - test Data Connector with a micro OLED
  digitalWrite(muxA, LOW);
  pinMode(muxB, OUTPUT);
  digitalWrite(muxB, HIGH);

  pinMode(mosaicOnOff, OUTPUT); // Pull On/Off high
  digitalWrite(mosaicOnOff, HIGH);

  pinMode(powerControl, INPUT_PULLUP);
  pinMode(fastOff, INPUT);

  pinMode(mosaicReady, INPUT);

  pinMode(serialTxPin, INPUT_PULLUP); // Not needed. Pull up
  pinMode(lbandTxPin, INPUT_PULLUP); // Not needed. Pull up

  pinMode(peripheralPower, OUTPUT); // Now enable power for the mosaic-X5
  digitalWrite(peripheralPower, HIGH);


  delay(1000);

  Serial.begin(115200);
  Serial.println("SparkFun RTK mosaic - Test Sketch");

  I2C_1.begin((int)SDA_1, (int)SCL_1, (uint32_t)400000);

  // Initalize the OLED device and related graphics system
  if (myOLED.begin(I2C_1) == false)
  {
      Serial.println("OLED begin failed. Freezing...");
      while (true)
          ;
  }

  width = myOLED.getWidth();
  height = myOLED.getHeight();
}

void loop()
{
    pixelExample();
    lineExample();
    shapeExample();
}

void pixelExample()
{
    myOLED.erase();
    for (int i = 0; i < 512; i++)
    {
        myOLED.pixel(random(width), random(height));
        myOLED.display();
        delay(10);
    }
}

void lineExample()
{
    int middleX = width / 2;
    int middleY = height / 2;
    int xEnd, yEnd;
    int lineWidth = min(middleX, middleY);

    myOLED.erase();
    int deg;

    for (int i = 0; i < 3; i++)
    {

        for (deg = 0; deg < 360; deg += 15)
        {

            xEnd = lineWidth * cos(deg * PI / 180.0);
            yEnd = lineWidth * sin(deg * PI / 180.0);

            myOLED.line(middleX, middleY, middleX + xEnd, middleY + yEnd);
            myOLED.display();
            delay(10);
        }

        for (deg = 0; deg < 360; deg += 15)
        {

            xEnd = lineWidth * cos(deg * PI / 180.0);
            yEnd = lineWidth * sin(deg * PI / 180.0);

            myOLED.line(middleX, middleY, middleX + xEnd, middleY + yEnd, 0);
            myOLED.display();
            delay(10);
        }
    }
}

void shapeExample()
{
    // Silly pong demo. It takes a lot of work to fake pong...
    int paddleW = 3;  // Paddle width
    int paddleH = 15; // Paddle height

    // Paddle 0 (left) position coordinates
    int paddle0_Y = (height / 2) - (paddleH / 2);
    int paddle0_X = 2;

    // Paddle 1 (right) position coordinates
    int paddle1_Y = (height / 2) - (paddleH / 2);
    int paddle1_X = width - 3 - paddleW;
    int ball_rad = 4; // Ball radius

    // Ball position coordinates
    int ball_X = paddle0_X + paddleW + ball_rad;
    int ball_Y = random(1 + ball_rad, height - ball_rad); // paddle0_Y + ball_rad;
    int ballVelocityX = 1;                                // Ball left/right velocity
    int ballVelocityY = 1;                                // Ball up/down velocity
    int paddle0Velocity = -1;                             // Paddle 0 velocity
    int paddle1Velocity = 1;                              // Paddle 1 velocity

    // Draw the Pong Field
    myOLED.erase();

    // Draw an outline of the screen:
    myOLED.rectangle(0, 0, width - 1, height);

    // Draw the center line
    myOLED.rectangleFill(width / 2 - 1, 0, 2, height);

    bool firstLoop = true;

    while ((ball_X - ball_rad > 1) && (ball_X + ball_rad < width - 2))
    {

        if (!firstLoop)
        {

            // Erase the old ball. In XOR mode, so just draw old values again!
            // Draw the Paddles:
            myOLED.rectangleFill(paddle0_X, paddle0_Y, paddleW, paddleH);
            myOLED.rectangleFill(paddle1_X, paddle1_Y, paddleW, paddleH);
            // Draw the ball: - use rect - xor and circle fails b/c of circle algorithm overdraws
            myOLED.rectangleFill(ball_X, ball_Y, ball_rad, ball_rad);
        }
        // Increment ball's position
        ball_X += ballVelocityX;
        ball_Y += ballVelocityY;

        // Check if the ball is colliding with the left paddle
        if (ball_X - ball_rad < paddle0_X + paddleW)
        {

            // Check if ball is within paddle's height
            if ((ball_Y > paddle0_Y) && (ball_Y < paddle0_Y + paddleH))
            {

                ball_X++;                       // Move ball over one to the right
                ballVelocityX = -ballVelocityX; // Change velocity
            }
        }

        // Check if the ball hit the right paddle
        if (ball_X + ball_rad > paddle1_X)
        {

            // Check if ball is within paddle's height
            if ((ball_Y > paddle1_Y) && (ball_Y < paddle1_Y + paddleH))
            {

                ball_X--;                       // Move ball over one to the left
                ballVelocityX = -ballVelocityX; // change velocity
            }
        }

        // Check if the ball hit the top or bottom
        if ((ball_Y <= 1) || (ball_Y >= (height - ball_rad - 1)))
        {

            // Change up/down velocity direction
            ballVelocityY = -ballVelocityY;
        }

        // Move the paddles up and down
        paddle0_Y += paddle0Velocity;
        paddle1_Y += paddle1Velocity;

        // Change paddle 0's direction if it hit top/bottom
        if ((paddle0_Y <= 1) || (paddle0_Y > height - 2 - paddleH))
            paddle0Velocity = -paddle0Velocity;

        // Change paddle 1's direction if it hit top/bottom
        if ((paddle1_Y <= 1) || (paddle1_Y > height - 2 - paddleH))
            paddle1Velocity = -paddle1Velocity;

        // Draw the Paddles:
        myOLED.rectangleFill(paddle0_X, paddle0_Y, paddleW, paddleH);
        myOLED.rectangleFill(paddle1_X, paddle1_Y, paddleW, paddleH);

        // Draw the ball:
        myOLED.rectangleFill(ball_X, ball_Y, ball_rad, ball_rad);

        // Actually draw everything on the screen:
        myOLED.display();

        // Once the first loop is done, switch to XOR mode. So we just update our
        // moving parts
        if (firstLoop)
        {
            firstLoop = false;
            myOLED.setDrawMode(grROPXOR);
        }

        delay(25); // Delay for visibility
    }
    delay(1000);
    myOLED.setDrawMode(grROPCopy);
}

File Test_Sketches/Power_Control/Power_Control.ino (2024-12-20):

/*
  SparkFun RTK Facet mosaic Test Sketch

  This sketch will turn the board off via the Fast Off pin if Power Control is not low at start-up.
  It also monitors the Power Control pin and will turn the soft power circuit off if the button is
  held for 2 seconds.
  It also displays information from the fuel gauge and the status of the charger STAT pins.

  To start the test, push and hold the power button for two seconds.
  The code will power-off if the button isn't held for ~1s at startup.
  The code will power-off when the button is held for shutDownButtonTime.
  
  Be careful when opening / closing a serial monitor / terminal emulator. This can cause a reset.

  Select ESP32 Wrover Module as the board

  License: MIT. Please see LICENSE.md for more details

  ESP32-WROVER-E Pin Allocations:
  D0  : Boot
  D1  : Serial TX (CH340 RX)
  D2  : Mux A
  D3  : Serial RX (CH340 TX)
  D4  : Serial1 RX - Connected to mosaic-X5 COM4 TX
  D5  : N/C
  D12 : Mux B
  D13 : Serial2 RX - Connected to mosaic-X5 COM1 TX
  D14 : Serial2 TX - Connected to mosaic-X5 COM1 RX
  D15 : SD Card detect. Low indicates card is present. Also disables debug during boot
  D16 : N/A
  D17 : N/A
  D18 : GNSS Event - Connected to mosaic-X5 EventB
  D19 : Charger STAT2
  D21 : I2C SDA
  D22 : I2C SCL
  D23 : mosaic On Off
  D25 : Serial1 TX - Connected to mosaic-X5 COM4 RX
  D26 : DAC (via Mux)
  D27 : Peripheral Power Control
  D32 : Power Sense & Control
  D33 : Fast Off
  A34 : Charger STAT1 - Charge LED
  A35 : Board Detect (2.72V)
  A36 : mosaic Ready
  A39 : ADC (via Mux)

  NMEA / Data Multiplexer:
  B A : Mode
  0 0 : mosaic-X5 COM3 TX & RX
  0 1 : PPS & EventA
  1 0 : SCL & SDA
  1 1 : DAC (26) & ADC (39)

*/

#include <Wire.h> // Needed for I2C

TwoWire I2C_1 = TwoWire(1);

#include <SparkFun_MAX1704x_Fuel_Gauge_Arduino_Library.h> // Click here to get the library: http://librarymanager/All#SparkFun_MAX1704x_Fuel_Gauge_Arduino_Library

SFE_MAX1704X lipo(MAX1704X_MAX17048); // Create a MAX17048

bool powerDownRequested = false;

//=-=-=-=-=-=-=-=-=-=-=-=-=-=-=-=-=-=-=-=-=-=-=-=-=-=-=-=-=-=-=-=-=-=-=-=-=-=-=-=-=-=-=-=-=
// Hardware specifics for the SparkFun RTK mosaic

#include <driver/uart.h>      //Required for uart_set_rx_full_threshold() on cores <v2.0.5
const int serialTxPin = 14;
const int serialRxPin = 13;
HardwareSerial serialGNSS(2); // UART2: TX on 14, RX on 13. Connected to mosaic-X5 COM1
const int lbandRxPin = 4;
const int lbandTxPin = 25;
HardwareSerial lbandSerial(1);  // UART1: TX on 25, RX on 4. Connected to mosaic-X5 COM4

#define DEBUG_GNSS 1 // Change to 0 to disable GNSS serial debug

const int muxA = 2; // 74HC4052 Multiplexer
const int muxB = 12; // 74HC4052 Multiplexer
const int sdDetect = 15; // microSD card detect. Low = card present
const int chargeSTAT2 = 19; // Connected to charger STAT2
const int SDA_1 = 21;
const int SCL_1 = 22;
const int mosaicOnOff = 23; // Drive low for >= 50ms to toggle from on to off and vice versa
const int muxDAC = 26; // Analog out - via multiplexer
const int peripheralPower = 27; // Pull high to enable power for the mosaic-X5, microSD, multiplexer and main board Qwiic connector
const int powerControl = 32; // Default to input pull-up. Low indicates power button is being held
const int fastOff = 33; // Default to input. Change to output and drive high for fast power off
const int chargeSTAT1 = 34; // Connected to charger STAT1
const int boardDetect = 35; // Board detect / ID voltage
const int mosaicReady = 36; // High when module is ready
const int muxADC = 39; // Analog in - via multiplexer

//=-=-=-=-=-=-=-=-=-=-=-=-=-=-=-=-=-=-=-=-=-=-=-=-=-=-=-=-=-=-=-=-=-=-=-=-=-=-=-=-=-=-=-=-=

void flushRX(unsigned long timeout = 0); // Header
void flushRX(unsigned long timeout)
{
  if (timeout > 0)
  {
    unsigned long startTime = millis();
    while (millis() < (startTime + timeout))
      if (serialGNSS.available())
      {
        uint8_t c = serialGNSS.read();
        if (DEBUG_GNSS)
          Serial.write(c);
      }
  }
  else
  {
    while (serialGNSS.available())
    {
      uint8_t c = serialGNSS.read();
      if (DEBUG_GNSS)
        Serial.write(c);
    }
  }
}

bool sendWithResponse(const char *message, const char *reply, unsigned long timeout = 1000, unsigned long wait = 100); // Header
bool sendWithResponse(const char *message, const char *reply, unsigned long timeout, unsigned long wait)
{
  if (strlen(reply) == 0) // Reply can't be zero-length
    return false;

  if (strlen(message) > 0)
  {
    serialGNSS.write(message, strlen(message)); // Send the message
    if (DEBUG_GNSS)
      Serial.write(message, strlen(message));
  }

  unsigned long startTime = millis();
  size_t replySeen = 0;
  bool keepGoing = true;

  while ((keepGoing) && (replySeen < strlen(reply))) // While not timed out and reply not seen
  {
    if (serialGNSS.available()) // If a char is available
    {
      uint8_t chr = serialGNSS.read(); // Read it
      if (chr == *(reply + replySeen)) // Is it a char from reply?
        replySeen++;
      else
        replySeen = 0; // Reset replySeen on an unexpected char
      if (DEBUG_GNSS)
        Serial.write(chr);
    }

    // If the reply has started to arrive at the timeout, allow extra time
    if (millis() > (startTime + timeout)) // Have we timed out?
      if (replySeen == 0)                 // If replySeen is zero, don't keepGoing
        keepGoing = false;

    if (millis() > (startTime + timeout + wait)) // Have we really timed out?
      keepGoing = false;                         // Don't keepGoing
  }

  if (replySeen == strlen(reply)) // If the reply was seen
  {
    flushRX(wait); // wait and flush
    return true;
  }

  return false;
}

//=-=-=-=-=-=-=-=-=-=-=-=-=-=-=-=-=-=-=-=-=-=-=-=-=-=-=-=-=-=-=-=-=-=-=-=-=-=-=-=-=-=-=-=-=
// Put the X5 into standby

bool x5Standby(int reattempts) // Zero reattempts == one attempt
{
  if (reattempts == 0)
    return sendWithResponse("epwm,Standby\n\r", "PowerMode");

  int attempt = 0;

  while (!sendWithResponse("epwm,Standby\n\r", "PowerMode") && (attempt <= reattempts))
  {
    if (attempt < reattempts) // Don't send the escape on the final try
    {
      Serial.println(F("No response from mosaic-X5. Retrying - with escape sequence..."));
      sendWithResponse("SSSSSSSSSSSSSSSSSSSS\n\r", "COM1>"); // Send escape sequence
    }
    attempt++;
  }

  return (attempt <= reattempts);
}

//=-=-=-=-=-=-=-=-=-=-=-=-=-=-=-=-=-=-=-=-=-=-=-=-=-=-=-=-=-=-=-=-=-=-=-=-=-=-=-=-=-=-=-=-=
// Power Down

void powerDown(void)
{
  // Tell the X5 to standby
  x5Standby(1); // Allow one retry

  delay(100);

  pinMode(peripheralPower, OUTPUT); // Power off the X5
  digitalWrite(peripheralPower, LOW);
  
  pinMode(fastOff, OUTPUT); // Power off the soft power switch
  digitalWrite(fastOff, HIGH);

  while(1);
}

//=-=-=-=-=-=-=-=-=-=-=-=-=-=-=-=-=-=-=-=-=-=-=-=-=-=-=-=-=-=-=-=-=-=-=-=-=-=-=-=-=-=-=-=-=
// Buttons - Interrupt driven and debounce
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

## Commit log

2024-01-11 Schematic updates
    [GNSS.kicad_sch, Power.kicad_sch, SparkFun_RTK_Facet_mosaic.kicad_pcb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]
2024-01-15 Ready for airwire review
    [GNSS.kicad_sch, Power.kicad_sch, SparkFun_RTK_Facet_mosaic.kicad_pcb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]
2024-01-16 Work in progress...
    [GNSS.kicad_sch, SparkFun_RTK_Facet_mosaic.kicad_pcb, SparkFun_RTK_Facet_mosaic.kicad_sch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]
2024-01-17 With Buzzard text
    [SparkFun_RTK_Facet_mosaic.kicad_pcb]
2024-01-17 Nudge things on USB schematic
    [USB.kicad_sch]
2024-01-18 Do over with RSP32 Pico Mini - routed
    [GNSS.kicad_sch, Power.kicad_sch, SparkFun_RTK_Facet_mosaic.kicad_pcb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]
2024-01-18 Switching back to the WROVER - routed
    [GNSS.kicad_sch, Power.kicad_sch, SparkFun_RTK_Facet_mosaic.kicad_pcb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]
2024-01-19 Add route out text
    [SparkFun_RTK_Facet_mosaic.kicad_pcb]
2024-01-19 Update schematic - rotate pages
2024-01-22 Panelized with corrected FPC paste
    [SparkFun_RTK_Facet_mosaic.kicad_pcb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]
2024-01-22 Add missing PROD_IDs
    [SparkFun_RTK_Facet_mosaic.kicad_pcb, SparkFun_RTK_Facet_mosaic.kicad_sch]
2024-01-22 Add missing PROD_ID
    [SparkFun_RTK_Facet_mosaic.kicad_sch]
2024-01-22 Add extra Test Points
    [GNSS.kicad_sch, Power.kicad_sch, SparkFun_RTK_Facet_mosaic.kicad_pcb]
2024-01-23 Final tweaks
    [Power.kicad_sch, SparkFun_RTK_Facet_mosaic.kicad_pcb, SparkFun_RTK_Facet_mosaic.kicad_sch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]
2024-01-23 Add RFCMF1220100M4T value
    [SparkFun_RTK_Facet_mosaic.kicad_pcb]
2024-03-06 Pull up unused TX pins, just in case
2024-05-01 v1.1 routed
    [GNSS.kicad_sch, Power.kicad_sch, SparkFun_RTK_Facet_mosaic.kicad_pcb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]
2024-05-02 V1.1 Panelized
    [GNSS.kicad_sch, Power.kicad_sch, SparkFun_RTK_Facet_mosaic.kicad_pcb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]
2024-05-03 v1.1 Final Polish
    [GNSS.kicad_sch, Power.kicad_sch, SparkFun_RTK_Facet_mosaic.kicad_pcb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]
2024-10-08 v1.2 routed
    [GNSS.kicad_sch, Power.kicad_sch, SparkFun_RTK_Facet_mosaic.kicad_pcb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]
2024-10-08 v1.2 Panelized
    [Power.kicad_sch, SparkFun_RTK_Facet_mosaic.kicad_pcb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]
2024-10-14 Add SD_DET and 1A regulator
    [GNSS.kicad_sch, Power.kicad_sch, SparkFun_RTK_Facet_mosaic.kicad_pcb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]
2024-10-15 Add JST PROD_IDs. Update AP7361C regulator
    [Power.kicad_sch, SparkFun_RTK_Facet_mosaic.kicad_pcb, SparkFun_RTK_Facet_mosaic.kicad_sch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]
2025-02-14 Add display and connector boards
    [SparkFun RTK Facet - Display SD.kicad_pcb, SparkFun RTK Facet - Display SD.kicad_sch, SparkFun RTK Facet - External Connector.kicad_pcb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]
2025-02-21 Add board files
    Add schematics for display and connector boards
    Rework file links
2025-09-12 Update footprints
    Updates the 3D model file path for the footprints
    [SparkFun RTK Facet - External Connector.kicad_pcb, SparkFun_RTK_Facet_mosaic.kicad_pcb]

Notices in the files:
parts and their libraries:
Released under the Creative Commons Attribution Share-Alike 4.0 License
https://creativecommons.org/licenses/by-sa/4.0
